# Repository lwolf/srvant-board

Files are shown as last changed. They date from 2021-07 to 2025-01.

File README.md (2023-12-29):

# srvant-board

| :warning: WARNING          |
|:---------------------------|
| This is a work-in-progress. No final board have been produced yet. Any part of the schematic and/or PCB could be wrong.|

Design of the carrier board for the Raspberry Pi CM4. The main distinction from existing boards is the presence of the 
BMC (Baseboard Management Controller) which supposed to monitor and control the HOST, allowing the board to act as a real "server".

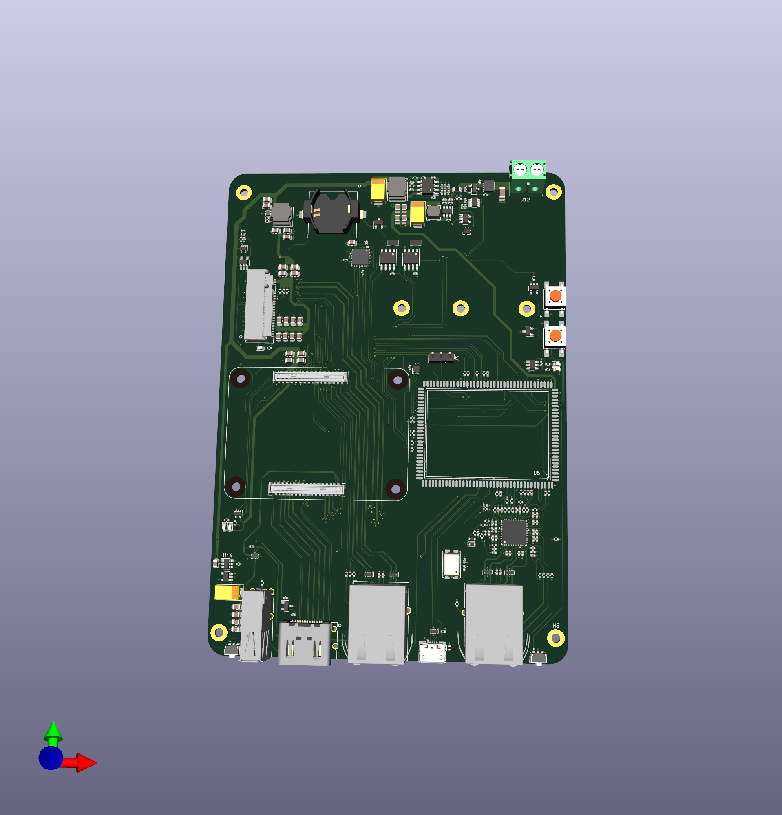
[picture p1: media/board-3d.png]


## Highlevel design / idea:

BMC using lots of GPIO controls the HOST: power cycle, terminal access, switches USB into OTG for flushing.
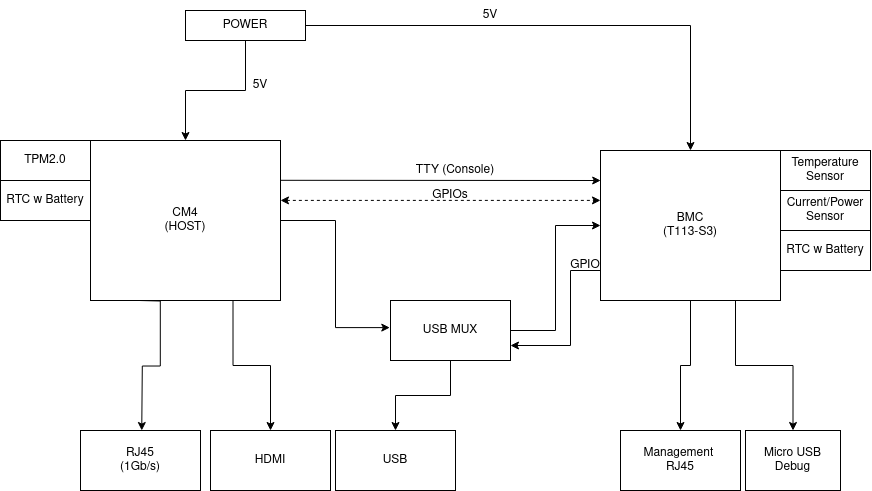
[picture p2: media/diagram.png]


* CM4 (HOST) features:
  * 1Gb/s ethernet
  * HDMI
  * 1 USB
  * PCIe exposed as M.2 socket to connect nvme drive
  * TPM2.0 (OPTIGA™ TPM SLB 9670)
  * RTC with battery
* BMC features:
  * Always ON
  * 1Gb/s management port
  * USB port for debug
  * USB connection to the HOST for flushing
  * I2C connection to the HOST for additional metrics
  * TTY connection to HOST for SOL (Serial over LAN)
  * measures Current/Power of the board
  * measures Temperature of the board
  * controls FAN (not available in the PoC)

BMC is based on the Allwinner T113 S3 SoM [link to aliexpress](https://www.aliexpress.com/item/1005005389129193.html).

### Power

THere are separate 5v rails for host and BMC. The host one is based on AP64501SP (5V 5A), while BMC is based on AP63205WU (5V 2A).
BMC is always on. Host is being powered either by a signal from BMC or by shortening a jumper.

Main power goes through the shunt resistor connected to the power sensor (INA219A). The value is available to BMC using i2c bus.

### Connectors

#### HOST
Host has a following connectors:
* Ethernet
* HDMI
* USB
* M.2 socket M for nvme disk

#### BMC
BMC has a following connectors:
* Ethernet (1GB/s)
* MicroUSB (debug)

### USB

There is a connection between BMC and HOST using USB to allow flushing the HOST remotely.
Since CM4 has only a single usb line, it is connected to the MUX (FSUSB42MUX) 
in a similar way it is done in the CM4IO board, but instead of switching client mode to microUSB, it goes to BMC.

### RTC

RTC is based on PCF85063AT chip. There are two of them, one for each CPU.
Even though t133-s3 has on-board RTC, it is not exposed from the SOM and reference schematic uses external one.
Both chips are powered by 3.3v coming from BMC and coin cell battery.

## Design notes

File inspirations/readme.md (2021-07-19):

olinuxino:
    https://github.com/OLIMEX/OLINUXINO

ttyMAY_linux_board:
    https://github.com/circuitvalley/ttyMAY_linux_board
    https://www.circuitvalley.com/2015/11/homemade-arm-board-running-linux-with.html
    https://www.circuitvalley.com/2015/11/linux-board-homemade-pcb-design-ddr3-schematic-altium.html
    https://www.circuitvalley.com/2015/11/linux-board-homemade-pcb-design-ddr3-schematic-altium.html

related projects:
https://github.com/mebs/CM4-NAS/
https://github.com/mfolejewski/MirkoPC

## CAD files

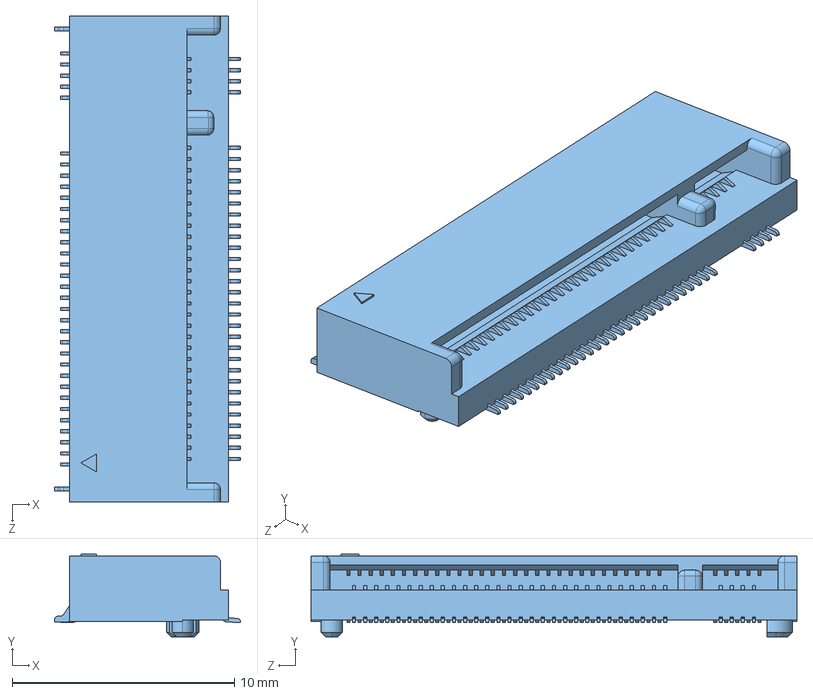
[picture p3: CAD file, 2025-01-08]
kicad/mk2/srvant-mk2/3D/MTSSD03-67MSW337.STEP
8.37 x 3.73 x 21.9 mm

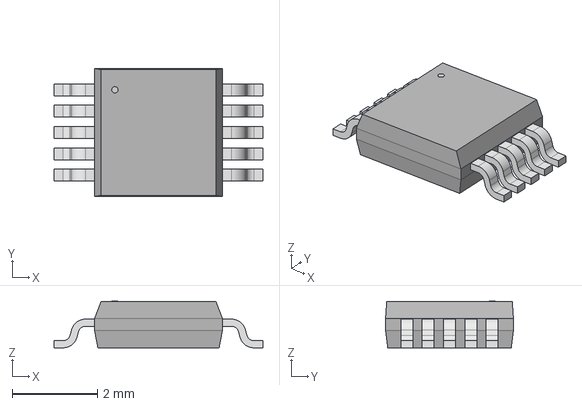
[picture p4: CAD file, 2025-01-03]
kicad/mk2/srvant-mk2/3D/FSUSB42MUX.step
4.90 x 3.00 x 1.09 mm

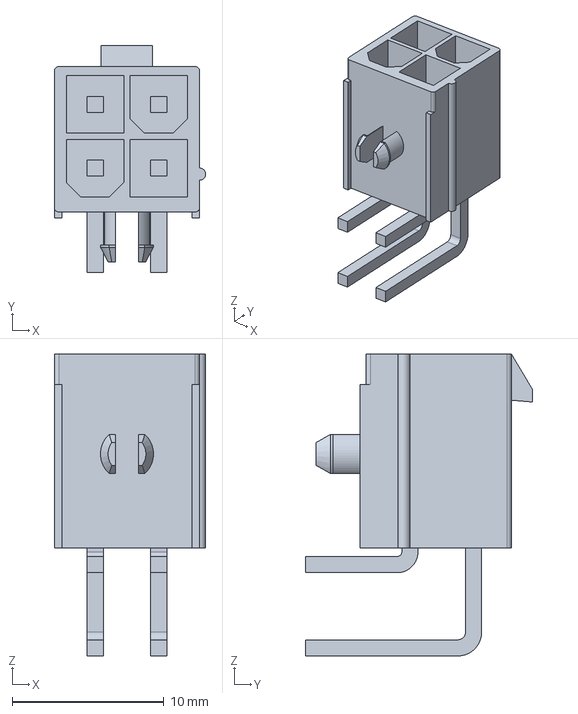
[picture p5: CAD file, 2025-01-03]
kicad/mk2/srvant-mk2/3D/molex_4pin_power.stp
10.0 x 15.0 x 19.9 mm

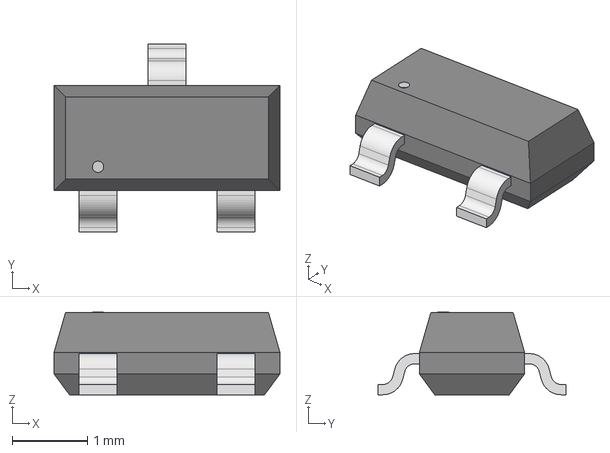
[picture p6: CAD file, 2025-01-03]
kicad/mk2/srvant-mk2/3D/SOT-23_DMP3098LQ_DIO.step
3.00 x 2.49 x 1.09 mm

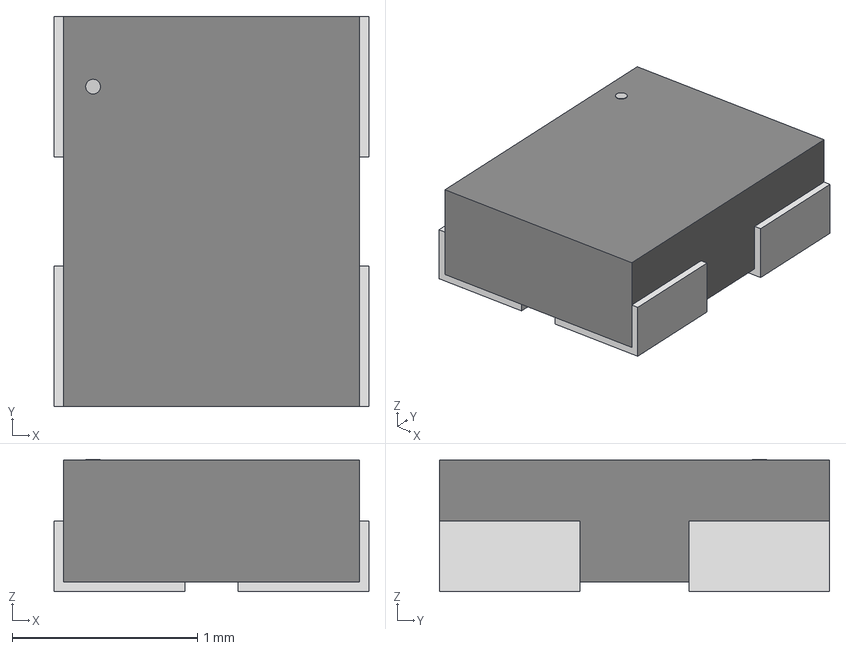
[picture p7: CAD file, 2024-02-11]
kicad/mk2/srvant-mk2/3D/25mhz_70x50quarz.step
1.70 x 2.11 x 0.714 mm

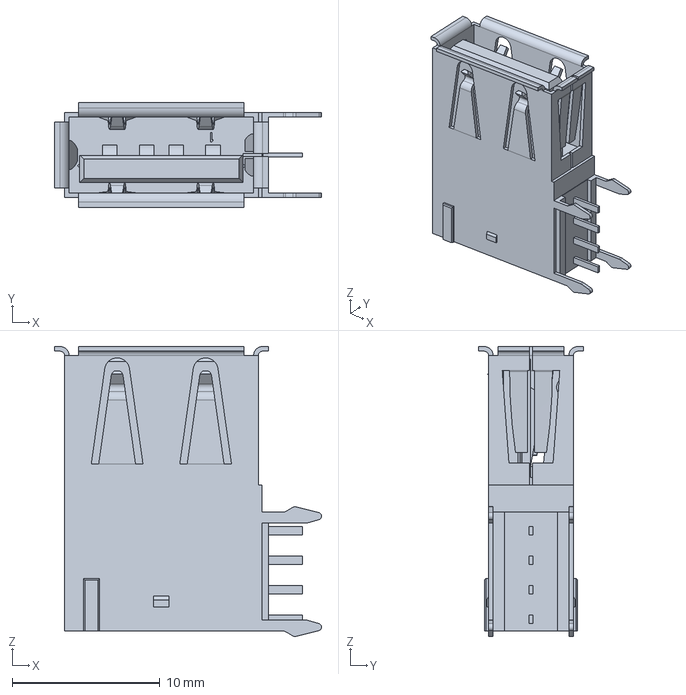
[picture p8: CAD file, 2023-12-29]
kicad/mk2/srvant-mk2/3D/usb-vertical-c-292336-1-b-3d.stp
18.1 x 7.12 x 19.7 mm

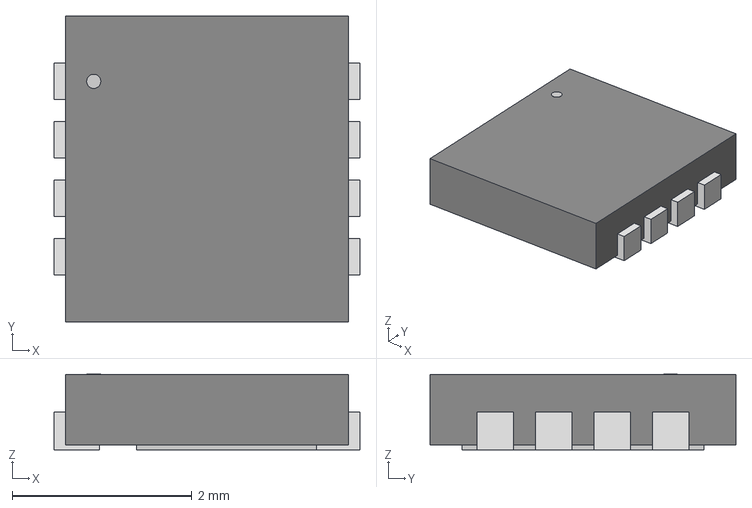
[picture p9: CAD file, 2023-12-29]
kicad/mk2/srvant-mk2/3D/POWERDI3333-8_UX_DIO.step
3.40 x 3.40 x 0.841 mm

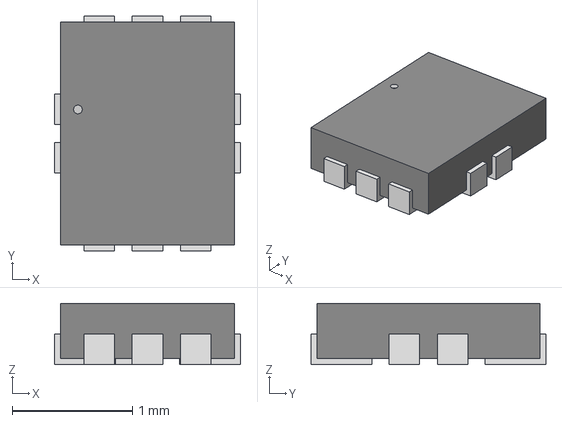
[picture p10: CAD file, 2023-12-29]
kicad/mk2/srvant-mk2/3D/usbmux_UQFN10_ONS.step
1.55 x 1.96 x 0.511 mm

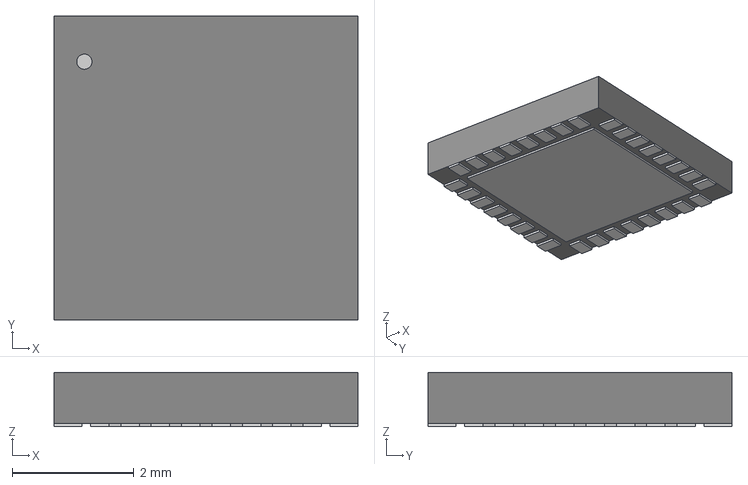
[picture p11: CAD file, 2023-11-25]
kicad/mk2/srvant-mk2/3D/QFN32_SLB9670VQ20FW785XTMA1_INF.step
5.00 x 5.00 x 0.892 mm

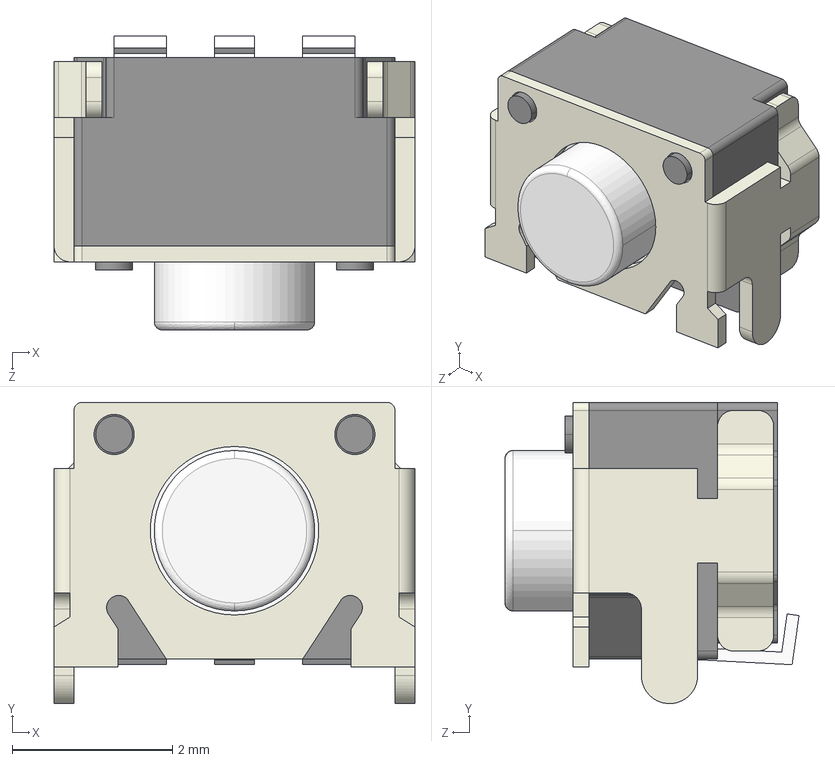
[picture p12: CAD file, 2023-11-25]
kicad/mk2/srvant-mk2/3D/button-TL3340AF160QG.step
4.50 x 3.76 x 3.67 mm

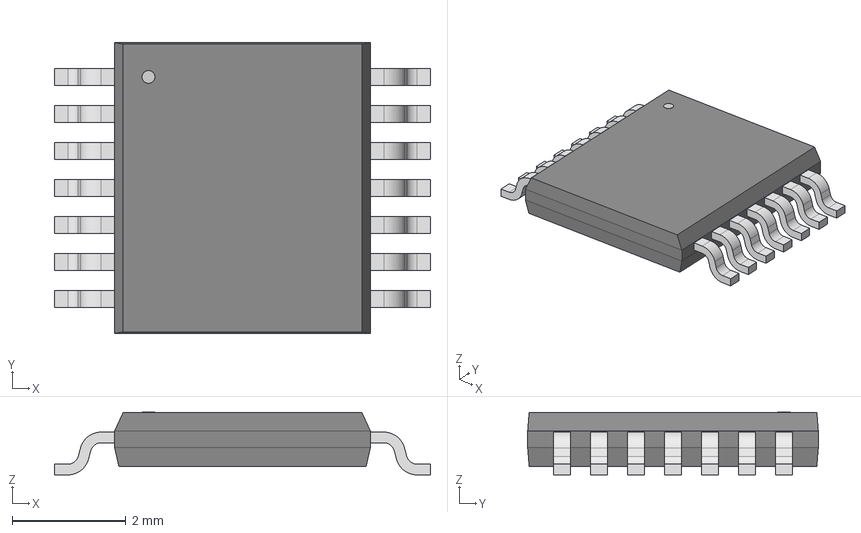
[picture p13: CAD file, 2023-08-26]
kicad/mk2/srvant-mk2/3D/SOT402-1_NEX.step
6.60 x 5.11 x 1.10 mm

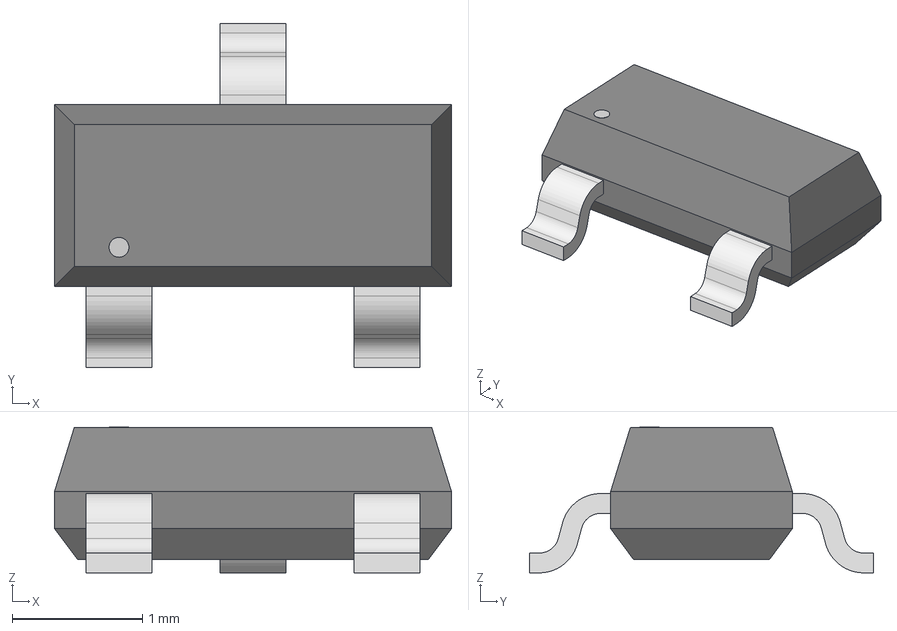
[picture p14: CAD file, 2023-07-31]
kicad/mk2/srvant-mk2/3D/SOT-23-3_1P4X3P040_ONS.step
3.05 x 2.64 x 1.12 mm

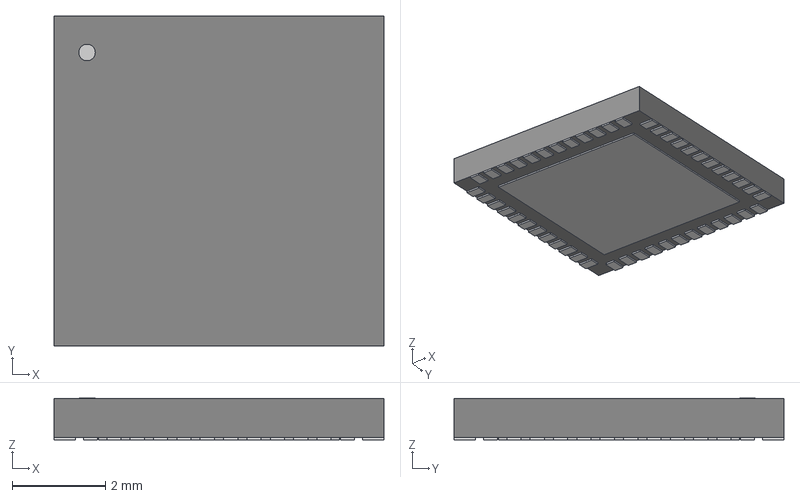
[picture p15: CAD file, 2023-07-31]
kicad/mk2/srvant-mk2/3D/QFN48_NX_MCH.step
7.06 x 7.06 x 0.892 mm

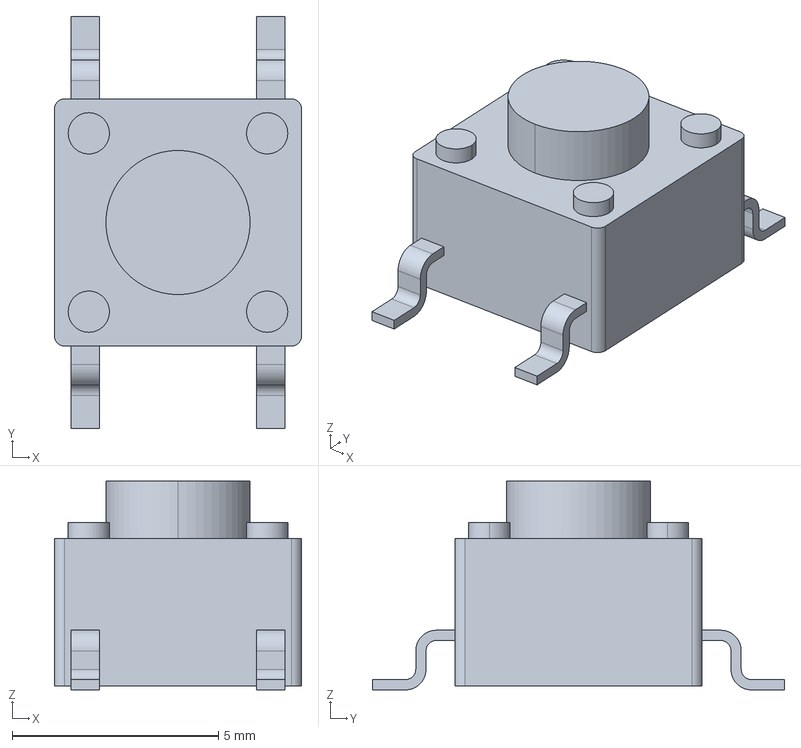
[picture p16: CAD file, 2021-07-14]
kicad/mk2/srvant-mk2/3D/button-c-1571563-4-v-3d.stp
6.00 x 10.0 x 5.07 mm

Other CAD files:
kicad/mk2/srvant-mk2/3D/RJ45-c-5-2337992-3-a-3d.stp
kicad/mk2/srvant-mk2/3D/TLV62585DRLR-DRL0006A.stp
kicad/mk2/srvant-mk2/3D/m2-2199230-5-b2-3d.stp

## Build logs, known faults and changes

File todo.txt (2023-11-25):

todo:
* calculate RShunt for the INA129
* [x] add RTC chip for RPI
* ETHERNET: 25M crystal or the clock from the CPU
* Do I want to add sdcard to BMC?

USB:
* [x] connect USB pins for OTG: nFault,DRV in usb (removed the power chip)
* [x] Do i need to keep BMC and HOST disconnected? (demux solves this)
* [X] connect USB_DEBUX_SELECT to GPIO on BMC
* [x] Since I don't use usb connector, I need to somehow emulate ID pin on BMC (yes, BMC_HOST_DEMUX_CONTROL)

---------
* [x] add a thermo sensors
* add FAN control ?
* [x] RTC for rpi
* NOR Flash?
* Fuse?
* [x] Drop usb hub
* [x] replace USB port with vertical one
* replace HDMI port with vertical one
* experiment with placement and form factor. is it possible/worth making 1U with 2 side placement
* [x] add RC filter to each bmc-host pin (only 0r for now
* [x] led for bmc power

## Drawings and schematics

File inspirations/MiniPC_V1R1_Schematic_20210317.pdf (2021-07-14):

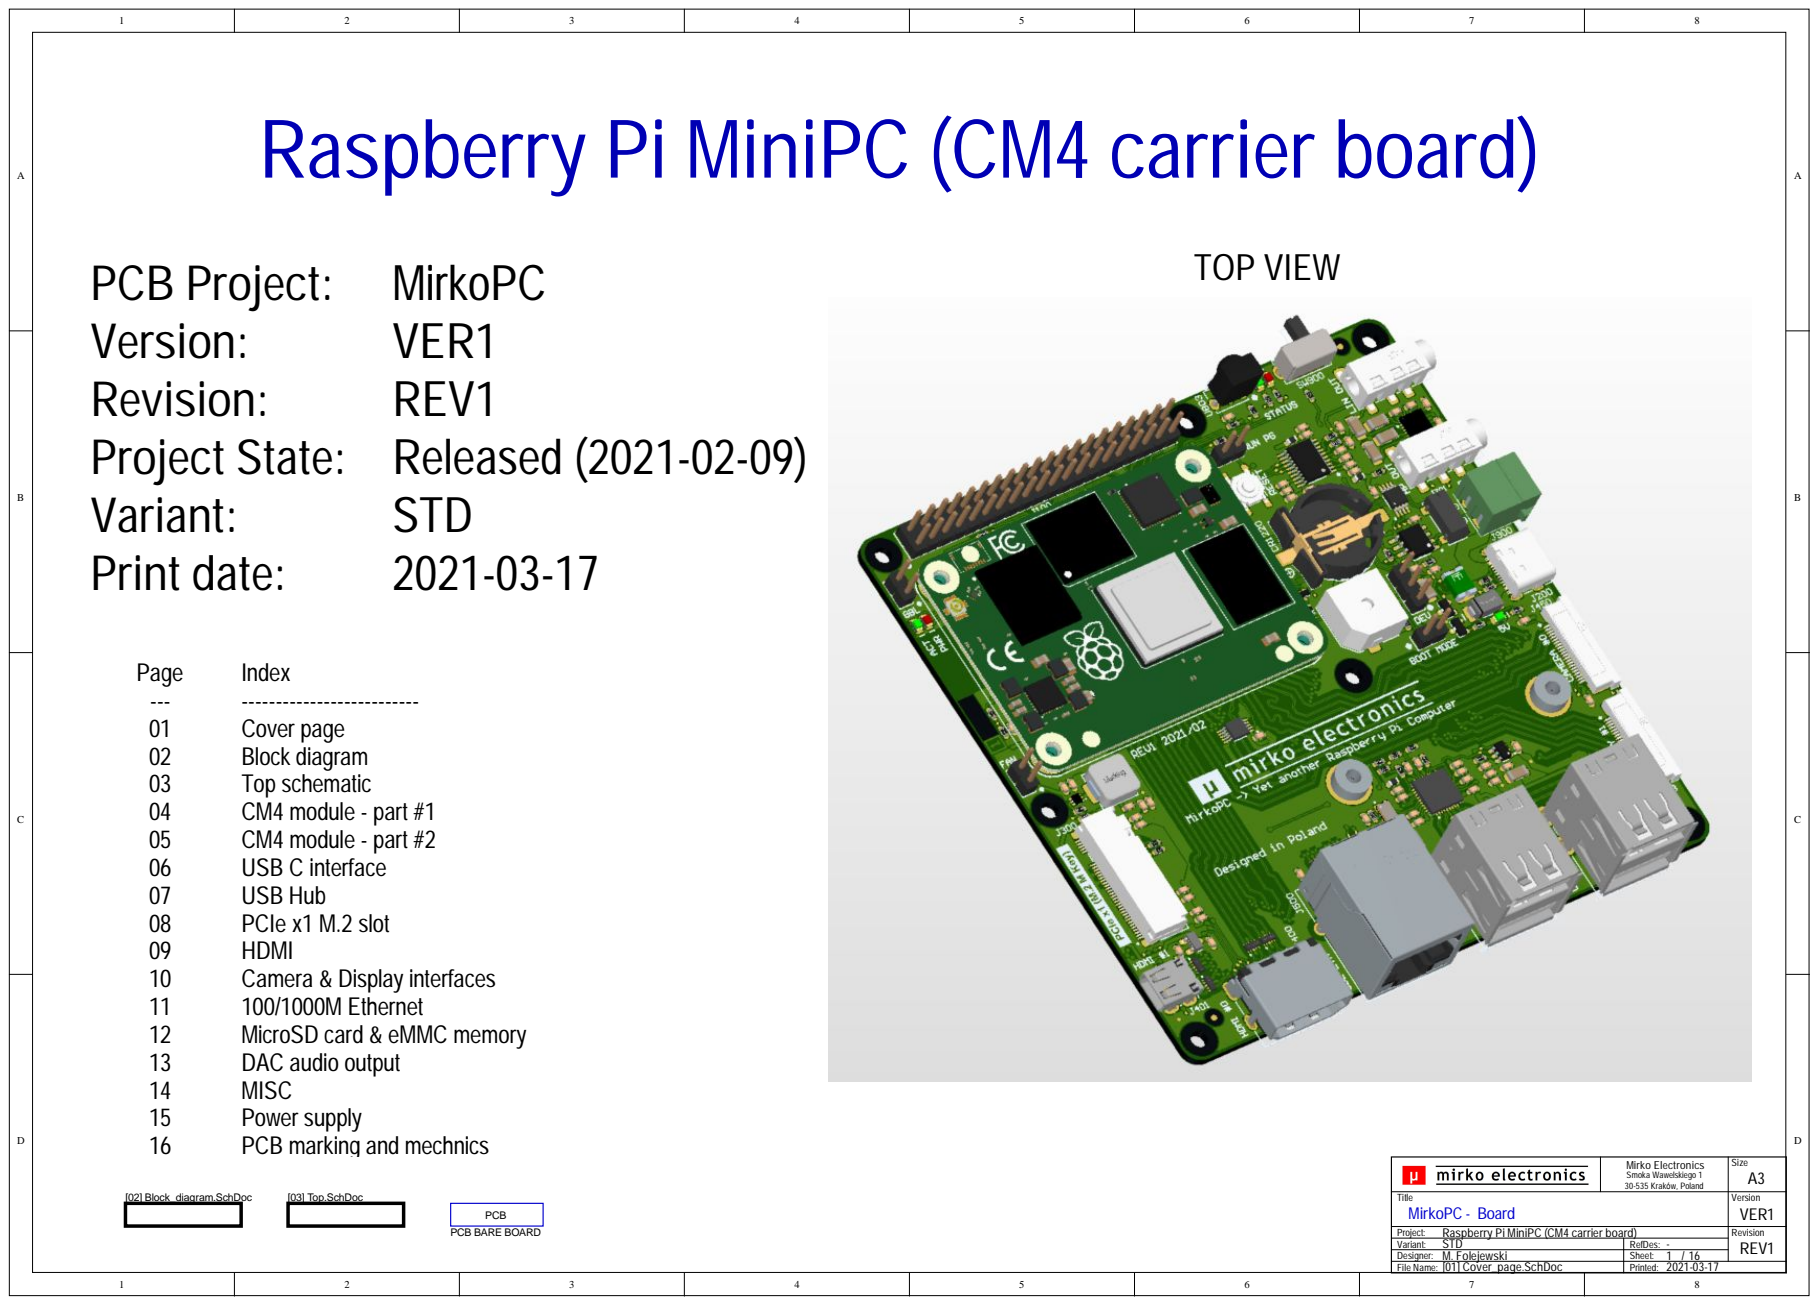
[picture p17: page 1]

Index
Cover page
Block diagram
Top schematic
CM4 module - part #1
CM4 module - part #2
USB C interface
USB Hub
PCIe x1 M.2 slot
HDMI
Camera & Display interfaces
100/1000M Ethernet
MicroSD card & eMMC memory
DAC audio output
MISC
Power supply
PCB marking and mechnics

Mirko Electronics Smoka Wawelskiego 1 30-535 Kraków, Poland | Size A3

Title MirkoPC - Board | | Version VER1

Revision REV1
Variant: STD
Designer: M. Folejewski
File Name: [01] Cover_page.SchDoc | Printed:

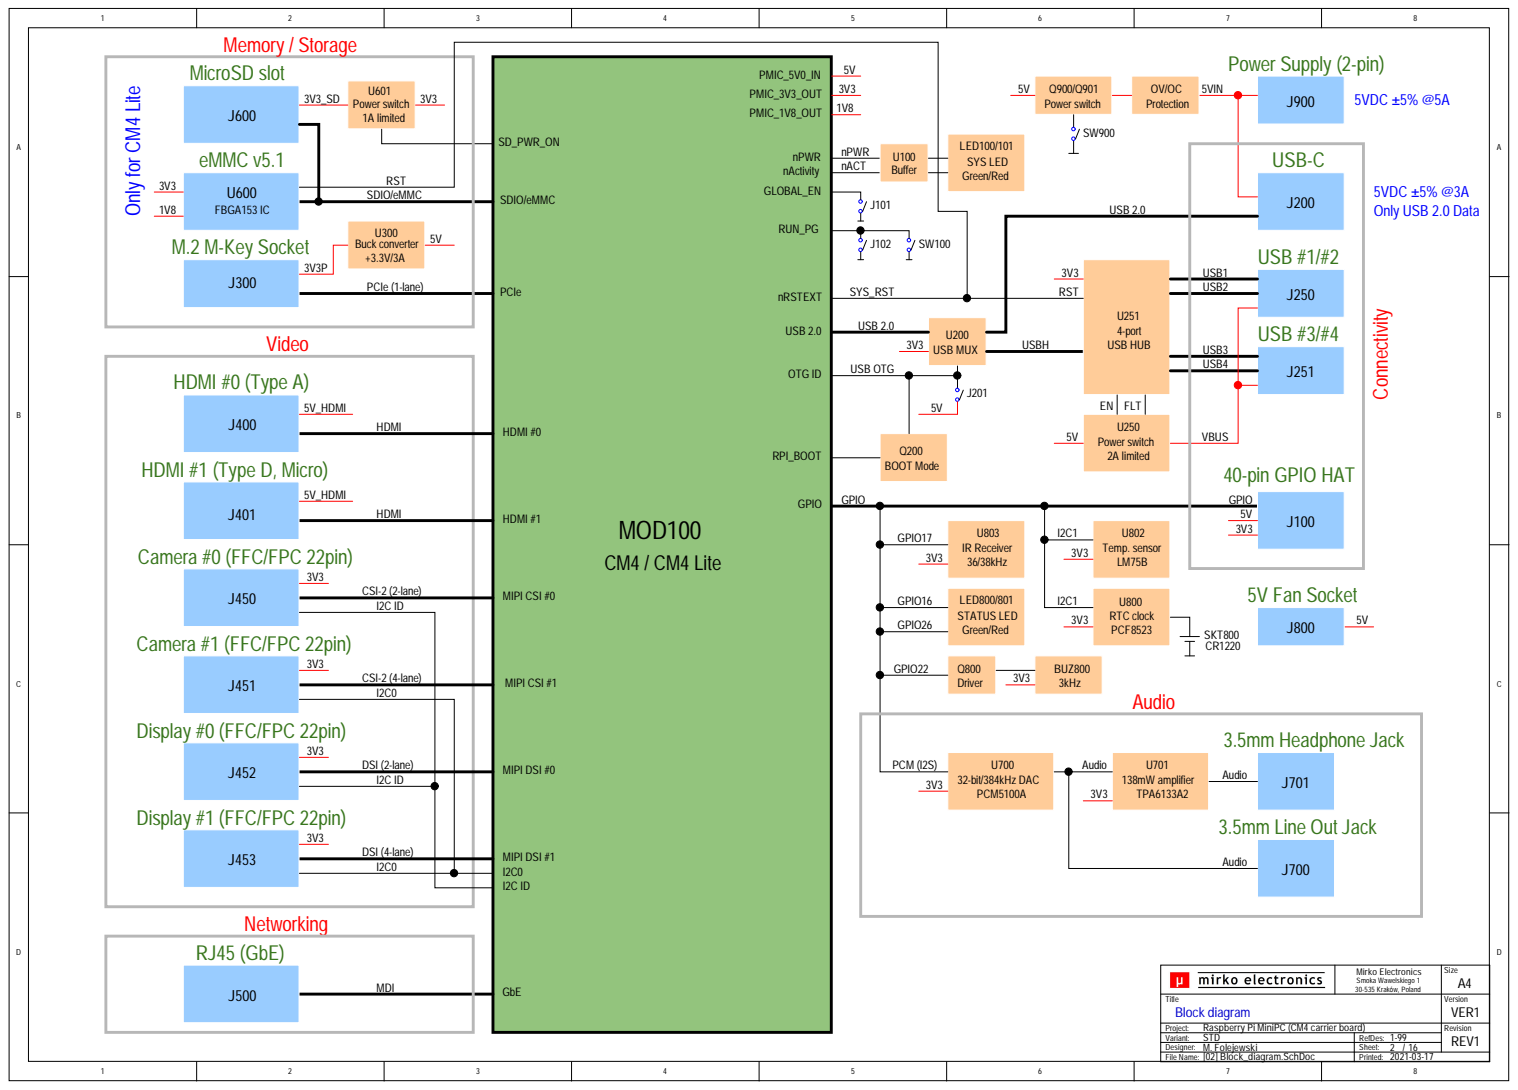
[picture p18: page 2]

RST
SDIO/eMMC

USB OTG OTG ID

MIPI CSI #0 CSI-2 (2-lane) J450

3V3 | MIPI CSI #1 CSI-2 (4-lane) J451

3V3 | MIPI DSI #0 DSI (2-lane) J452

MIPI DSI #1 DSI (4-lane) J453

Mirko Electronics Smoka Wawelskiego 1 30-535 Kraków, Poland | Size A4

Title Block diagram | | Version VER1

Revision REV1
Variant: STD

File Name: [02] Block_diagram.SchDoc | Printed:

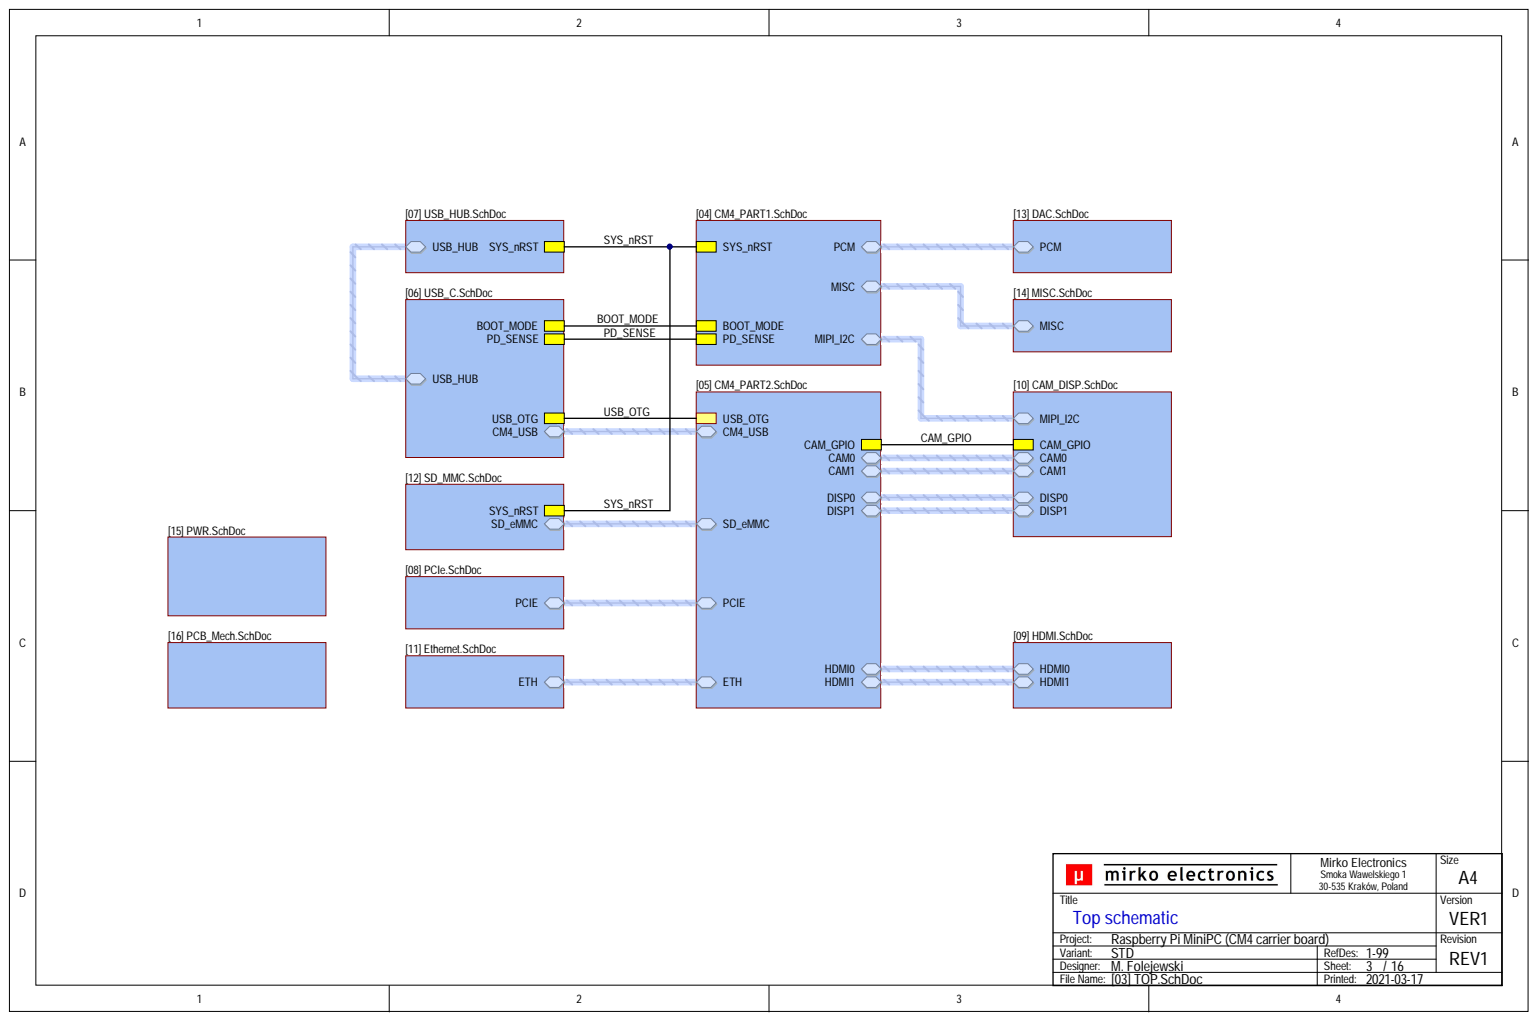
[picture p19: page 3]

BOOT_MODE
PD_SENSE

Mirko Electronics Smoka Wawelskiego 1 30-535 Kraków, Poland | Size A4

Title Top schematic | | Version VER1

Project: Raspberry Pi MiniPC (CM4 carrier board) | | Revision REV1
Variant: STD | RefDes: 1-99

Sheet: 3 16 /

File Name: [03] TOP.SchDoc | Printed: 2021-03-17

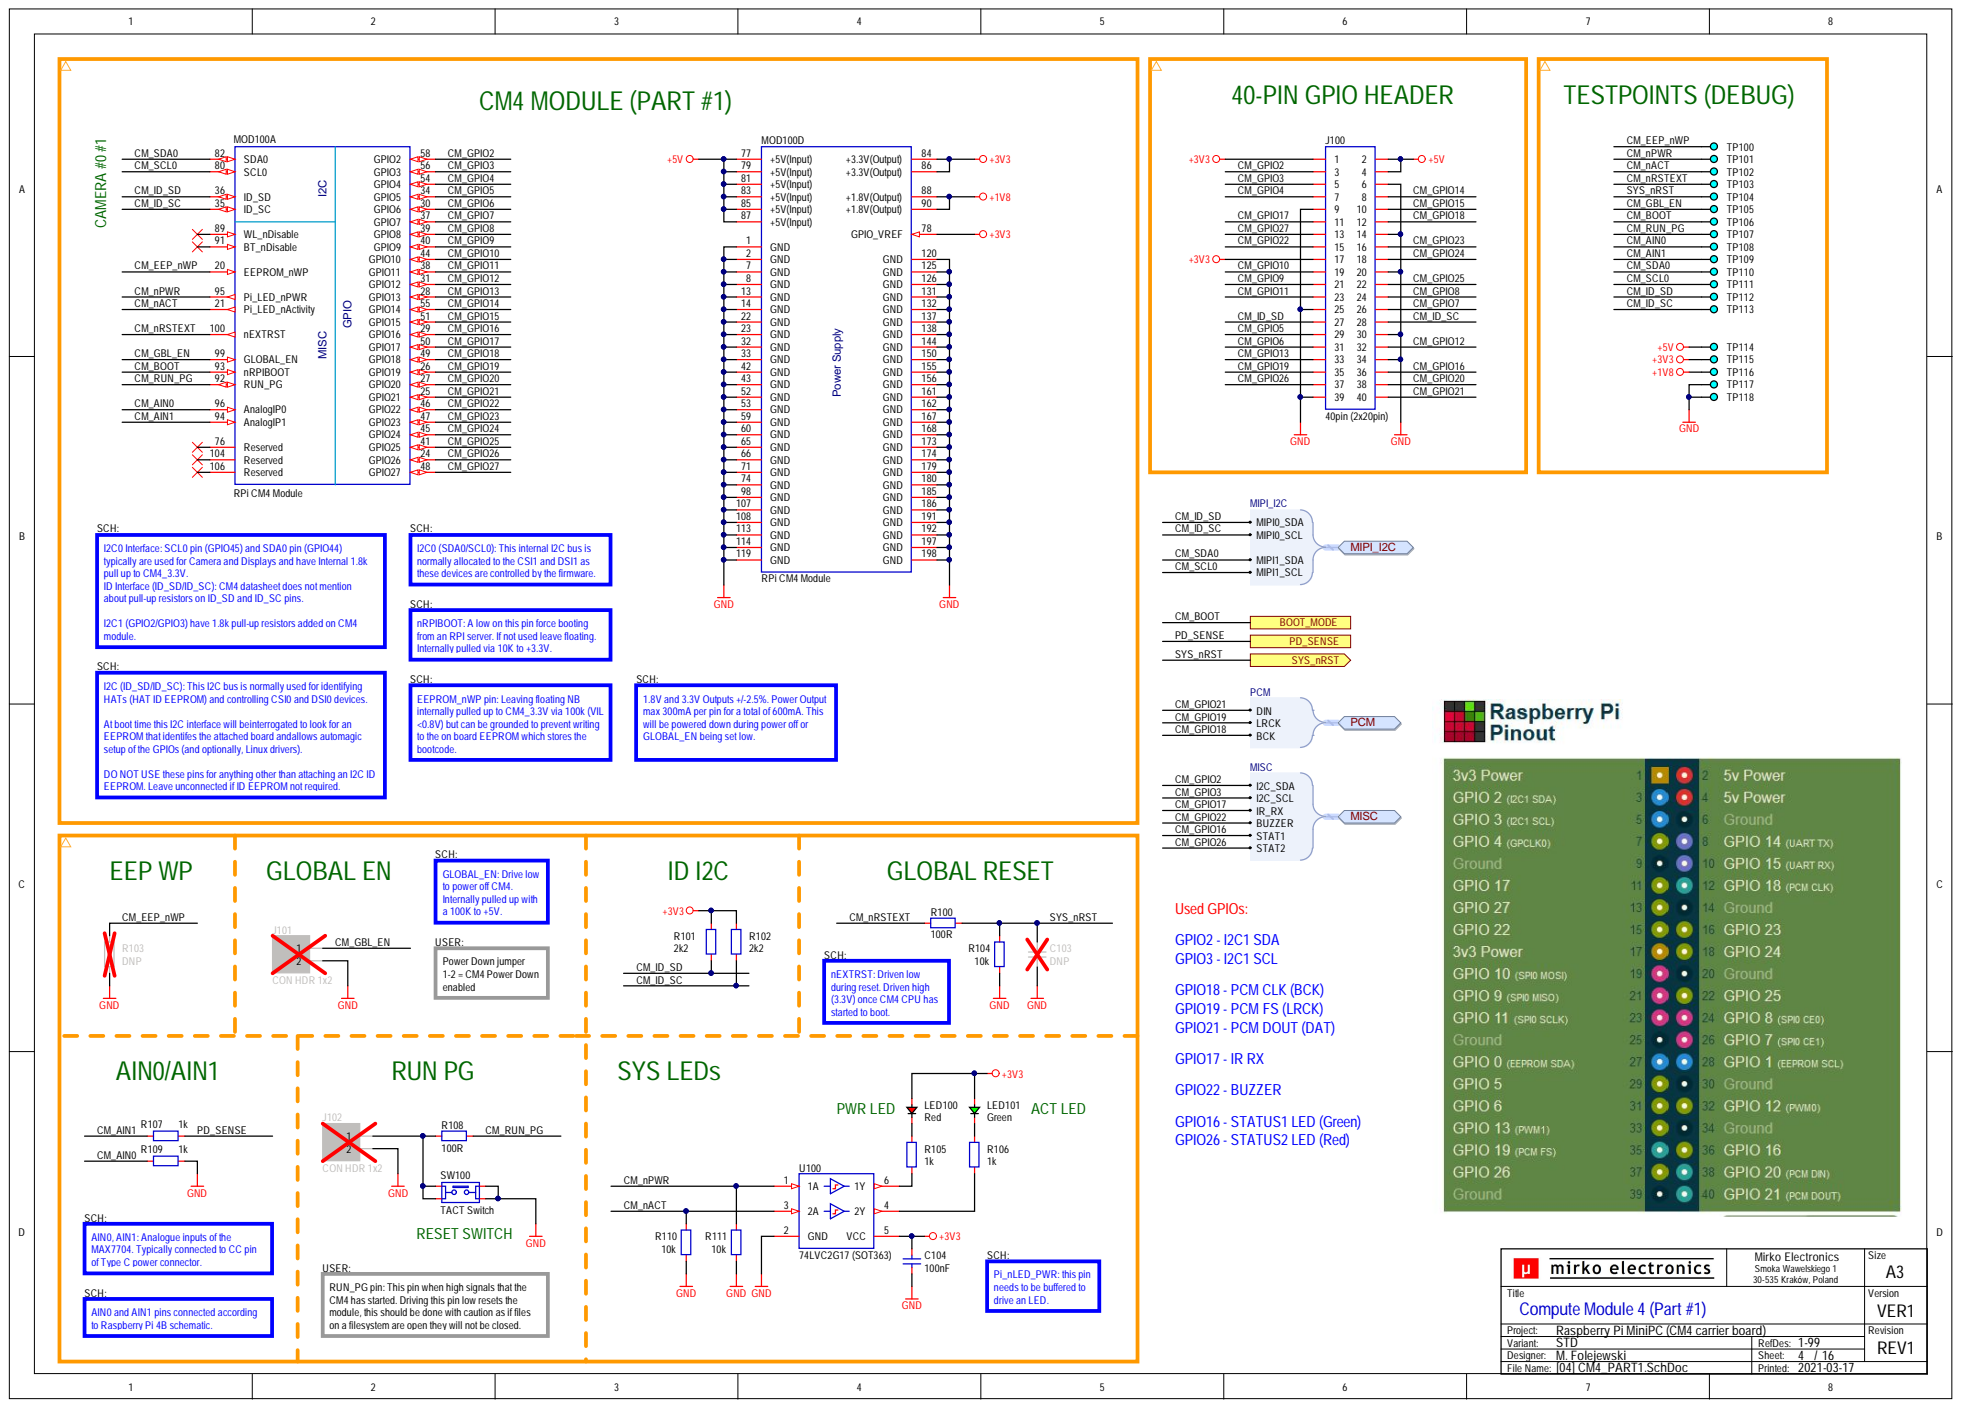
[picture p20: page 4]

SCH:
I2C0 Interface: SCL0 pin (GPIO45) and SDA0 pin (GPIO44)
typically are used for Camera and Displays and have Internal 1.8k
pull up to CM4_3.3V.
ID Interface (ID_SD/ID_SC): CM4 datasheet does not mention
about pull-up resistors on ID_SD and ID_SC pins.

I2C0 (SDA0/SCL0): This internal I2C bus is
normally allocated to the CSI1 and DSI1 as
these devices are controlled by the firmware.

nRPIBOOT: A low on this pin force booting
from an RPI server. If not used leave floating.
Internally pulled via 10K to +3.3V.

I2C1 (GPIO2/GPIO3) have 1.8k pull-up resistors added on CM4
module.

I2C (ID_SD/ID_SC): This I2C bus is normally used for identifying
HATs (HAT ID EEPROM) and controlling CSI0 and DSI0 devices.

EEPROM_nWP pin: Leaving floating NB
internally pulled up to CM4_3.3V via 100k (VIL
<0.8V) but can be grounded to prevent writing
to the on board EEPROM which stores the
bootcode.

1.8V and 3.3V Outputs +/-2.5%. Power Output
max 300mA per pin for a total of 600mA. This
will be powered down during power off or
GLOBAL_EN being set low.

At boot time this I2C interface will beinterrogated to look for an
EEPROM that identifes the attached board andallows automagic
setup of the GPIOs (and optionally, Linux drivers).

DO NOT USE these pins for anything other than attaching an I2C ID
EEPROM. Leave unconnected if ID EEPROM not required.

GLOBAL_EN: Drive low
to power off CM4.
Internally pulled up with

nEXTRST: Driven low
during reset. Driven high
(3.3V) once CM4 CPU has
started to boot.

AIN0, AIN1: Analogue inputs of the
MAX7704. Typically connected to CC pin
of Type C power connector.

Pi_nLED_PWR: this pin
needs to be buffered to
drive an LED.

Mirko Electronics Smoka Wawelskiego 1 30-535 Kraków, Poland | Size A3

USER:
RUN_PG pin: This pin when high signals that the
CM4 has started. Driving this pin low resets the
module, this should be done with caution as if files
on a filesystem are open they will not be closed.

AIN0 and AIN1 pins connected according
to Raspberry Pi 4B schematic.

Title Compute Module 4 (Part #1) | | Version VER1

Revision REV1
Variant: STD

File Name: [04] CM4_PART1.SchDoc | Printed:

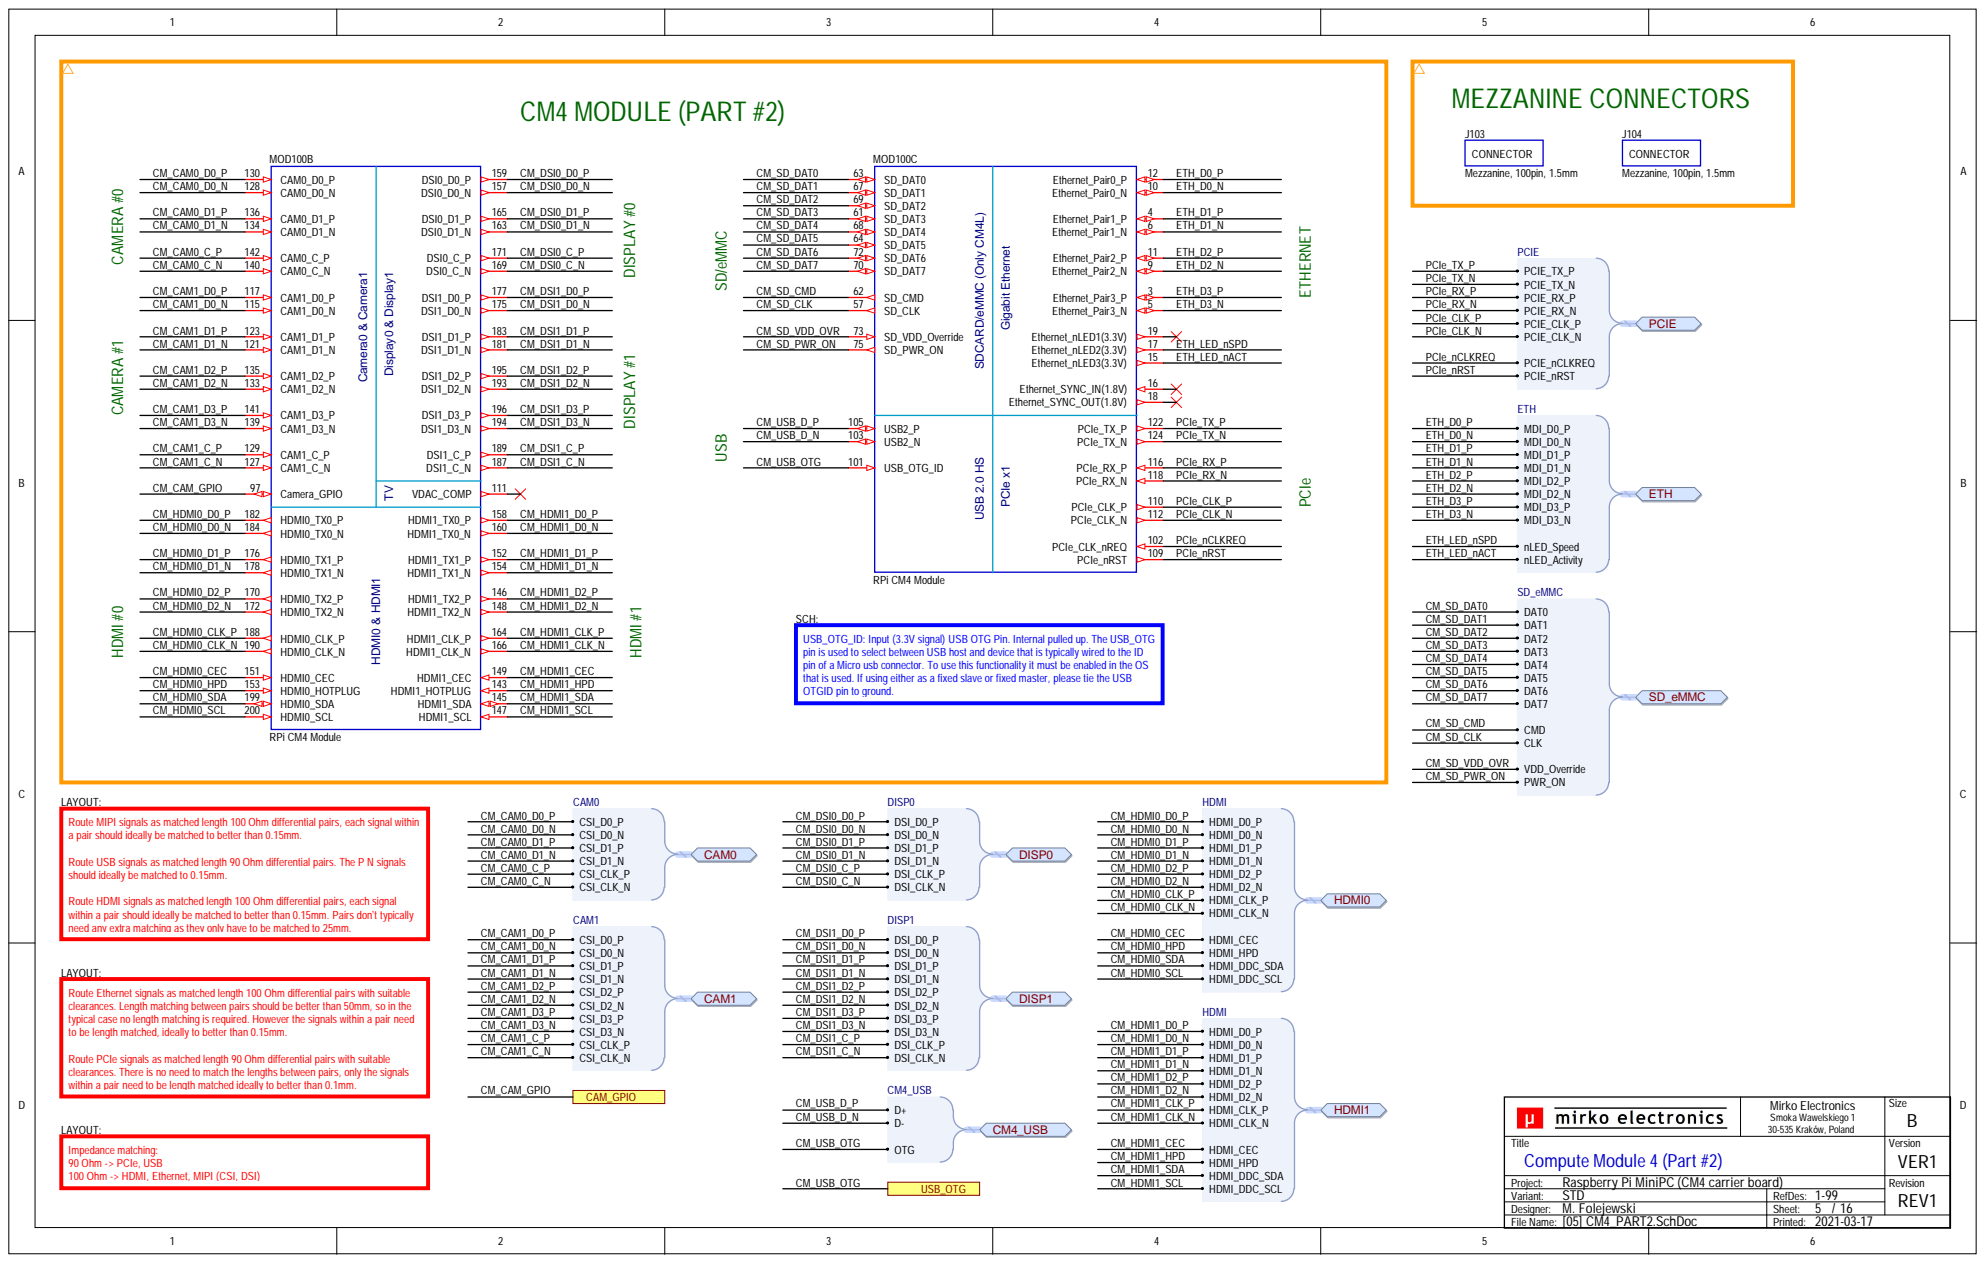
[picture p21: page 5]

SDCARD/eMMC (Only CM4L) USB 2.0 HS

SCH:
USB_OTG_ID: Input (3.3V signal) USB OTG Pin. Internal pulled up. The USB_OTG
pin is used to select between USB host and device that is typically wired to the ID
pin of a Micro usb connector. To use this functionality it must be enabled in the OS
that is used. If using either as a fixed slave or fixed master, please tie the USB
OTGID pin to ground.

LAYOUT:
Route MIPI signals as matched length 100 Ohm differential pairs, each signal within
a pair should ideally be matched to better than 0.15mm.

Route USB signals as matched length 90 Ohm differential pairs. The P N signals
should ideally be matched to 0.15mm.

Route HDMI signals as matched length 100 Ohm differential pairs, each signal
within a pair should ideally be matched to better than 0.15mm. Pairs don’t typically
need any extra matching as they only have to be matched to 25mm.
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

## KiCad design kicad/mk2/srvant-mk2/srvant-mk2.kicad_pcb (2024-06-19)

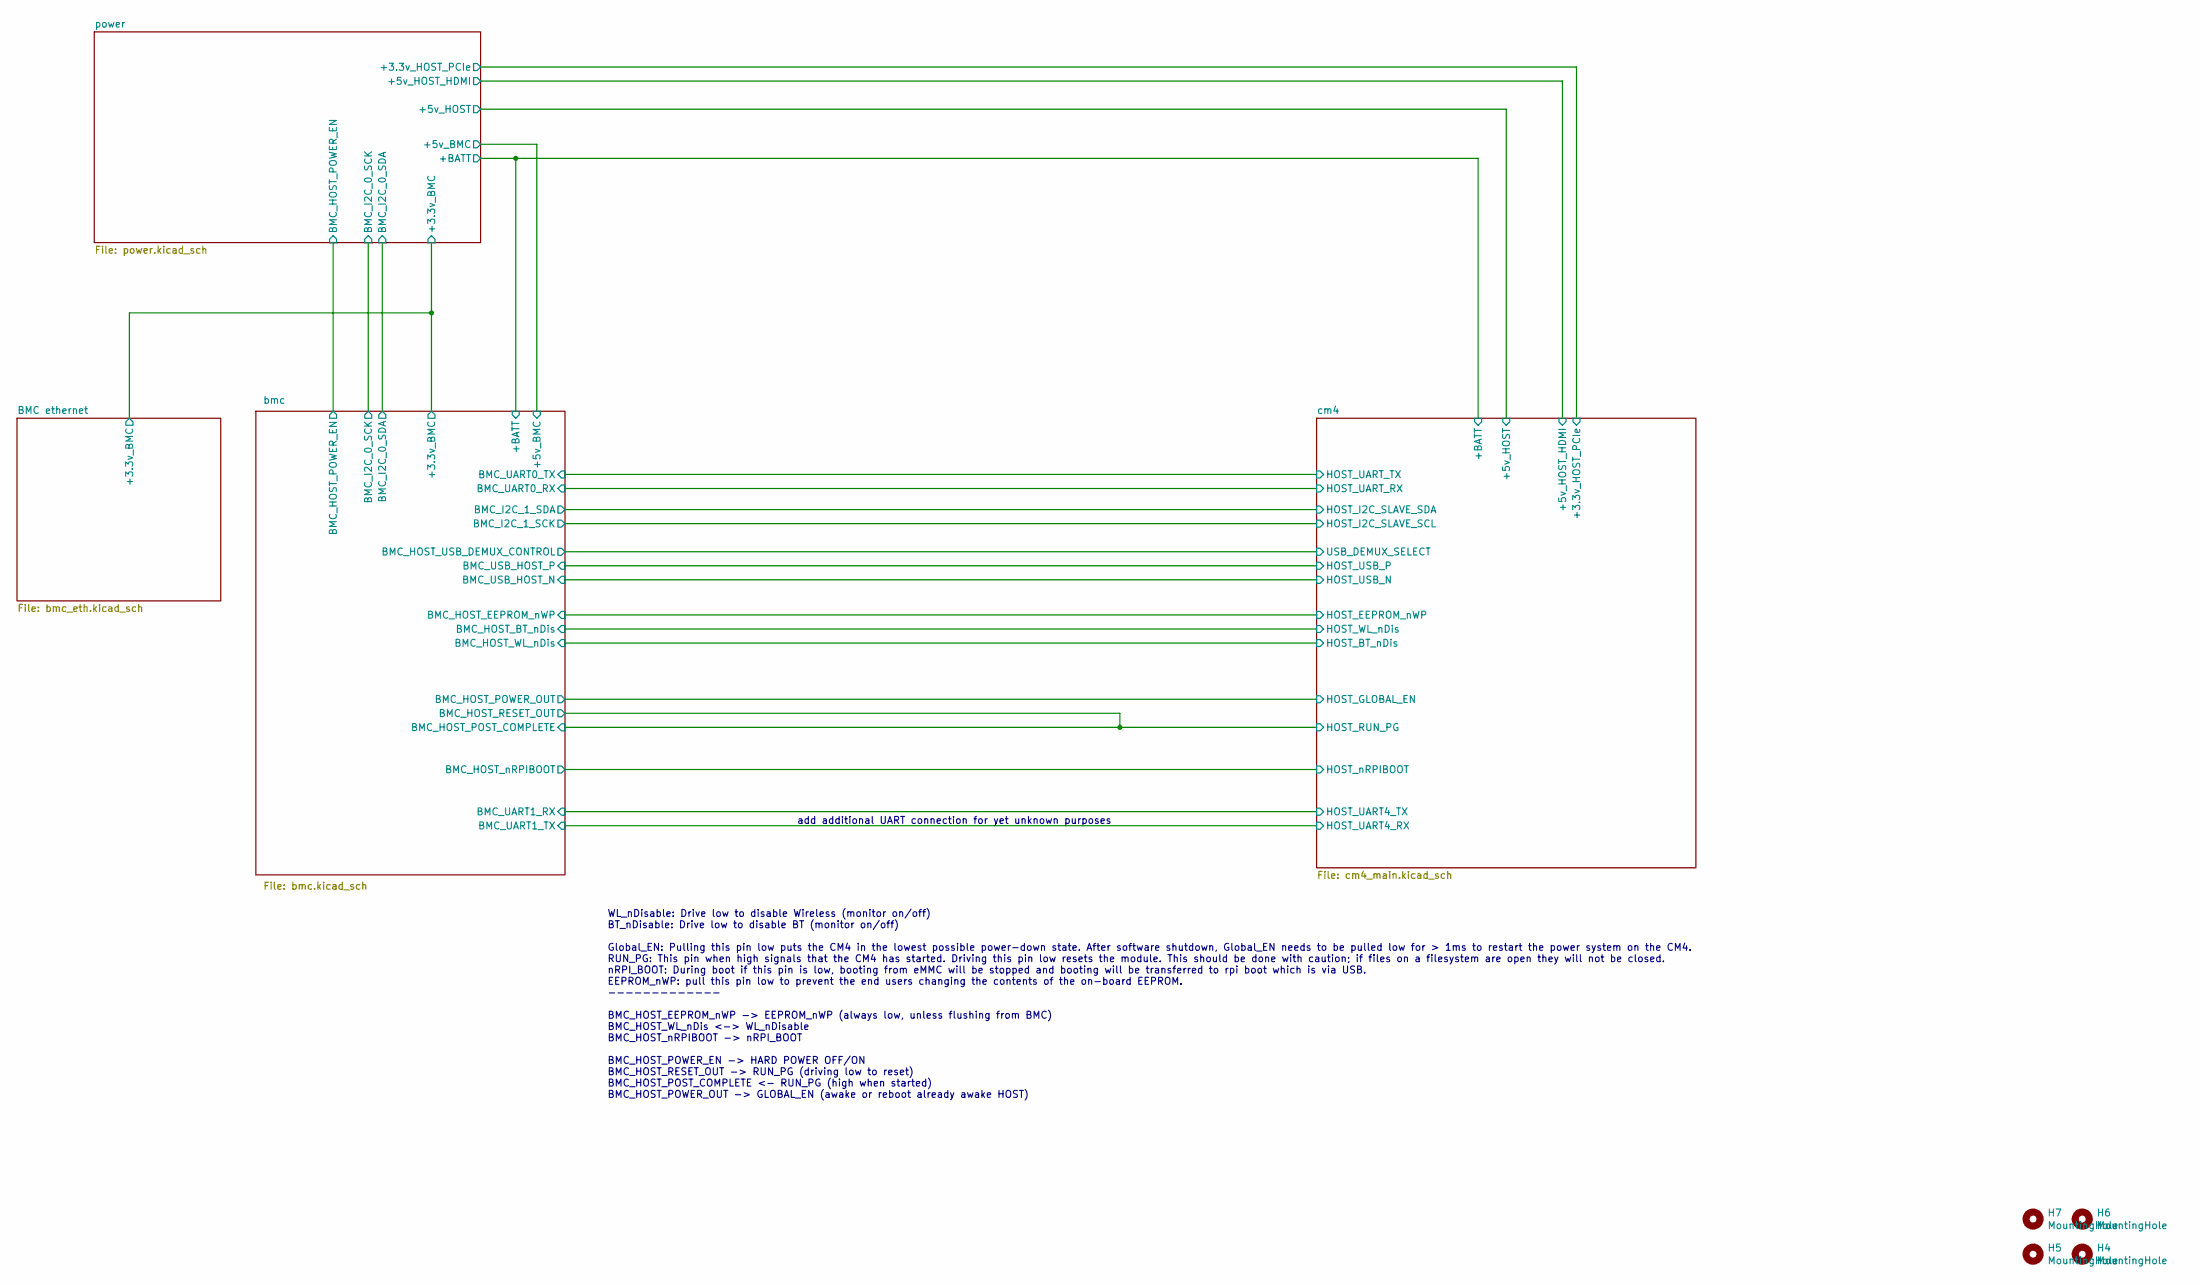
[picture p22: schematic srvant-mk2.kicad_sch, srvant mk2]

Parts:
H4, H5, H6, H7: MountingHole; MountingHole_2.5mm_Pad_TopOnly; Part Description M2.5 mounting hole

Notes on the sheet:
WL_nDisable: Drive low to disable Wireless (monitor on/off) BT_nDisable: Drive low to disable BT (monitor on/off) Global_EN: Pulling this pin low puts the CM4 in the lowest possible power-down state. After software shutdown, Global_EN needs to be pulled low for > 1ms to restart the power system on 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
add additional UART connection for yet unknown purposes

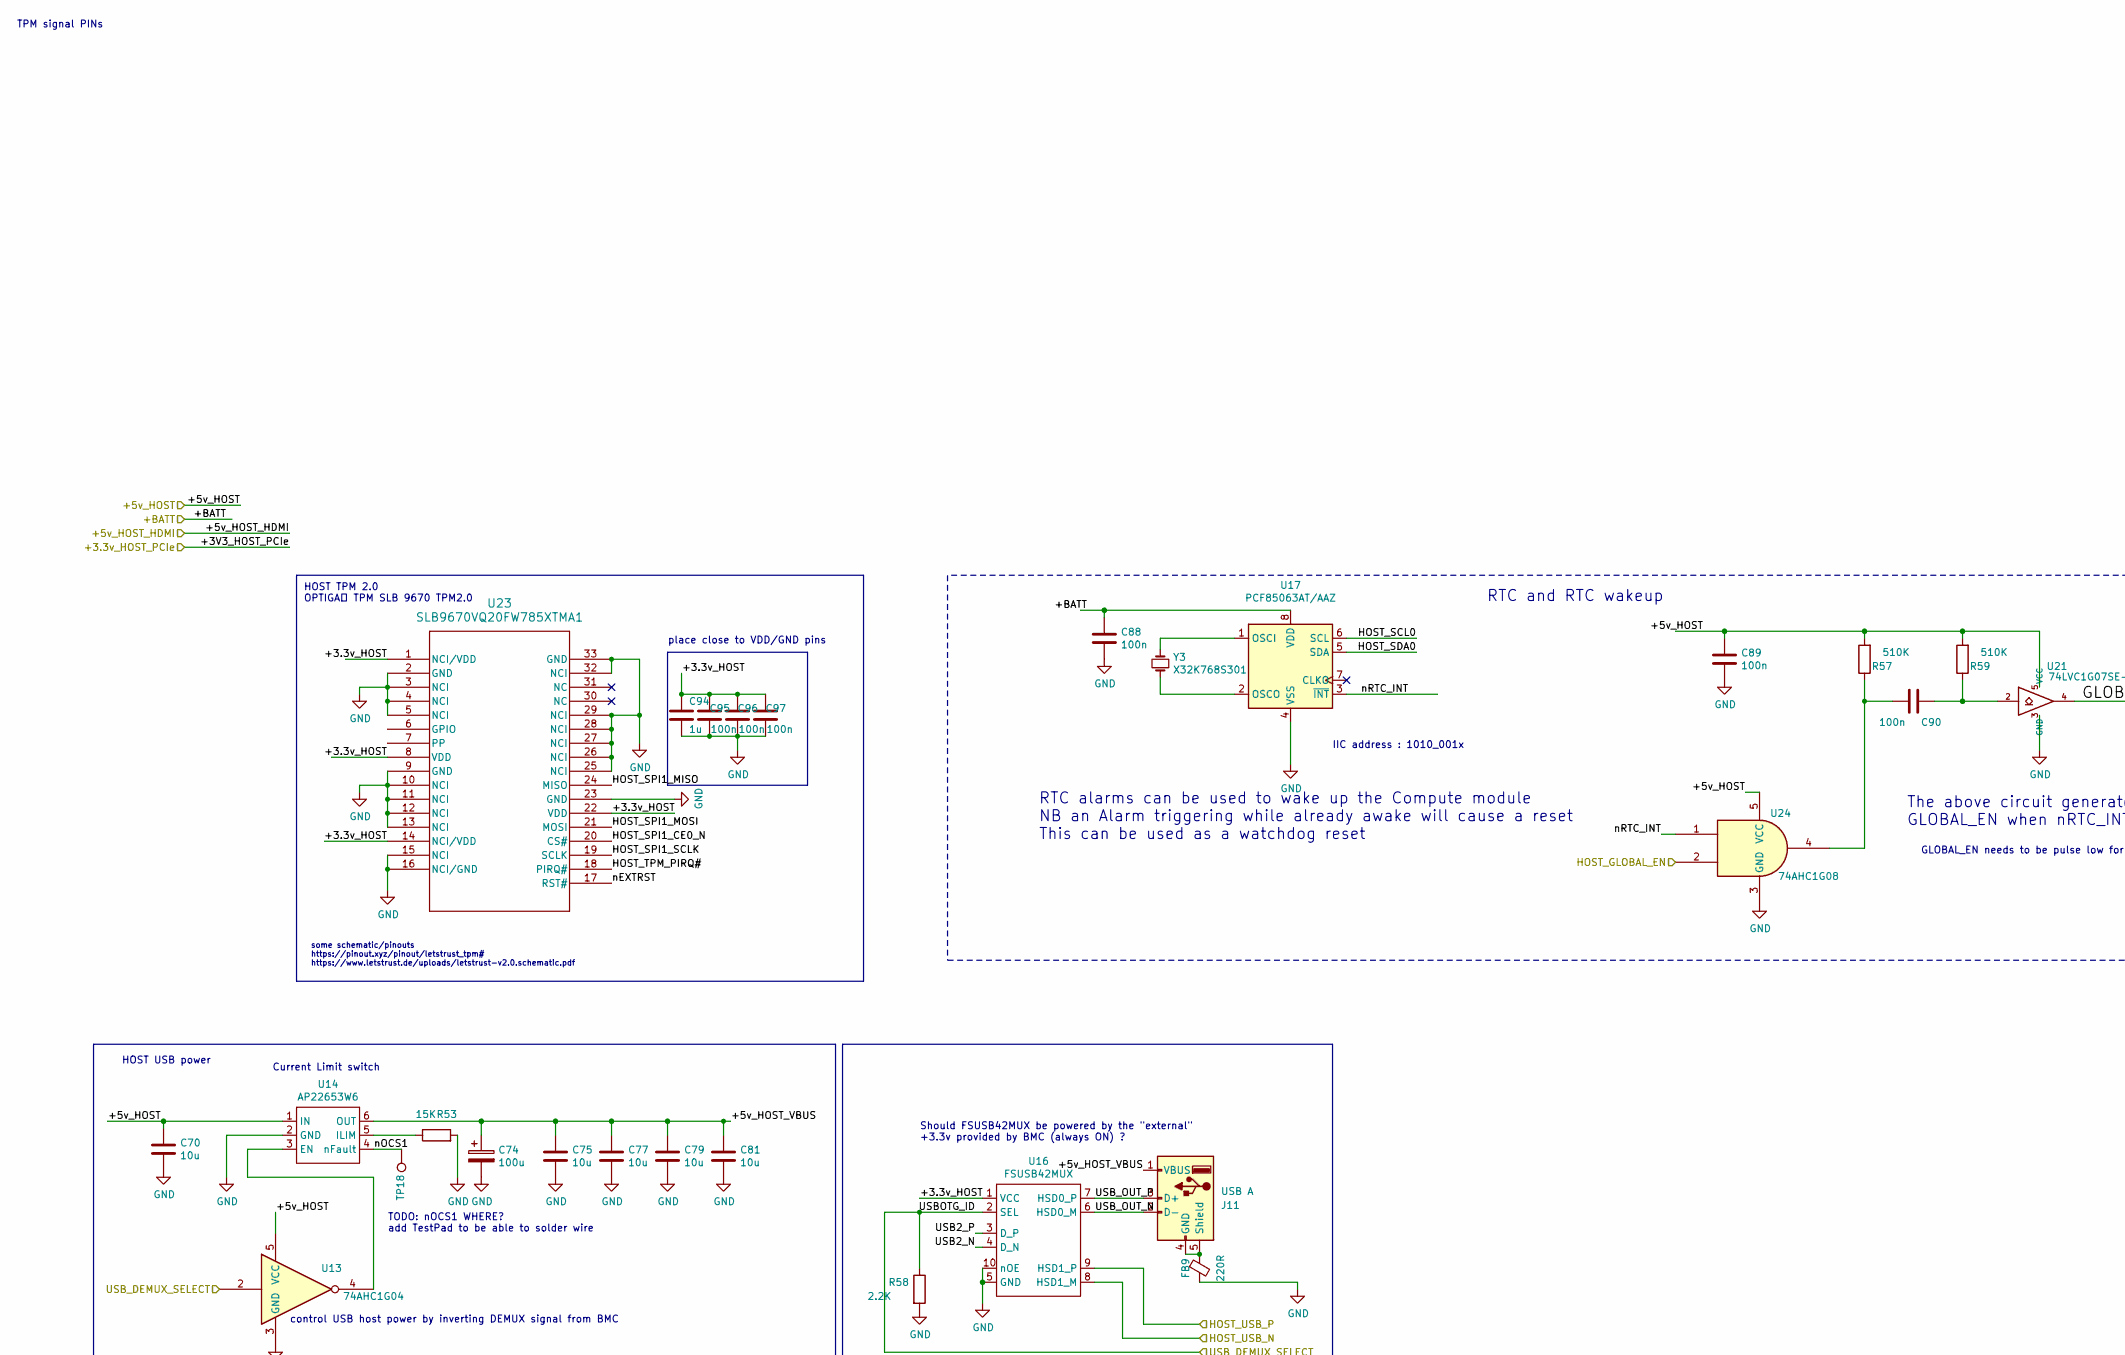
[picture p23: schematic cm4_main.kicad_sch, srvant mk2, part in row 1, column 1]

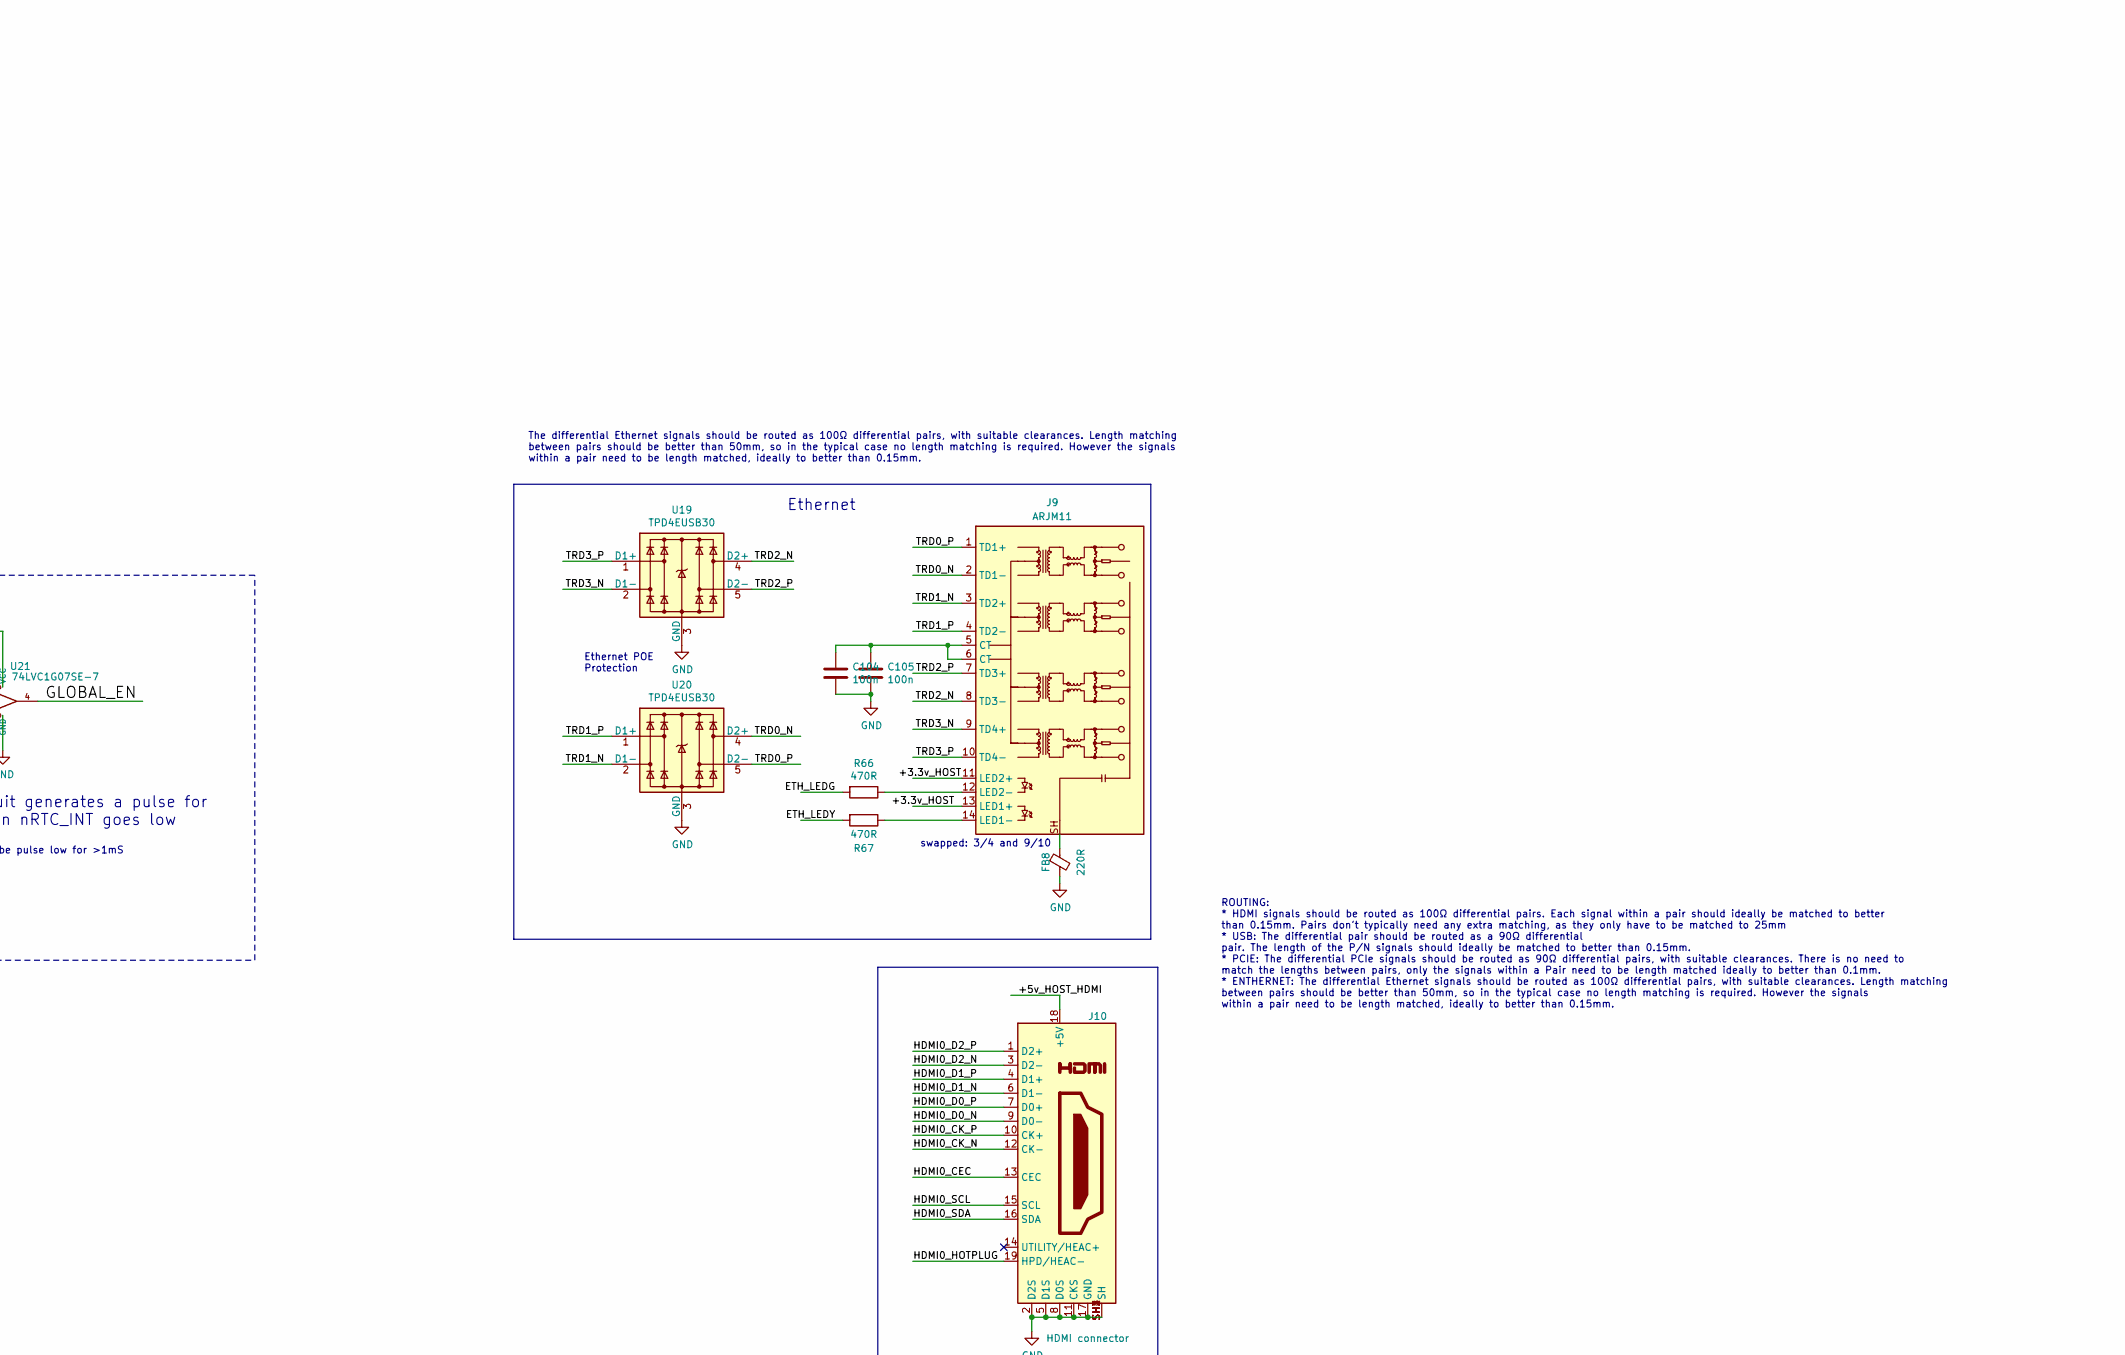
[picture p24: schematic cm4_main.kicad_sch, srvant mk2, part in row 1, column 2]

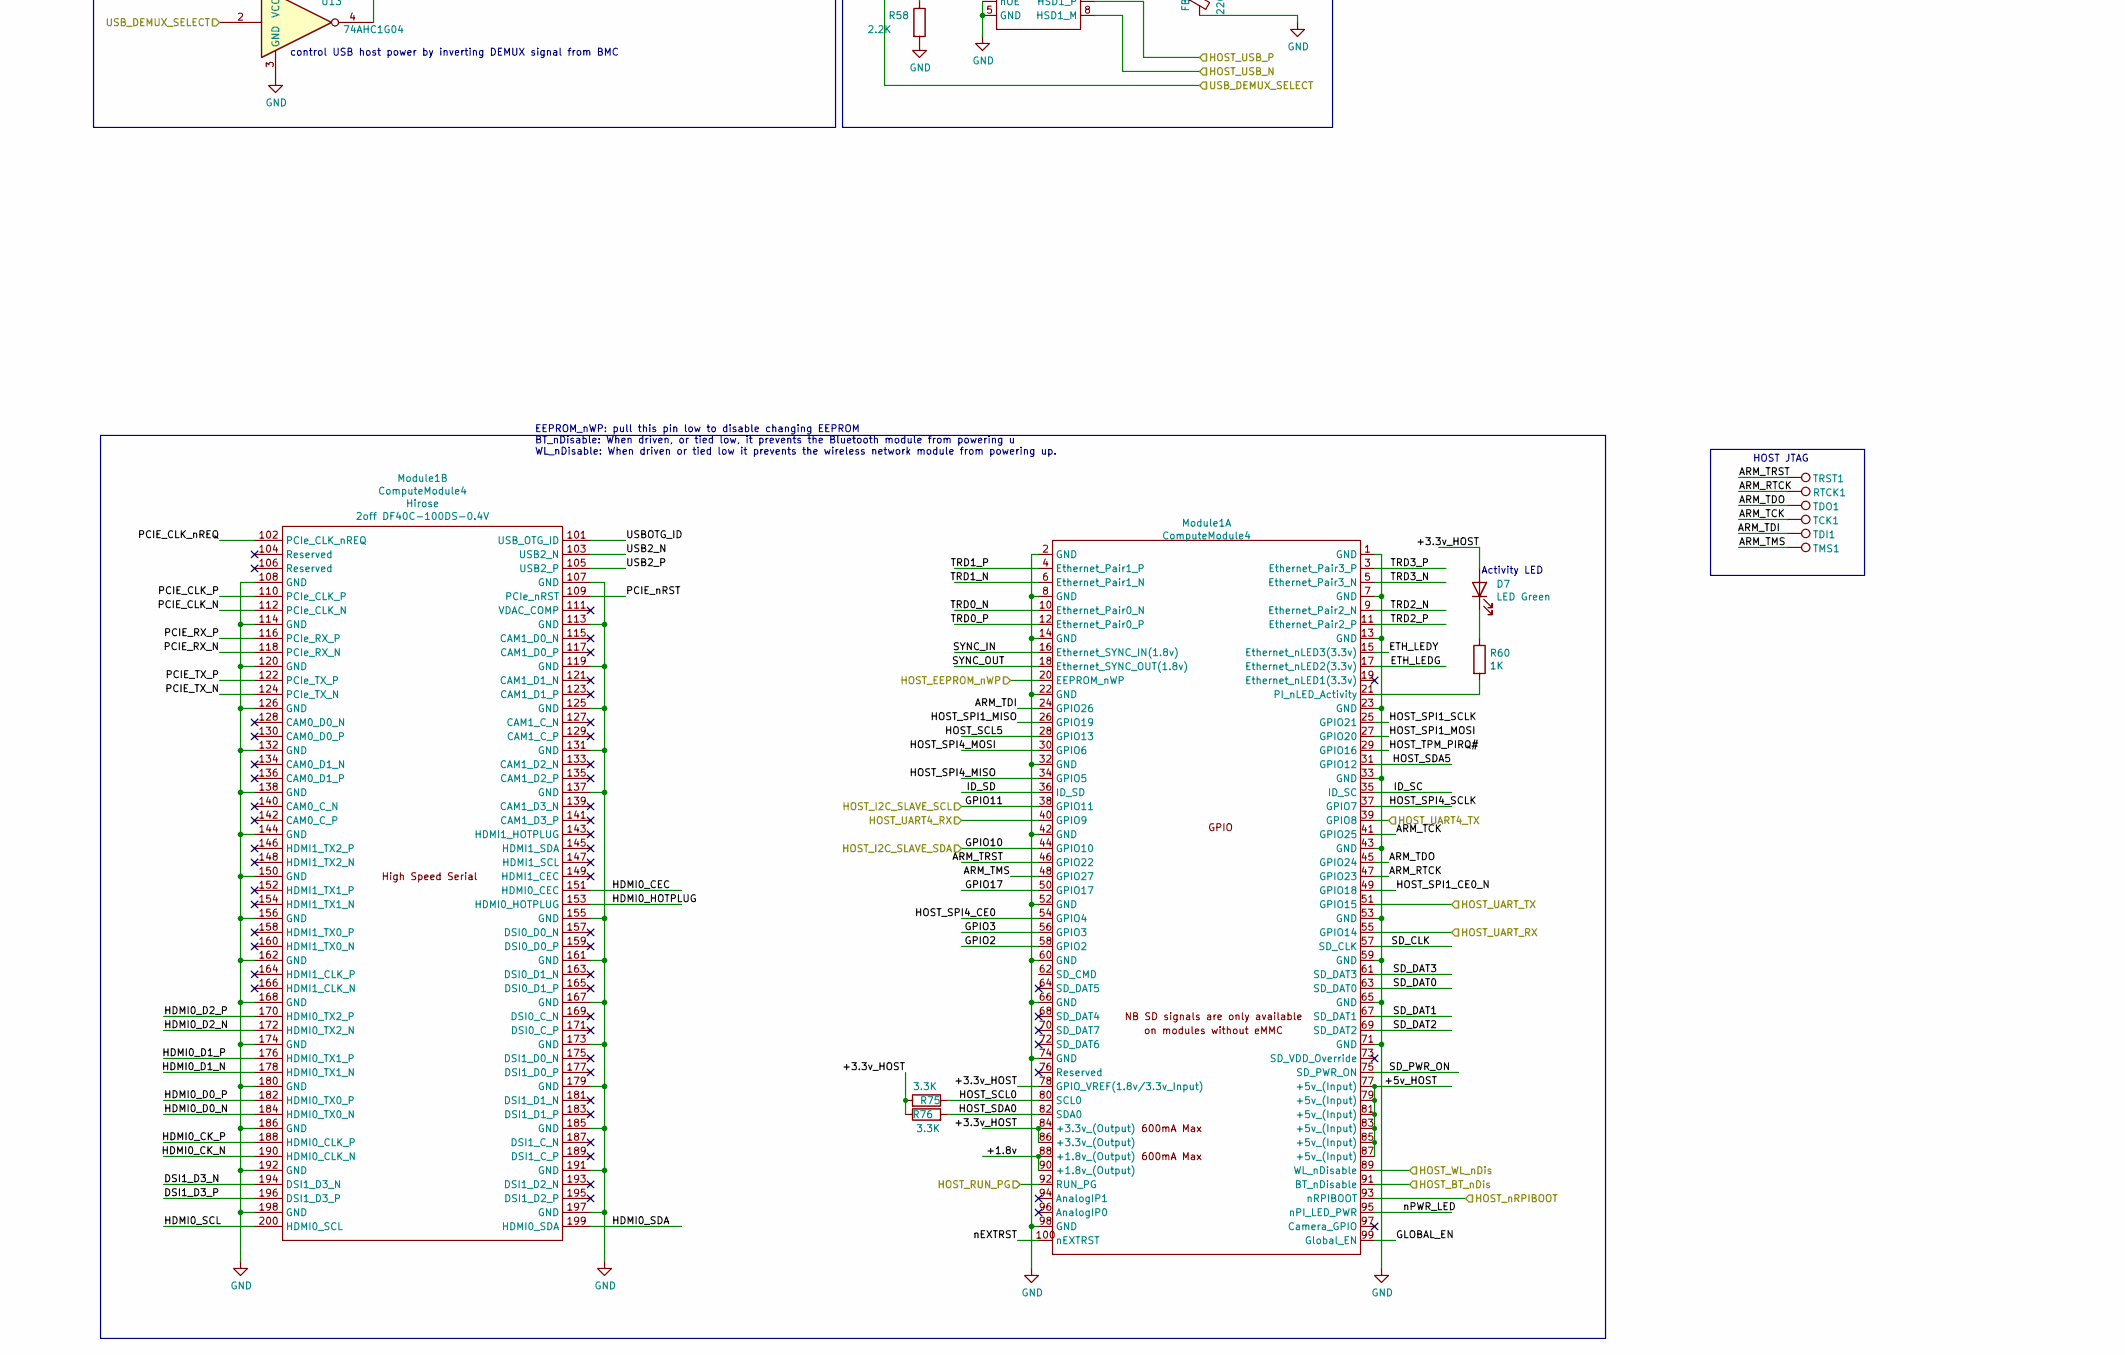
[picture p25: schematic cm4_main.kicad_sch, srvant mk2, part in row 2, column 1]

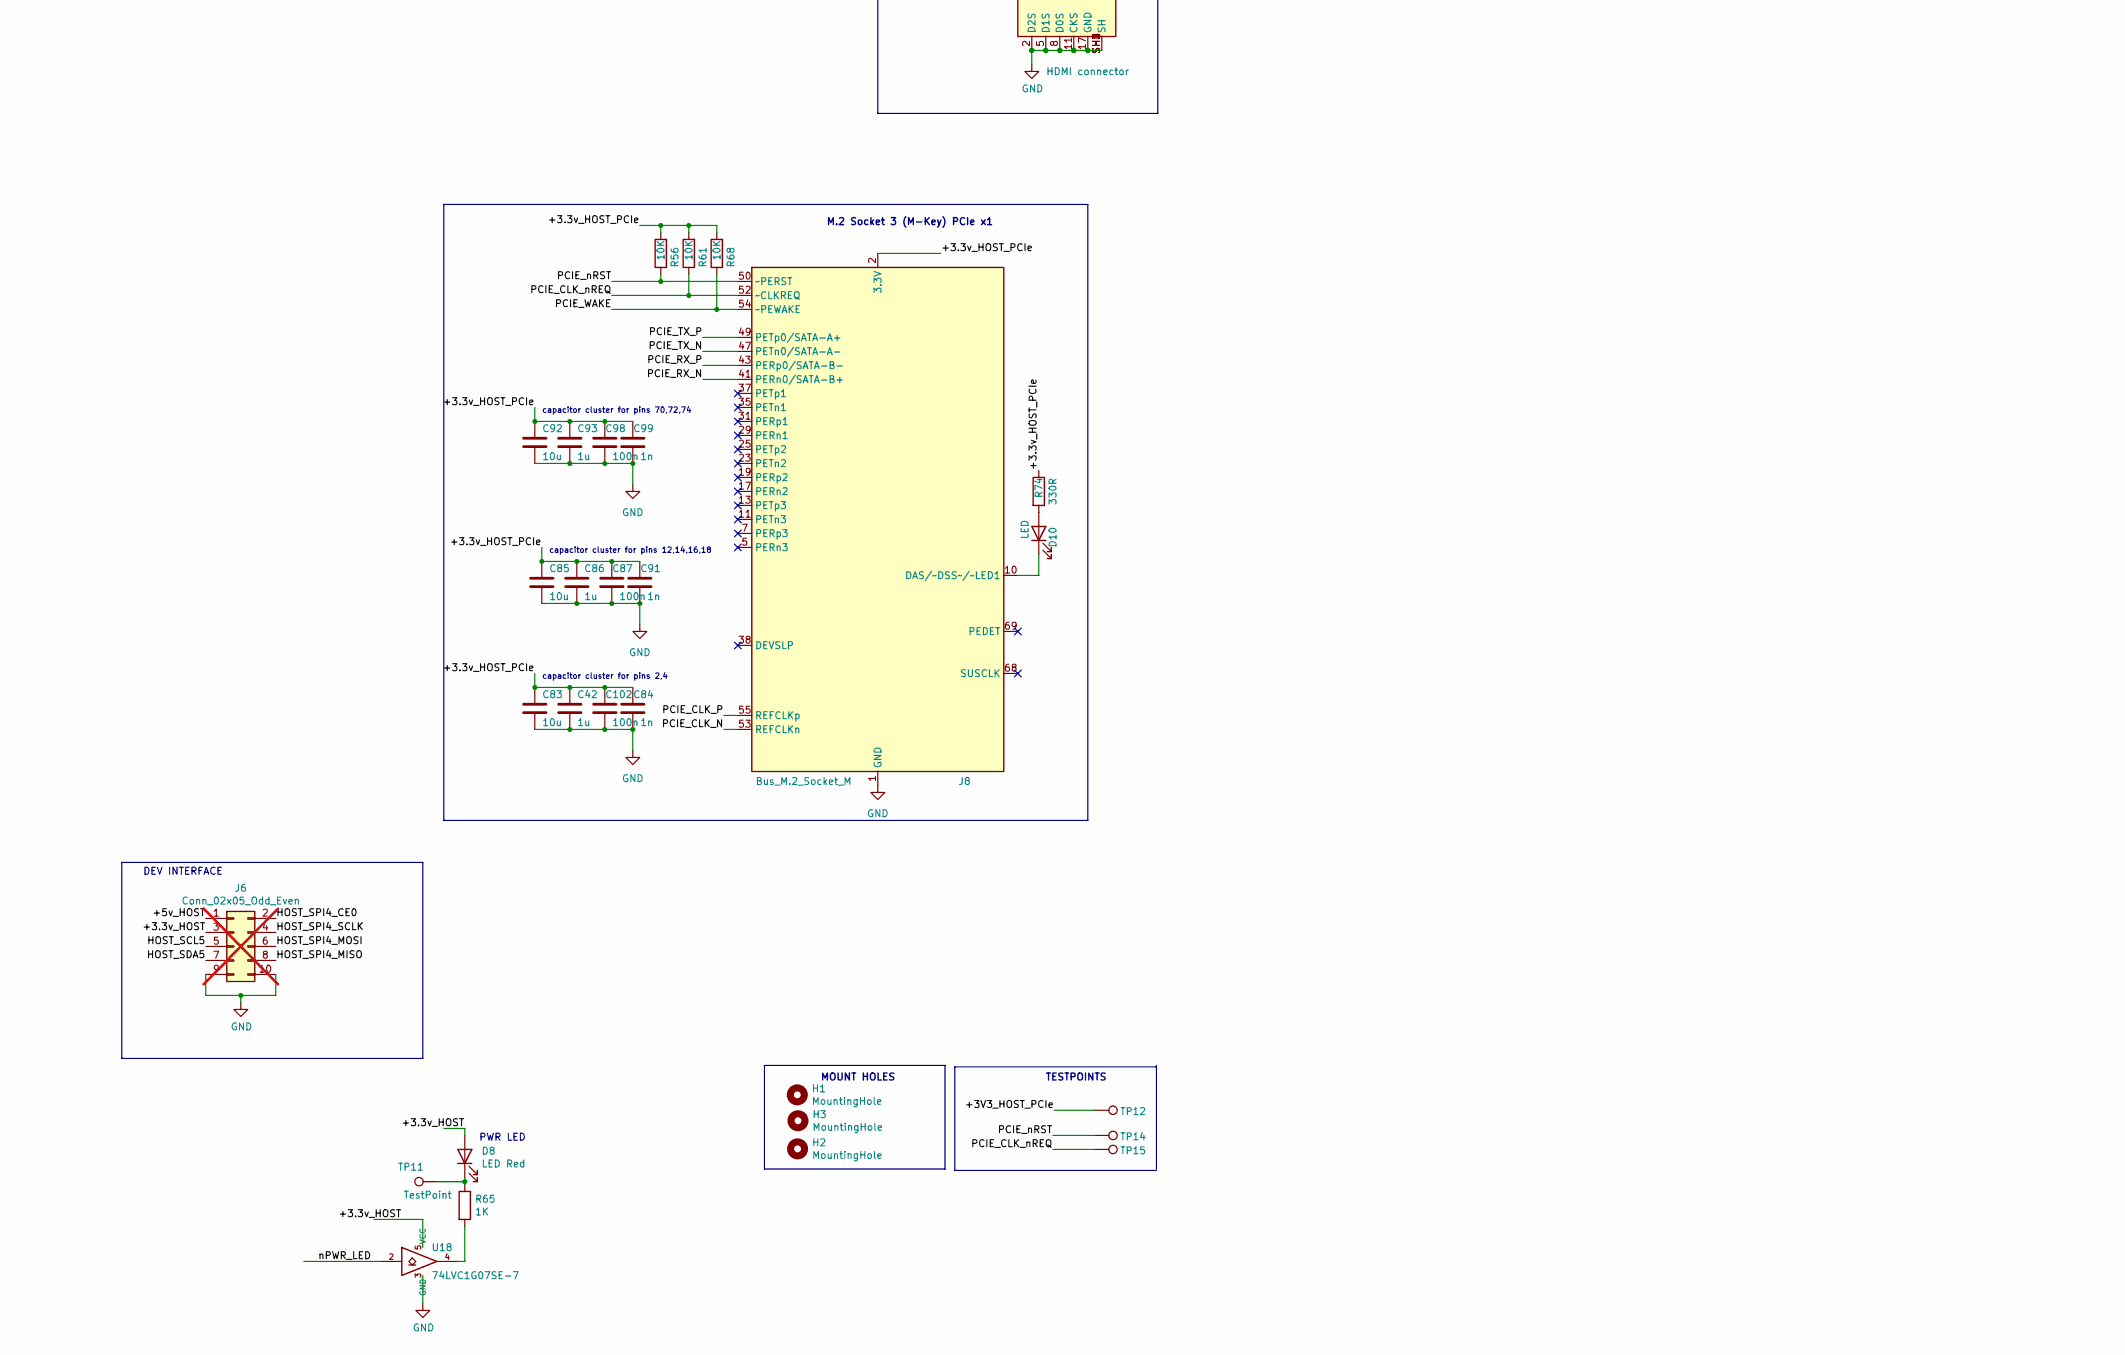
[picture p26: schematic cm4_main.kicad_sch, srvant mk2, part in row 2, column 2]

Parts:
C42, C86, C93: 1u; C_0805_2012Metric; farnell# 3013481
C70, C75, C77, C79, C81, C83, C85, C92: 10u; C_0805_2012Metric; Part Description 10uF 10% 10V Ceramic Capacitor X7R 0805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; digikey# 490-14381-1-ND
C74: 100u; CP_EIA-7343-31_Kemet-D; Part Description Capacitor, SP-Cap, 100u, 6.3V, 15mR ESR; mouser# ECASD40J107M015K00
C84, C91, C99: 1n; C_0805_2012Metric; farnell# 2812395
C87, C98, C102: 100n; C_0805_2012Metric; Part Description 0.1uF 10% 16V Ceramic Capacitor X7R 040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; farnell# 3582682
C88, C89, C90, C95, C96, C97, C104, C105: 100n; C_0402_1005Metric; Part Description 0.1uF 10% 16V Ceramic Capacitor X7R 040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
C94: 1u; C_0402_1005Metric; mouser# 81-GRT155C81A105KE1D
D7: LED Green; LED_0603_1608Metric; Part Description Green 572nm LED Indication - Discrete 2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
D8: LED Red; LED_0603_1608Metric; Part Description Red 620nm LED Indication - Discrete 2.2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
D10: LED; LED_0603_1608Metric; Part Description Red 620nm LED Indication - Discrete 2.2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
FB8, FB9: 220R; R_0402_1005Metric; mouser# 81-BLM15PX221SH1D
H1, H2, H3: MountingHole; MountingHole_2.5mm_Pad_TopOnly; Part Description M2.5 mounting hole
J6: Conn_02x05_Odd_Even; PinHeader_2x05_P2.54mm_Vertical; Part Description PinHeader_2x05_P2.54mm_Vertical; not fitted
J8: Bus_M.2_Socket_M; 1-2199230-5
J9: ARJM11; RJ45_Wuerth_7499111446_Horizontal
J10: HDMI connector; HDMI-10029449-001RLF; Part Description HDMI Connector, Right Angle, 19 Contact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; farnell# 2614936
J11: USB A; CONN_GSB19110KEU_AMP; Part Description GSB19110KEU; farnell# 1860613
Module1: ComputeModule4; Raspberry-Pi-4-Compute-Module; Part Description 100 Position Connector Receptacle, Cent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
R53: 15K; R_0402_1005Metric; Part Description Resistor 15K M1005 1% 63mW
R56, R61, R68: 10K; R_0402_1005Metric
R57, R59: 510K; R_0402_1005Metric; Part Description Resistor 510K M1005 1% 63mW
R58: 2.2K; R_0402_1005Metric; Part Description Resistor 2.2K M1005 1% 63mW
R60, R65: 1K; R_0402_1005Metric; Part Description Resistor 1K M1005 1% 63mW
R66, R67: 470R; R_0402_1005Metric; Part Description Resistor 470R M1005 1% 63mW
R74: 330R; R_0402_1005Metric
R75, R76: 3.3K; R_0402_1005Metric
RTCK1: RTCK; TestPoint_Pad_D1.0mm
TCK1: TCK; TestPoint_Pad_D1.0mm
TDI1: TDI; TestPoint_Pad_D1.0mm
TDO1: TDO; TestPoint_Pad_D1.0mm
TMS1: TMS; TestPoint_Pad_D1.0mm
TP11: TestPoint; TestPoint_Pad_D1.0mm
TP12: 3v3_PCIe; TestPoint_Pad_D1.0mm
TP14: PCIe_nCLKREQ; TestPoint_Pad_D1.0mm
TP15: PCIe_nRST; TestPoint_Pad_D1.0mm
TP18: TestPoint_Pad_D1.0mm
TRST1: TRST; TestPoint_Pad_D1.0mm
U13: 74AHC1G04; SOT-23-5; mouser# 595-SN74AHC1G04DBVRG
U14: AP22653W6; SOT-23-6; Part Description Power Switch/Driver 1:1 P-Channel 2.1A 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; farnell# 3755402
U16: FSUSB42MUX; FSUSB42UMX; Part Description USB Switch IC 1 Channel 10-MSOP
U17: PCF85063AT/AAZ; SOIC-8_3.9x4.9mm_P1.27mm; Part Description Real Time Clock (RTC) IC Clock/Calendar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
U18, U21: 74LVC1G07SE-7; SOT-353_SC-70-5; Part Description Buffer, Non-Inverting 1 Element 1 Bit p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
U19, U20: TPD4EUSB30; USON-10_2.5x1.0mm_P0.5mm; Part Description Quad TVS diode for high speed signals (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
U23: SLB9670VQ20FW785XTMA1; QFN32_SLB9670VQ20FW785XTMA1_INF; mouser# 726-SLB9670V20FW785X
U24: 74AHC1G08; SOT-23-5; mouser# 595-SN74AHC1G08DBVR
Y3: X32K768S301; Crystal_SMD_2012-2Pin_2.0x1.2mm; Part Description Crystal 32.768KHz 7pF 20pmm; digikey# 535-14101-2-ND

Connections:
/bmc/BMC_HOST_BT_nDis: Module1.89 (WL_nDisable); also elsewhere on the board
/bmc/BMC_HOST_EEPROM_nWP: Module1.20 (EEPROM_nWP); also elsewhere on the board
/bmc/BMC_HOST_POST_COMPLETE: Module1.92 (RUN_PG); also elsewhere on the board
/bmc/BMC_HOST_POWER_OUT: U24.2; also elsewhere on the board
/bmc/BMC_HOST_WL_nDis: Module1.91 (BT_nDisable); also elsewhere on the board
/bmc/BMC_HOST_nRPIBOOT: Module1.93 (nRPIBOOT); also elsewhere on the board
/bmc/BMC_UART0_RX: Module1.55 (GPIO14); also elsewhere on the board
/bmc/BMC_UART0_TX: Module1.51 (GPIO15); also elsewhere on the board
/bmc/BMC_UART1_RX: Module1.39 (GPIO8); also elsewhere on the board
/bmc/BMC_UART1_TX: Module1.40 (GPIO9); also elsewhere on the board
/bmc/BMC_USB_HOST_N: U16.8 (HSD1_M); also elsewhere on the board
/bmc/BMC_USB_HOST_P: U16.9 (HSD1_P); also elsewhere on the board
/cm4/+1.8v: Module1.88 (+1.8v_(Output)), Module1.90 (+1.8v_(Output))
/cm4/+3.3v_HOST: C94.1, C95.2, C96.2, C97.2, D7.2 (A), D8.2 (A), J9.11 (LED2+), J9.13 (LED1+), Module1.78 (GPIO_VREF(1.8v/3.3v_Input)), Module1.84 (+3.3v_(Output)), Module1.86 (+3.3v_(Output)), R75.2, R76.1, U16.1 (VCC), U18.5 (VCC), U23.1 (NCI/VDD), U23.8 (VDD), U23.14 (NCI/VDD), U23.22 (VDD)
/cm4/+3.3v_HOST_PCIe: C42.1, C83.1, C84.1, C85.1, C86.1, C87.1, C91.1, C92.1, C93.1, C98.1, C99.1, C102.1, J8.2 (3.3V), J8.4 (3.3V), J8.12 (3.3V), J8.14 (3.3V), J8.16 (3.3V), J8.18 (3.3V), J8.70 (3.3V), J8.72 (3.3V), J8.74 (3.3V), R56.2, R61.2, R68.2, R74.1, TP12.1; also elsewhere on the board
/cm4/+5v_HOST: C70.1, C89.1, Module1.77 (+5v_(Input)), Module1.79 (+5v_(Input)), Module1.81 (+5v_(Input)), Module1.83 (+5v_(Input)), Module1.85 (+5v_(Input)), Module1.87 (+5v_(Input)), R57.2, R59.2, U13.5 (VCC), U14.1 (IN), U21.5 (VCC), U24.5 (VCC); also elsewhere on the board
/cm4/+5v_HOST_HDMI: J10.18 (+5V); also elsewhere on the board
/cm4/+5v_HOST_VBUS: C74.1, C75.1, C77.1, C79.1, C81.1, J11.1 (VBUS), U14.6 (OUT)
/cm4/+BATT: C88.1, U17.8 (VDD); also elsewhere on the board
/cm4/ARM_RTCK: Module1.47 (GPIO23), RTCK1.1
/cm4/ARM_TCK: Module1.41 (GPIO25), TCK1.1
/cm4/ARM_TDI: Module1.24 (GPIO26), TDI1.1
/cm4/ARM_TDO: Module1.45 (GPIO24), TDO1.1
/cm4/ARM_TMS: Module1.48 (GPIO27), TMS1.1
/cm4/ARM_TRST: Module1.46 (GPIO22), TRST1.1
/cm4/DSI1_D3_N: Module1.194 (DSI1_D3_N)
/cm4/DSI1_D3_P: Module1.196 (DSI1_D3_P)
/cm4/ETH_LEDG: Module1.17 (Ethernet_nLED2(3.3v)), R66.2
/cm4/ETH_LEDY: Module1.15 (Ethernet_nLED3(3.3v)), R67.2
/cm4/GLOBAL_EN: Module1.99 (Global_EN), U21.4
/cm4/GPIO2: Module1.58 (GPIO2)
/cm4/GPIO3: Module1.56 (GPIO3)
/cm4/GPIO10: Module1.44 (GPIO10); also elsewhere on the board
/cm4/GPIO11: Module1.38 (GPIO11); also elsewhere on the board
/cm4/GPIO17: Module1.50 (GPIO17)
/cm4/HDMI0_CEC: J10.13 (CEC), Module1.151 (HDMI0_CEC)
/cm4/HDMI0_CK_N: J10.12 (CK-), Module1.190 (HDMI0_CLK_N)
/cm4/HDMI0_CK_P: J10.10 (CK+), Module1.188 (HDMI0_CLK_P)
/cm4/HDMI0_D0_N: J10.9 (D0-), Module1.184 (HDMI0_TX0_N)
/cm4/HDMI0_D0_P: J10.7 (D0+), Module1.182 (HDMI0_TX0_P)
/cm4/HDMI0_D1_N: J10.6 (D1-), Module1.178 (HDMI0_TX1_N)
/cm4/HDMI0_D1_P: J10.4 (D1+), Module1.176 (HDMI0_TX1_P)
/cm4/HDMI0_D2_N: J10.3 (D2-), Module1.172 (HDMI0_TX2_N)
/cm4/HDMI0_D2_P: J10.1 (D2+), Module1.170 (HDMI0_TX2_P)
/cm4/HDMI0_HOTPLUG: J10.19 (HPD/HEAC-), Module1.153 (HDMI0_HOTPLUG)
/cm4/HDMI0_SCL: J10.15 (SCL), Module1.200 (HDMI0_SCL)
/cm4/HDMI0_SDA: J10.16 (SDA), Module1.199 (HDMI0_SDA)
/cm4/HOST_SCL0: Module1.80 (SCL0), R75.1, U17.6 (SCL)
/cm4/HOST_SCL5: J6.5, Module1.28 (GPIO13)
/cm4/HOST_SDA0: Module1.82 (SDA0), R76.2, U17.5 (SDA)
/cm4/HOST_SDA5: J6.7, Module1.31 (GPIO12)
/cm4/HOST_SPI1_CE0_N: Module1.49 (GPIO18), U23.20 (CS#)
/cm4/HOST_SPI1_MISO: Module1.26 (GPIO19), U23.24 (MISO)
/cm4/HOST_SPI1_MOSI: Module1.27 (GPIO20), U23.21 (MOSI)
/cm4/HOST_SPI1_SCLK: Module1.25 (GPIO21), U23.19 (SCLK)
/cm4/HOST_SPI4_CE0: J6.2, Module1.54 (GPIO4)
/cm4/HOST_SPI4_MISO: J6.8, Module1.34 (GPIO5)
/cm4/HOST_SPI4_MOSI: J6.6, Module1.30 (GPIO6)
/cm4/HOST_SPI4_SCLK: J6.4, Module1.37 (GPIO7)
/cm4/HOST_TPM_PIRQ#: Module1.29 (GPIO16), U23.18 (PIRQ#)
/cm4/ID_SC: Module1.35 (ID_SC)
/cm4/ID_SD: Module1.36 (ID_SD)
/cm4/PCIE_CLK_N: J8.53 (REFCLKn), Module1.112 (PCIe_CLK_N)
/cm4/PCIE_CLK_P: J8.55 (REFCLKp), Module1.110 (PCIe_CLK_P)
/cm4/PCIE_CLK_nREQ: J8.52 (~CLKREQ), Module1.102 (PCIe_CLK_nREQ), R61.1, TP15.1
/cm4/PCIE_RX_N: J8.41 (PERn0/SATA-B+), Module1.118 (PCIe_RX_N)
/cm4/PCIE_RX_P: J8.43 (PERp0/SATA-B-), Module1.116 (PCIe_RX_P)
/cm4/PCIE_TX_N: J8.47 (PETn0/SATA-A-), Module1.124 (PCIe_TX_N)
/cm4/PCIE_TX_P: J8.49 (PETp0/SATA-A+), Module1.122 (PCIe_TX_P)
/cm4/PCIE_WAKE: J8.54 (~PEWAKE), R68.1
/cm4/PCIE_nRST: J8.50 (~PERST), Module1.109 (PCIe_nRST), R56.1, TP14.1
/cm4/SD_CLK: Module1.57 (SD_CLK)
/cm4/SD_DAT0: Module1.63 (SD_DAT0)
/cm4/SD_DAT1: Module1.67 (SD_DAT1)
/cm4/SD_DAT2: Module1.69 (SD_DAT2)
/cm4/SD_DAT3: Module1.61 (SD_DAT3)
/cm4/SD_PWR_ON: Module1.75 (SD_PWR_ON)
/cm4/SYNC_IN: Module1.16 (Ethernet_SYNC_IN(1.8v))
/cm4/SYNC_OUT: Module1.18 (Ethernet_SYNC_OUT(1.8v))
/cm4/TRD0_N: J9.2 (TD1-), Module1.10 (Ethernet_Pair0_N), U20.4 (D2+), U20.7
/cm4/TRD0_P: J9.1 (TD1+), Module1.12 (Ethernet_Pair0_P), U20.5 (D2-), U20.6
/cm4/TRD1_N: J9.3 (TD2+), Module1.6 (Ethernet_Pair1_N), U20.2 (D1-), U20.9
/cm4/TRD1_P: J9.4 (TD2-), Module1.4 (Ethernet_Pair1_P), U20.1 (D1+), U20.10
/cm4/TRD2_N: J9.8 (TD3-), Module1.9 (Ethernet_Pair2_N), U19.4 (D2+), U19.7
/cm4/TRD2_P: J9.7 (TD3+), Module1.11 (Ethernet_Pair2_P), U19.5 (D2-), U19.6
/cm4/TRD3_N: J9.9 (TD4+), Module1.5 (Ethernet_Pair3_N), U19.2 (D1-), U19.9
/cm4/TRD3_P: J9.10 (TD4-), Module1.3 (Ethernet_Pair3_P), U19.1 (D1+), U19.10
/cm4/USB2_N: Module1.103 (USB2_N), U16.4 (D_N)
/cm4/USB2_P: Module1.105 (USB2_P), U16.3 (D_P)
/cm4/USBOTG_ID: Module1.101 (USB_OTG_ID), R58.1, U13.2, U16.2 (SEL); also elsewhere on the board
/cm4/USB_OUT_N: J11.2 (D-), U16.6 (HSD0_M)
/cm4/USB_OUT_P: J11.3 (D+), U16.7 (HSD0_P)
/cm4/nEXTRST: Module1.100 (nEXTRST), U23.17 (RST#)
/cm4/nOCS1: TP18.1, U14.4 (nFault)
/cm4/nPWR_LED: Module1.95 (nPI_LED_PWR), U18.2
/cm4/nRTC_INT: U17.3 (~INT), U24.1
unnamed: C90.1, R59.1, U21.2
unnamed: C90.2, R57.1, U24.4
unnamed: C104.1, C105.1, J9.5 (CT), J9.6 (CT)
unnamed: D7.1 (K), R60.1
unnamed: D8.1 (K), R65.1, TP11.1
unnamed: D10.2 (A), R74.2
unnamed: D10.1 (K), J8.10 (DAS/~DSS~/~LED1)
unnamed: FB8.1, J9.SH
unnamed: J9.14 (LED1-), R67.1
unnamed: J9.12 (LED2-), R66.1
unnamed: FB9.1, J11.4 (GND), J11.5 (Shield)
unnamed: Module1.21 (PI_nLED_Activity), R60.2
unnamed: R65.2, U18.4
unnamed: U13.4, U14.3 (EN)
unnamed: R53.1, U14.5 (ILIM)
unnamed: U17.1 (OSCI), Y3.2
unnamed: U17.2 (OSCO), Y3.1

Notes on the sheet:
Activity LED
place close to VDD/GND pins
The differential Ethernet signals should be routed as 100Ω differential pairs, with suitable clearances. Length matching between pairs should be better than 50mm, so in the typical case no length matching is required. However the signals within a pair need to be length matched, ideally to better th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
capacitor cluster for pins 12,14,16,18
HOST JTAG
IIC address : 1010_001x
Ethernet POE Protection
RTC and RTC wakeup
ROUTING: * HDMI signals should be routed as 100Ω differential pairs. Each signal within a pair should ideally be matched to better than 0.15mm. Pairs don't typically need any extra matching, as they only have to be matched to 25mm * USB: The differential pair should be routed as a 90Ω differential 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
HOST USB power
capacitor cluster for pins 70,72,74
swapped: 3/4 and 9/10
Ethernet
DEV INTERFACE
TESTPOINTS
TODO: nOCS1 WHERE? add TestPad to be able to solder wire
HOST TPM 2.0 OPTIGA™ TPM SLB 9670 TPM2.0
TPM signal PINs
EEPROM_nWP: pull this pin low to disable changing EEPROM BT_nDisable: When driven, or tied low, it prevents the Bluetooth module from powering u WL_nDisable: When driven or tied low it prevents the wireless network module from powering up.
some schematic/pinouts https://pinout.xyz/pinout/letstrust_tpm# https://www.letstrust.de/uploads/letstrust-v2.0.schematic.pdf
MOUNT HOLES
GLOBAL_EN needs to be pulse low for >1mS
capacitor cluster for pins 2,4
control USB host power by inverting DEMUX signal from BMC
Current Limit switch
M.2 Socket 3 (M-Key) PCIe x1
Should FSUSB42MUX be powered by the "external" +3.3v provided by BMC (always ON) ?
PWR LED
The above circuit generates a pulse for GLOBAL_EN when nRTC_INT goes low
RTC alarms can be used to wake up the Compute module NB an Alarm triggering while already awake will cause a reset This can be used as a watchdog reset

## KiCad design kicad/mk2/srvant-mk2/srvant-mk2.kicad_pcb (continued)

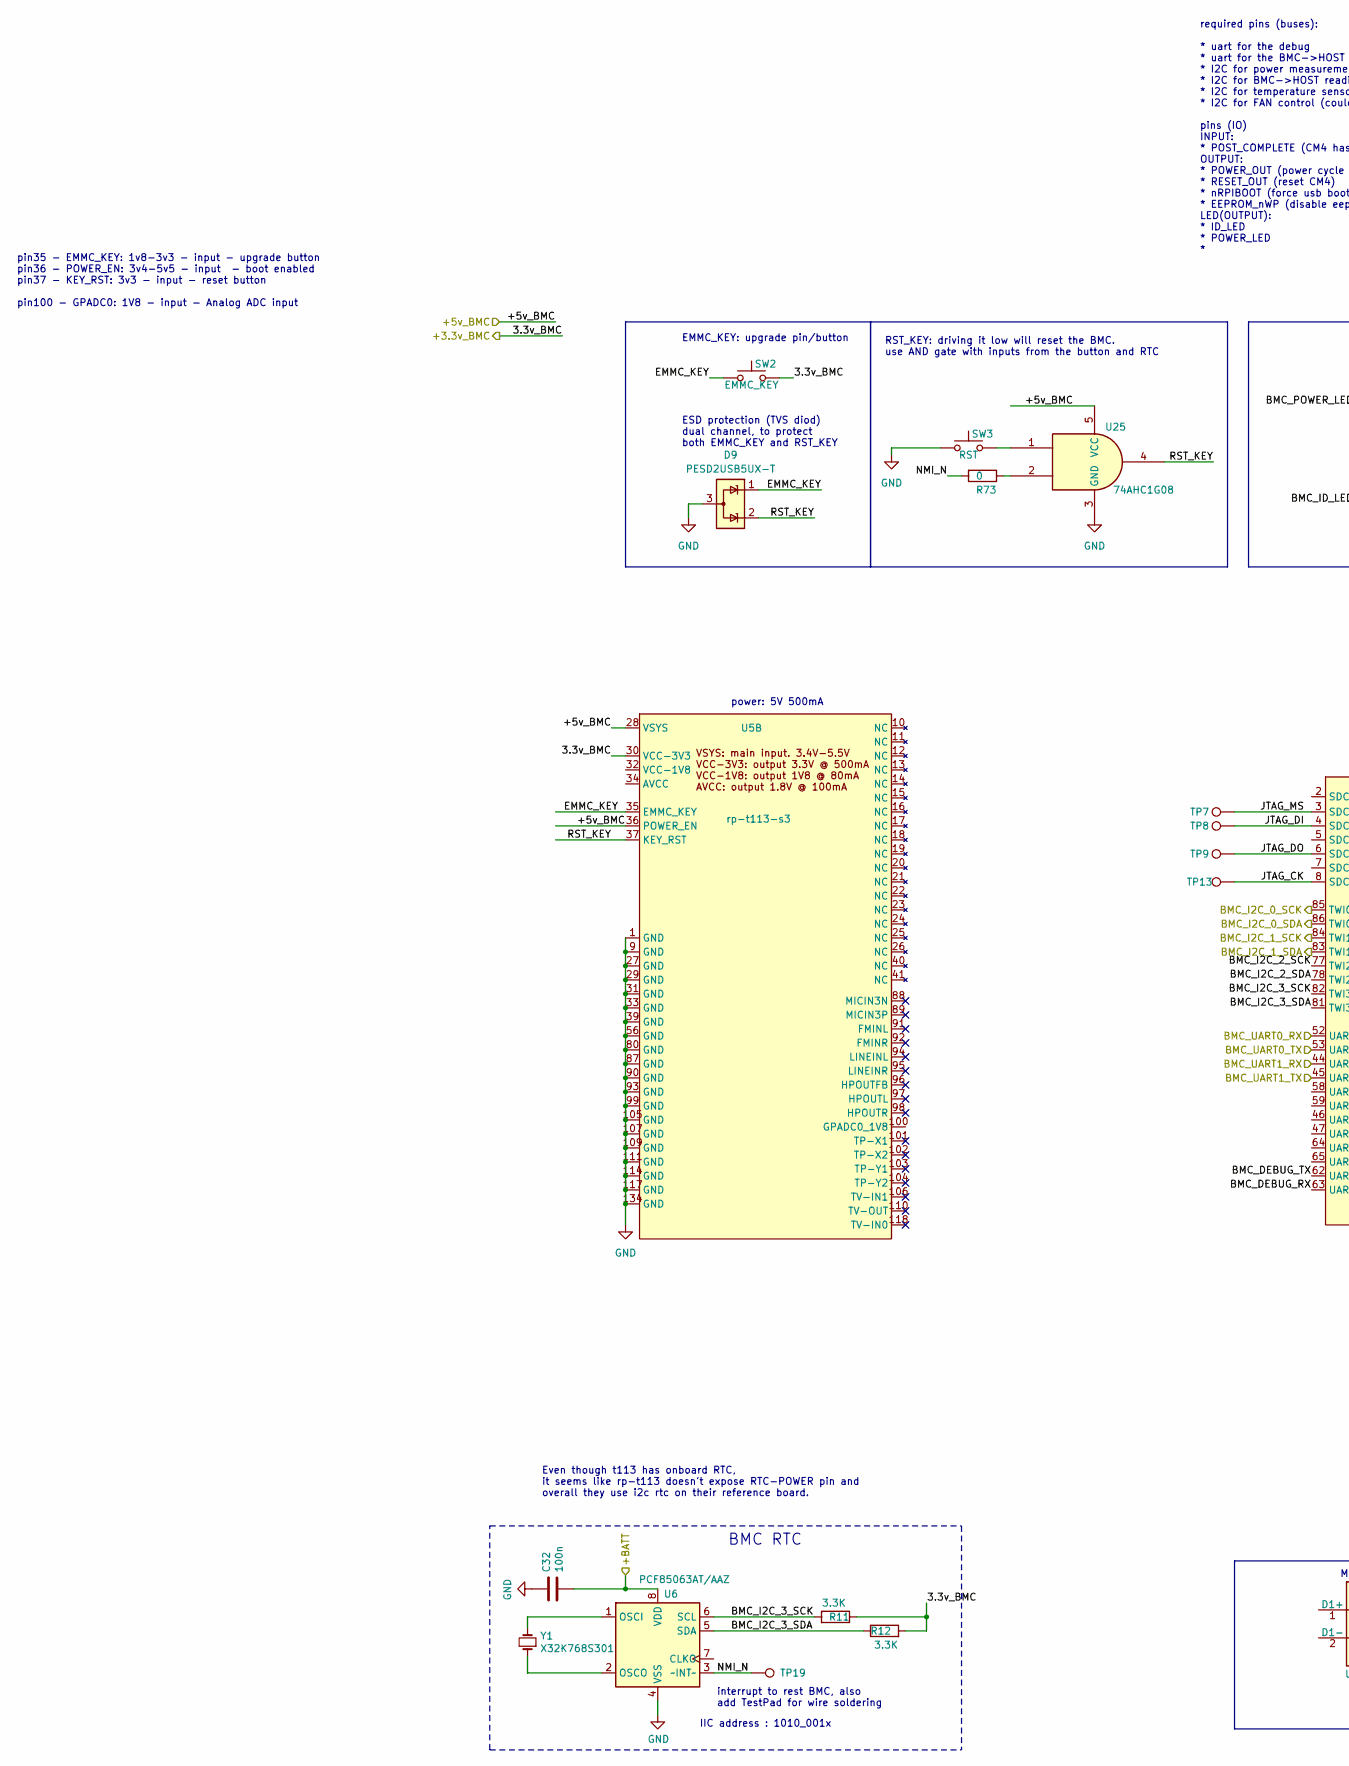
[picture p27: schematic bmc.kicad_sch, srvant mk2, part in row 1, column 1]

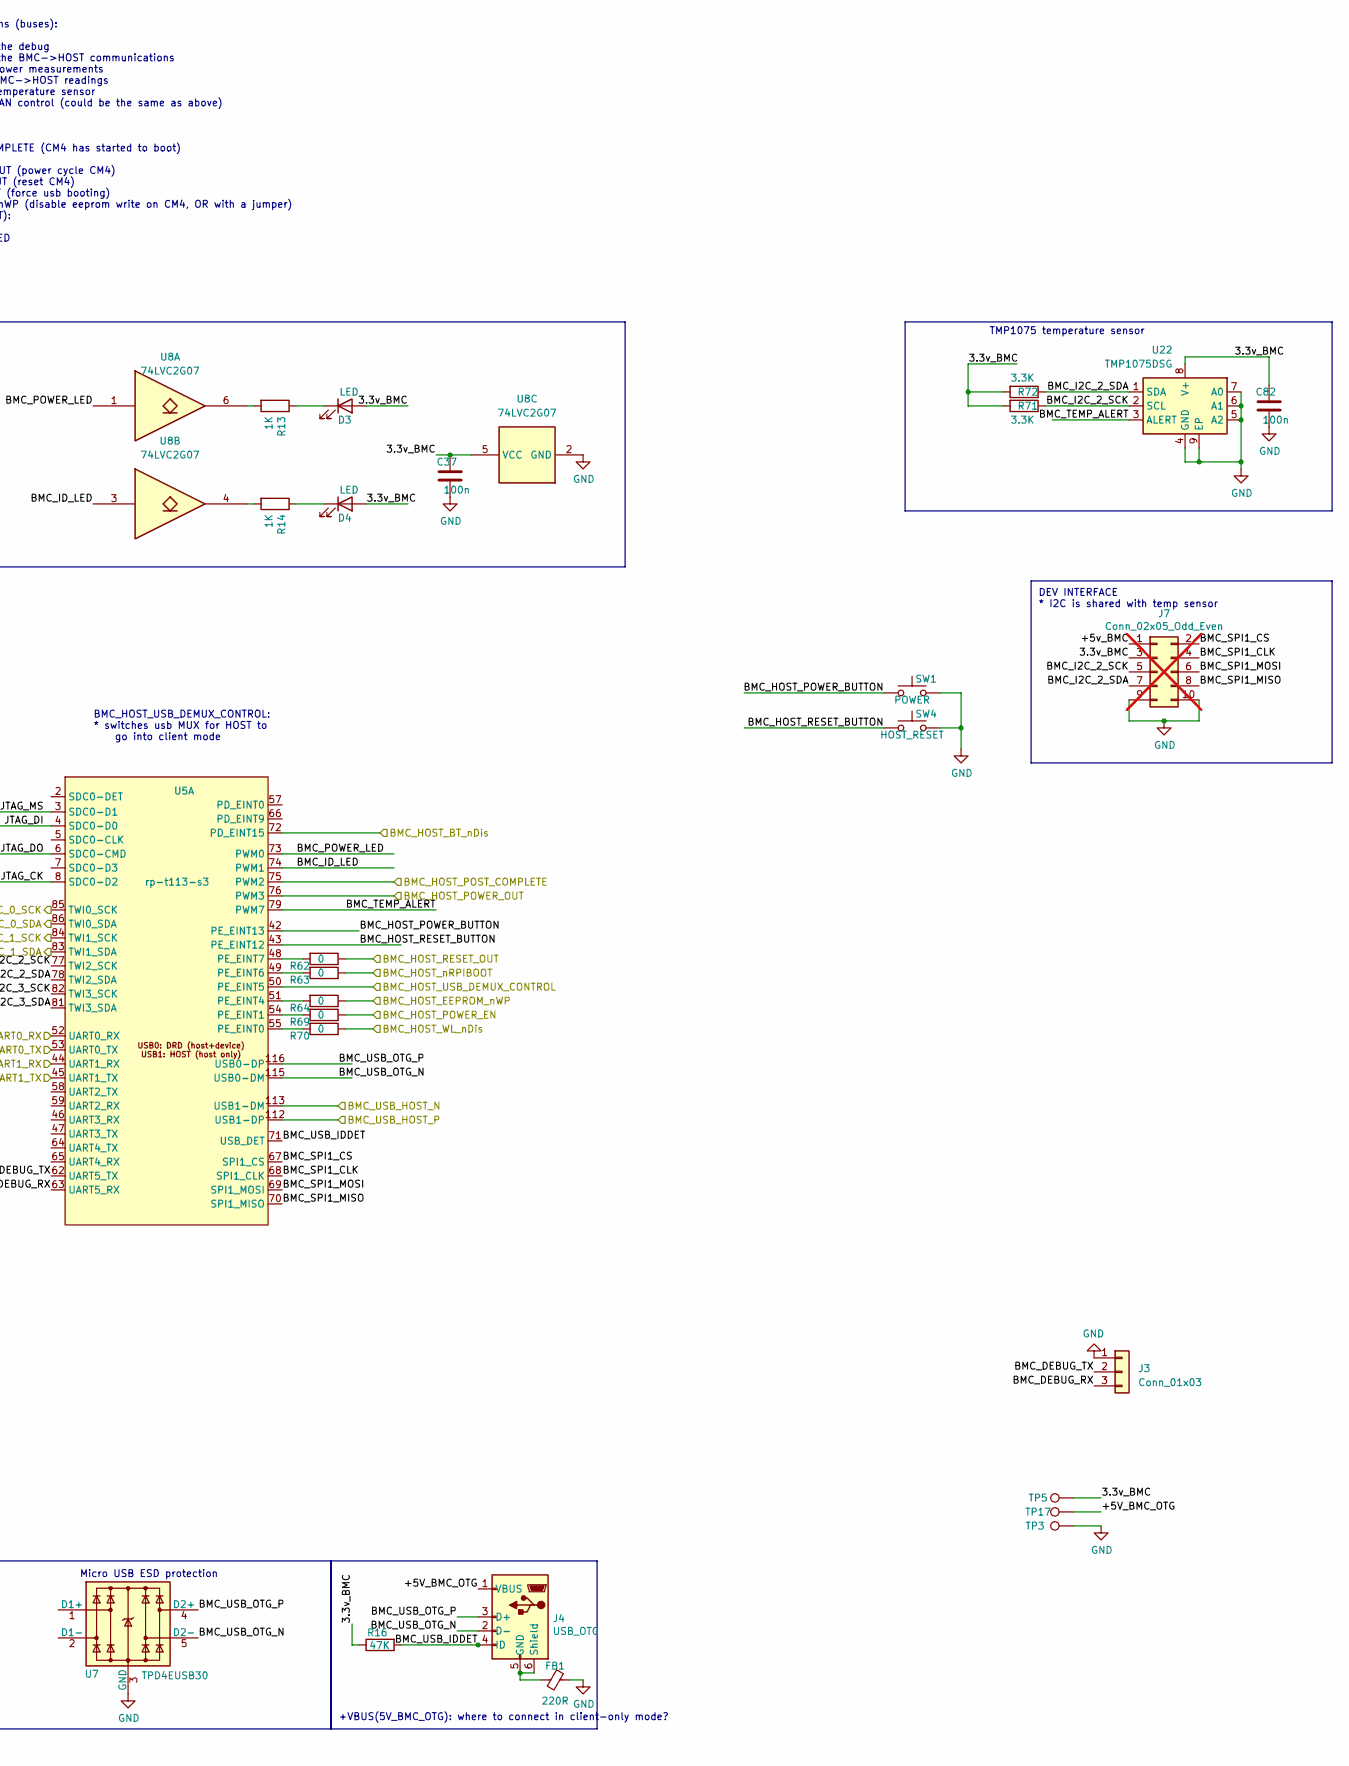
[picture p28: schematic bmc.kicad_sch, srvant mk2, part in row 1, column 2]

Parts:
C32: 100n; C_0402_1005Metric; Part Description 0.1uF 10% 16V Ceramic Capacitor X7R 040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
C37, C82: 100n; C_0402_1005Metric; Part Description 0.1uF 10% 16V Ceramic Capacitor X7R 040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; digikey# EMK105B7104KV-F
D3, D4: LED; LED_0603_1608Metric; Part Description Red 620nm LED Indication - Discrete 2.2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
D9: PESD2USB5UX-T; SOT-23; mouser# 771-PESD2USB5UXT-QR
FB1: 220R; R_0402_1005Metric; mouser# 81-BLM15PX221SH1D
J3: Conn_01x03; PinHeader_1x03_P2.54mm_Vertical
J4: USB_OTG; USB_Micro-B_Amphenol_10103594-0001LF_Horizontal; Part Description USB - micro B USB 2.0 Receptacle Connec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
J7: Conn_02x05_Odd_Even; PinHeader_2x05_P2.54mm_Vertical; Part Description PinHeader_2x05_P2.54mm_Vertical; not fitted
R11, R12, R71, R72: 3.3K; R_0402_1005Metric
R13, R14: 1K; R_0402_1005Metric; Part Description Resistor 1K M1005 1% 63mW
R16: 47K; R_0402_1005Metric; Part Description Resistor 1K M1005 1% 63mW
R62, R63, R64, R69, R70, R73: 0; R_0402_1005Metric
SW1: POWER; button-SW_TL3340AF160QG; farnell# 2787247
SW2: EMMC_KEY; SW4_FSM-5P23_TEC
SW3: RST; SW4_FSM-5P23_TEC
SW4: HOST_RESET; button-SW_TL3340AF160QG; farnell# 2787247
TP3: GND; TestPoint_Pad_D1.0mm
TP5: 3.3v BMC; TestPoint_Pad_D1.0mm
TP7: MS; TestPoint_Pad_D1.0mm
TP8: DI; TestPoint_Pad_D1.0mm
TP9: DO; TestPoint_Pad_D1.0mm
TP13: CK; TestPoint_Pad_D1.0mm
TP17: 5v OTG; TestPoint_Pad_D1.0mm
TP19: NMI_N; TestPoint_Pad_D1.0mm
U5: rp-t113-s3
U6: PCF85063AT/AAZ; SOIC-8_3.9x4.9mm_P1.27mm; Part Description Real Time Clock (RTC) IC Clock/Calendar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
U7: TPD4EUSB30; USON-10_2.5x1.0mm_P0.5mm; Part Description Quad TVS diode for high speed signals (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
U8: 74LVC2G07; SOT-23-6; mouser# 595-SN74LVC2G07DBVR
U22: TMP1075DSG; WSON-8-1EP_2x2mm_P0.5mm_EP0.9x1.6mm_ThermalVias; mouser# 595-TMP1075DSGR
U25: 74AHC1G08; SOT-23-5; mouser# 595-SN74AHC1G08DBVR
Y1: X32K768S301; Crystal_SMD_2012-2Pin_2.0x1.2mm; Part Description Crystal 32.768KHz 7pF 20pmm; digikey# 535-14101-2-ND

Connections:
/BMC ethernet/PHY_MDIO: U5.118 (RMII-MDIO); also elsewhere on the board
/bmc/+5v_BMC: J7.1, U5.28 (VSYS), U5.36 (POWER_EN), U25.5 (VCC); also elsewhere on the board
/bmc/BMC_DEBUG_RX: J3.3, U5.63 (UART5_RX)
/bmc/BMC_DEBUG_TX: J3.2, U5.62 (UART5_TX)
/bmc/BMC_HOST_BT_nDis: U5.72 (PD_EINT15); also elsewhere on the board
/bmc/BMC_HOST_EEPROM_nWP: R64.1; also elsewhere on the board
/bmc/BMC_HOST_POST_COMPLETE: R62.1, U5.75 (PWM2); also elsewhere on the board
/bmc/BMC_HOST_POWER_BUTTON: SW1.1, U5.42 (PE_EINT13)
/bmc/BMC_HOST_POWER_OUT: U5.76 (PWM3); also elsewhere on the board
/bmc/BMC_HOST_RESET_BUTTON: SW4.1, U5.43 (PE_EINT12)
/bmc/BMC_HOST_WL_nDis: R70.1; also elsewhere on the board
/bmc/BMC_HOST_nRPIBOOT: R63.1; also elsewhere on the board
/bmc/BMC_I2C_2_SCK: J7.5, R71.1, U5.77 (TWI2_SCK), U22.2 (SCL)
/bmc/BMC_I2C_2_SDA: J7.7, R72.1, U5.78 (TWI2_SDA), U22.1 (SDA)
/bmc/BMC_I2C_3_SCK: R11.2, U5.82 (TWI3_SCK), U6.6 (SCL)
/bmc/BMC_I2C_3_SDA: R12.1, U5.81 (TWI3_SDA), U6.5 (SDA)
/bmc/BMC_ID_LED: U5.74 (PWM1), U8.3
/bmc/BMC_POWER_LED: U5.73 (PWM0), U8.1
/bmc/BMC_SPI1_CLK: J7.4, U5.68 (SPI1_CLK)
/bmc/BMC_SPI1_CS: J7.2, U5.67 (SPI1_CS)
/bmc/BMC_SPI1_MISO: J7.8, U5.70 (SPI1_MISO)
/bmc/BMC_SPI1_MOSI: J7.6, U5.69 (SPI1_MOSI)
/bmc/BMC_TEMP_ALERT: U5.79 (PWM7), U22.3 (ALERT)
/bmc/BMC_UART0_RX: U5.52 (UART0_RX); also elsewhere on the board
/bmc/BMC_UART0_TX: U5.53 (UART0_TX); also elsewhere on the board
/bmc/BMC_UART1_RX: U5.44 (UART1_RX); also elsewhere on the board
/bmc/BMC_UART1_TX: U5.45 (UART1_TX); also elsewhere on the board
/bmc/BMC_USB_HOST_N: U5.113 (USB1-DM); also elsewhere on the board
/bmc/BMC_USB_HOST_P: U5.112 (USB1-DP); also elsewhere on the board
/bmc/BMC_USB_OTG_N: J4.2 (D-), U5.115 (USB0-DM), U7.5 (D2-), U7.6
/bmc/BMC_USB_OTG_P: J4.3 (D+), U5.116 (USB0-DP), U7.4 (D2+), U7.7
/bmc/EMMC_KEY: D9.1 (K), SW2.1, U5.35 (EMMC_KEY)
/bmc/JTAG_CK: TP13.1, U5.8 (SDC0-D2)
/bmc/JTAG_DI: TP8.1, U5.4 (SDC0-D0)
/bmc/JTAG_DO: TP9.1, U5.6 (SDC0-CMD)
/bmc/JTAG_MS: TP7.1, U5.3 (SDC0-D1)
/bmc/NMI_N: R73.2, TP19.1, U6.3 (~INT~)
/bmc/RST_KEY: D9.2 (K), U5.37 (KEY_RST), U25.4
/cm4/+BATT: C32.2, U6.8 (VDD); also elsewhere on the board
/cm4/GPIO10: U5.83 (TWI1_SDA); also elsewhere on the board
/cm4/GPIO11: U5.84 (TWI1_SCK); also elsewhere on the board
/cm4/USBOTG_ID: U5.50 (PE_EINT5); also elsewhere on the board
/power/BMC_HOST_POWER_EN: R69.1; also elsewhere on the board
/power/BMC_I2C_0_SCK: U5.85 (TWI0_SCK); also elsewhere on the board
/power/BMC_I2C_0_SDA: U5.86 (TWI0_SDA); also elsewhere on the board
unnamed: D3.1 (K), R13.1
unnamed: D4.1 (K), R14.1
unnamed: FB1.2, J4.5 (GND), J4.6 (Shield)
unnamed: R13.2, U8.6
unnamed: R14.2, U8.4
unnamed: R73.1, U25.2
unnamed: SW3.2, U25.1
unnamed: R70.2, U5.55 (PE_EINT0)
unnamed: R69.2, U5.54 (PE_EINT1)
unnamed: R64.2, U5.51 (PE_EINT4)
unnamed: R63.2, U5.49 (PE_EINT6)
unnamed: R62.2, U5.48 (PE_EINT7)
unnamed: U6.1 (OSCI), Y1.2
unnamed: U6.2 (OSCO), Y1.1
unnamed: U7.1 (D1+), U7.10
unnamed: U7.2 (D1-), U7.9

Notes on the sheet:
pin35 - EMMC_KEY: 1v8-3v3 - input - upgrade button pin36 - POWER_EN: 3v4-5v5 - input - boot enabled pin37 - KEY_RST: 3v3 - input - reset button pin100 - GPADC0: 1V8 - input - Analog ADC input
interrupt to rest BMC, also add TestPad for wire soldering
IIC address : 1010_001x
EMMC_KEY: upgrade pin/button
Micro USB ESD protection
RST_KEY: driving it low will reset the BMC. use AND gate with inputs from the button and RTC
ESD protection (TVS diod) dual channel, to protect both EMMC_KEY and RST_KEY
required pins (buses): * uart for the debug * uart for the BMC->HOST communications * I2C for power measurements * I2C for BMC->HOST readings * I2C for temperature sensor * I2C for FAN control (could be the same as above) pins (IO) INPUT: * POST_COMPLETE (CM4 has started to boot) OUTPUT: * POWER_OU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
DEV INTERFACE * I2C is shared with temp sensor
Even though t113 has onboard RTC, it seems like rp-t113 doesn't expose RTC-POWER pin and overall they use i2c rtc on their reference board.
power: 5V 500mA
BMC RTC
BMC_HOST_USB_DEMUX_CONTROL: * switches usb MUX for HOST to go into client mode
TMP1075 temperature sensor
+VBUS(5V_BMC_OTG): where to connect in client-only mode?

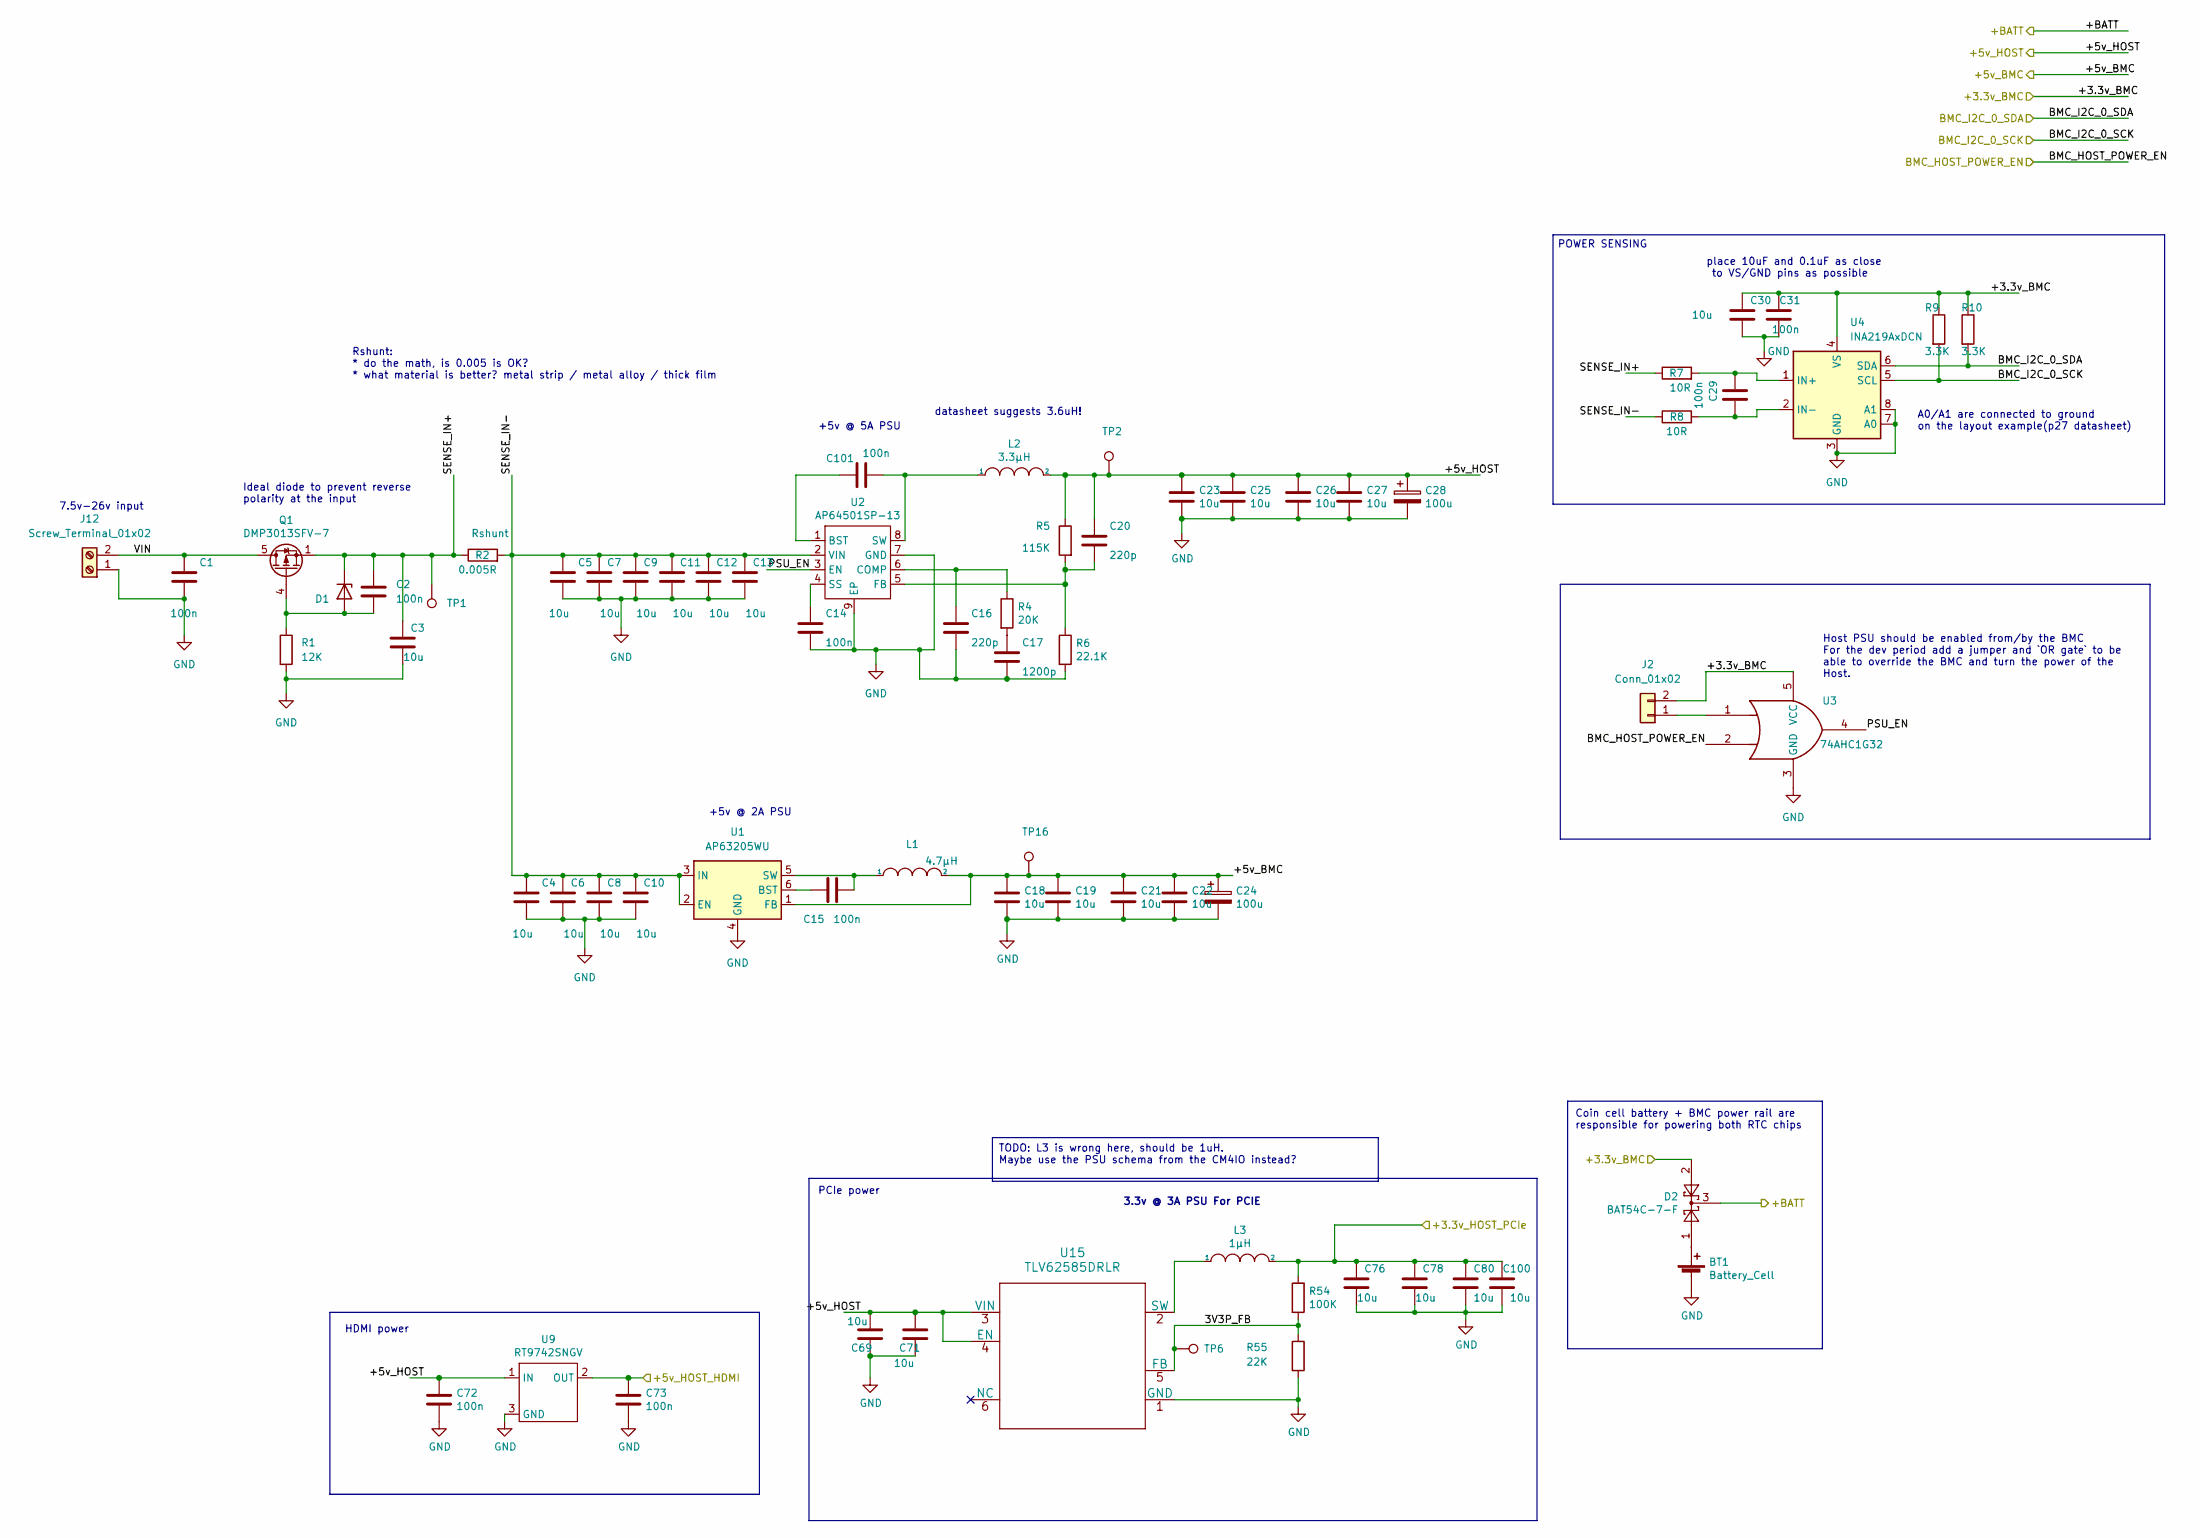
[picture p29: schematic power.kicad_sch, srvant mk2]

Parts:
BT1: Battery_Cell; battery-S8411-45R
C1: 100n; C_1206_3216Metric; Part Description 0.1uF 10% 100V Ceramic Capacitor X5R 04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; farnell# 2611907
C2, C31: 100n; C_0402_1005Metric; Part Description 0.1uF 10% 16V Ceramic Capacitor X7R 040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; farnell# 2611911
C3, C4, C5, C6, C7, C8, C9, C10, C11, C12, C13: 10u; C_0805_2012Metric; Part Description 10uF 10% or 20% 35V Ceramic Capacitor X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; digikey# 490-10505-1-ND
C14, C15, C29: 100n; C_0402_1005Metric; Part Description 0.1uF 10% 16V Ceramic Capacitor X7R 040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; digikey# EMK105B7104KV-F
C16, C20: 220p; C_0402_1005Metric; Part Description 220 pF, 50 V, 0402 [1005 Metric], ± 5%,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; farnell# 2666374
C17: 1200p; C_0402_1005Metric; Part Description 1200pF 10% 10V Ceramic Capacitor X5R 04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; digikey# 490-16429-1-ND
C18, C19, C21, C22, C23, C25, C26, C27, C69, C71, C76, C78, C80, C100: 10u; C_0805_2012Metric; Part Description 10uF 10% 10V Ceramic Capacitor X7R 0805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; digikey# 490-14381-1-ND
C24, C28: 100u; CP_EIA-7343-31_Kemet-D; Part Description Capacitor, SP-Cap, 100u, 6.3V, 15mR ESR; mouser# ECASD40J107M015K00
C30: 10u; C_0402_1005Metric; Part Description 10uF 10% or 20% 35V Ceramic Capacitor X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; digikey# 490-10505-1-ND
C72, C73, C101: 100n; C_0402_1005Metric; Part Description 0.1uF 10% 16V Ceramic Capacitor X7R 040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
D1: MMBZ5242BLT3G; SOT-23-3_1P4X3P040_ONS; Part Description Zener Diode 12V 225mW 5% Surface Mount 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; digikey# MMBZ5242BLT3GOSCT-ND
D2: BAT54C-7-F; SOT-23; Part Description Diode Array 1 Pair Common Cathode Schot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
J2: Conn_01x02; PinHeader_1x02_P2.54mm_Vertical
J12: Screw_Terminal_01x02; TerminalBlock_bornier-2_P5.08mm
L1: 4.7µH; L_Bourns-SRN4018; Part Description 4.7µH Semi-Shielded Wirewound Inductor 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; mouser# 652-SRN4018-4R7M
L2: 3.3µH; L_Bourns_SRN6045TA; Part Description 3.3µH Semi-Shielded Wirewound Inductor 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; farnell# 2616889
L3: 1µH; L_Bourns_SRN6045TA; Part Description 1µH Semi-Shielded Wirewound Inductor 8A; farnell# 2616885
Q1: DMP3013SFV-7; Diodes_PowerDI3333-8; Part Description DMP3013SFV-7 - Power MOSFET, P Channel,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; mouser# 621-DMP3013SFV-7
R1: 12K; R_0402_1005Metric; Part Description Resistor 12K M1005 1% 63mW; farnell# 9239367
R2: 0.005R; R_0805_2012Metric; Part Description Rshunt; farnell# 2729138
R4: 20K; R_0402_1005Metric; Part Description Resistor 20K M1005 1% 63mW; farnell# 2331485
R5: 115K; R_0402_1005Metric
R6: 22.1K; R_0402_1005Metric
R7, R8: 10R; R_0402_1005Metric; Part Description Resistor 10R M1005 1% 63mW; farnell# 9238999
R9, R10: 3.3K; R_0402_1005Metric
R54: 100K; R_0402_1005Metric; Part Description Resistor 100K M1005 1% 63mW
R55: 22K; R_0402_1005Metric; Part Description Resistor 22K M1005 1% 63mW; farnell# 9239430
TP1, TP6: VIN; TestPoint_Pad_D1.0mm
TP2: +5v HOST; TestPoint_Pad_2.0x2.0mm
TP16: +5v BMC; TestPoint_Pad_D1.0mm
U1: AP63205WU; TSOT-23-6; mouser# 621-AP63205WU-7
U2: AP64501SP-13; SOIC-8-1EP_3.9x4.9mm_P1.27mm_EP2.95x4.9mm_Mask2.71x3.4mm_Th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; Part Description Buck Switching Regulator IC Positive Ad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; digikey# 31-AP64501SP-13CT-ND
U3: 74AHC1G32; SOT-23-5; mouser# 595-SN74AHC1G32DBVR
U4: INA219AxDCN; SOT-23-8; mouser# 595-INA219AIDCNR
U9: RT9742SNGV; SOT-23; Part Description Power Switch/Driver 1:1 N-Channel 500mA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; mouser# 835-RT9742SNGV
U15: TLV62585DRLR; DRL0006A; mouser# 595-TLV62585DRLR

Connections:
/bmc/+5v_BMC: C18.1, C19.1, C21.1, C22.1, C24.1, L1.2, TP16.1, U1.1 (FB); also elsewhere on the board
/cm4/+3.3v_HOST_PCIe: C76.1, C78.1, C80.1, C100.1, L3.2, R54.1; also elsewhere on the board
/cm4/+5v_HOST: C20.1, C23.1, C25.1, C26.1, C27.1, C28.1, C69.1, C71.1, C72.1, L2.2, R5.1, TP2.1, U9.1 (IN), U15.3 (VIN), U15.4 (EN); also elsewhere on the board
/cm4/+5v_HOST_HDMI: C73.1, U9.2 (OUT); also elsewhere on the board
/cm4/+BATT: D2.3; also elsewhere on the board
/power/3V3P_FB: R54.2, R55.1, TP6.1, U15.5 (FB)
/power/BMC_HOST_POWER_EN: U3.2; also elsewhere on the board
/power/BMC_I2C_0_SCK: R9.2, U4.5 (SCL); also elsewhere on the board
/power/BMC_I2C_0_SDA: R10.2, U4.6 (SDA); also elsewhere on the board
/power/PSU_EN: U2.3 (EN), U3.4
/power/SENSE_IN+: C2.1, C3.1, D1.1 (K), Q1.1 (S), Q1.2 (S), Q1.3 (S), R2.1, R7.1, TP1.1
/power/SENSE_IN-: C4.1, C5.1, C6.1, C7.1, C8.1, C9.1, C10.1, C11.1, C12.1, C13.1, R2.2, R8.1, U1.2 (EN), U1.3 (IN), U2.2 (VIN)
/power/VIN: C1.1, J12.2, Q1.5 (D)
unnamed: BT1.1 (+), D2.1
unnamed: C17.1, R4.2
unnamed: C2.2, D1.2 (A), Q1.4 (G), R1.1
unnamed: J2.1, U3.1
unnamed: C15.1, U1.6 (BST)
unnamed: C15.2, L1.1, U1.5 (SW)
unnamed: C101.1, U2.1 (BST)
unnamed: C16.1, R4.1, U2.6 (COMP)
unnamed: C20.2, R5.2, R6.1, U2.5 (FB)
unnamed: C14.1, U2.4 (SS)
unnamed: C101.2, L2.1, U2.8 (SW)
unnamed: C29.1, R7.2, U4.1 (IN+)
unnamed: C29.2, R8.2, U4.2 (IN-)
unnamed: L3.1, U15.2 (SW)

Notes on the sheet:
TODO: L3 is wrong here, should be 1uH. Maybe use the PSU schema from the CM4IO instead?
A0/A1 are connected to ground on the layout example(p27 datasheet)
Host PSU should be enabled from/by the BMC For the dev period add a jumper and `OR gate` to be able to override the BMC and turn the power of the Host.
datasheet suggests 3.6uH!
3.3v @ 3A PSU For PCIE
Ideal diode to prevent reverse polarity at the input
7.5v-26v input
place 10uF and 0.1uF as close to VS/GND pins as possible
HDMI power
+5v @ 5A PSU
Rshunt: * do the math, is 0.005 is OK? * what material is better? metal strip / metal alloy / thick film
POWER SENSING
PCIe power
Coin cell battery + BMC power rail are responsible for powering both RTC chips
+5v @ 2A PSU

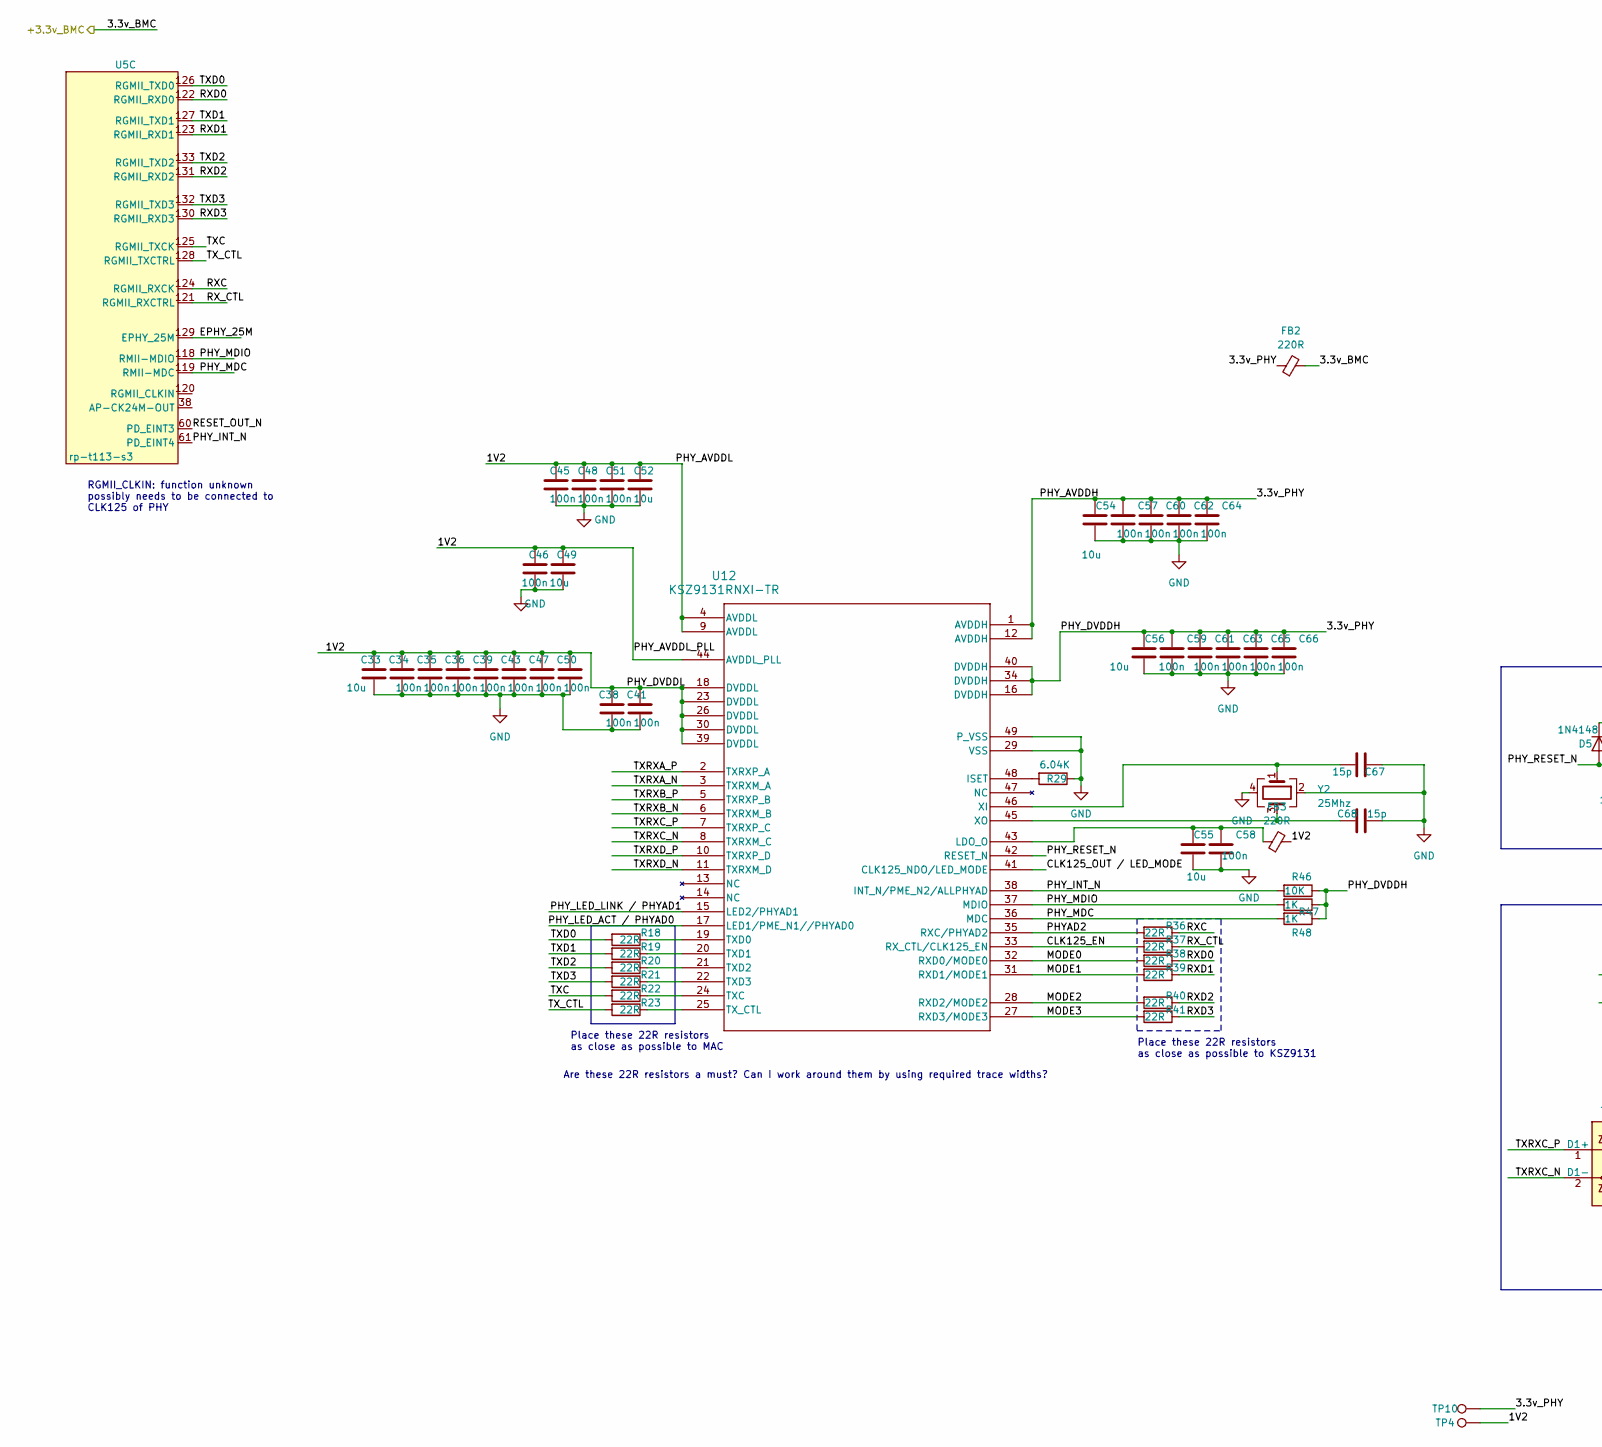
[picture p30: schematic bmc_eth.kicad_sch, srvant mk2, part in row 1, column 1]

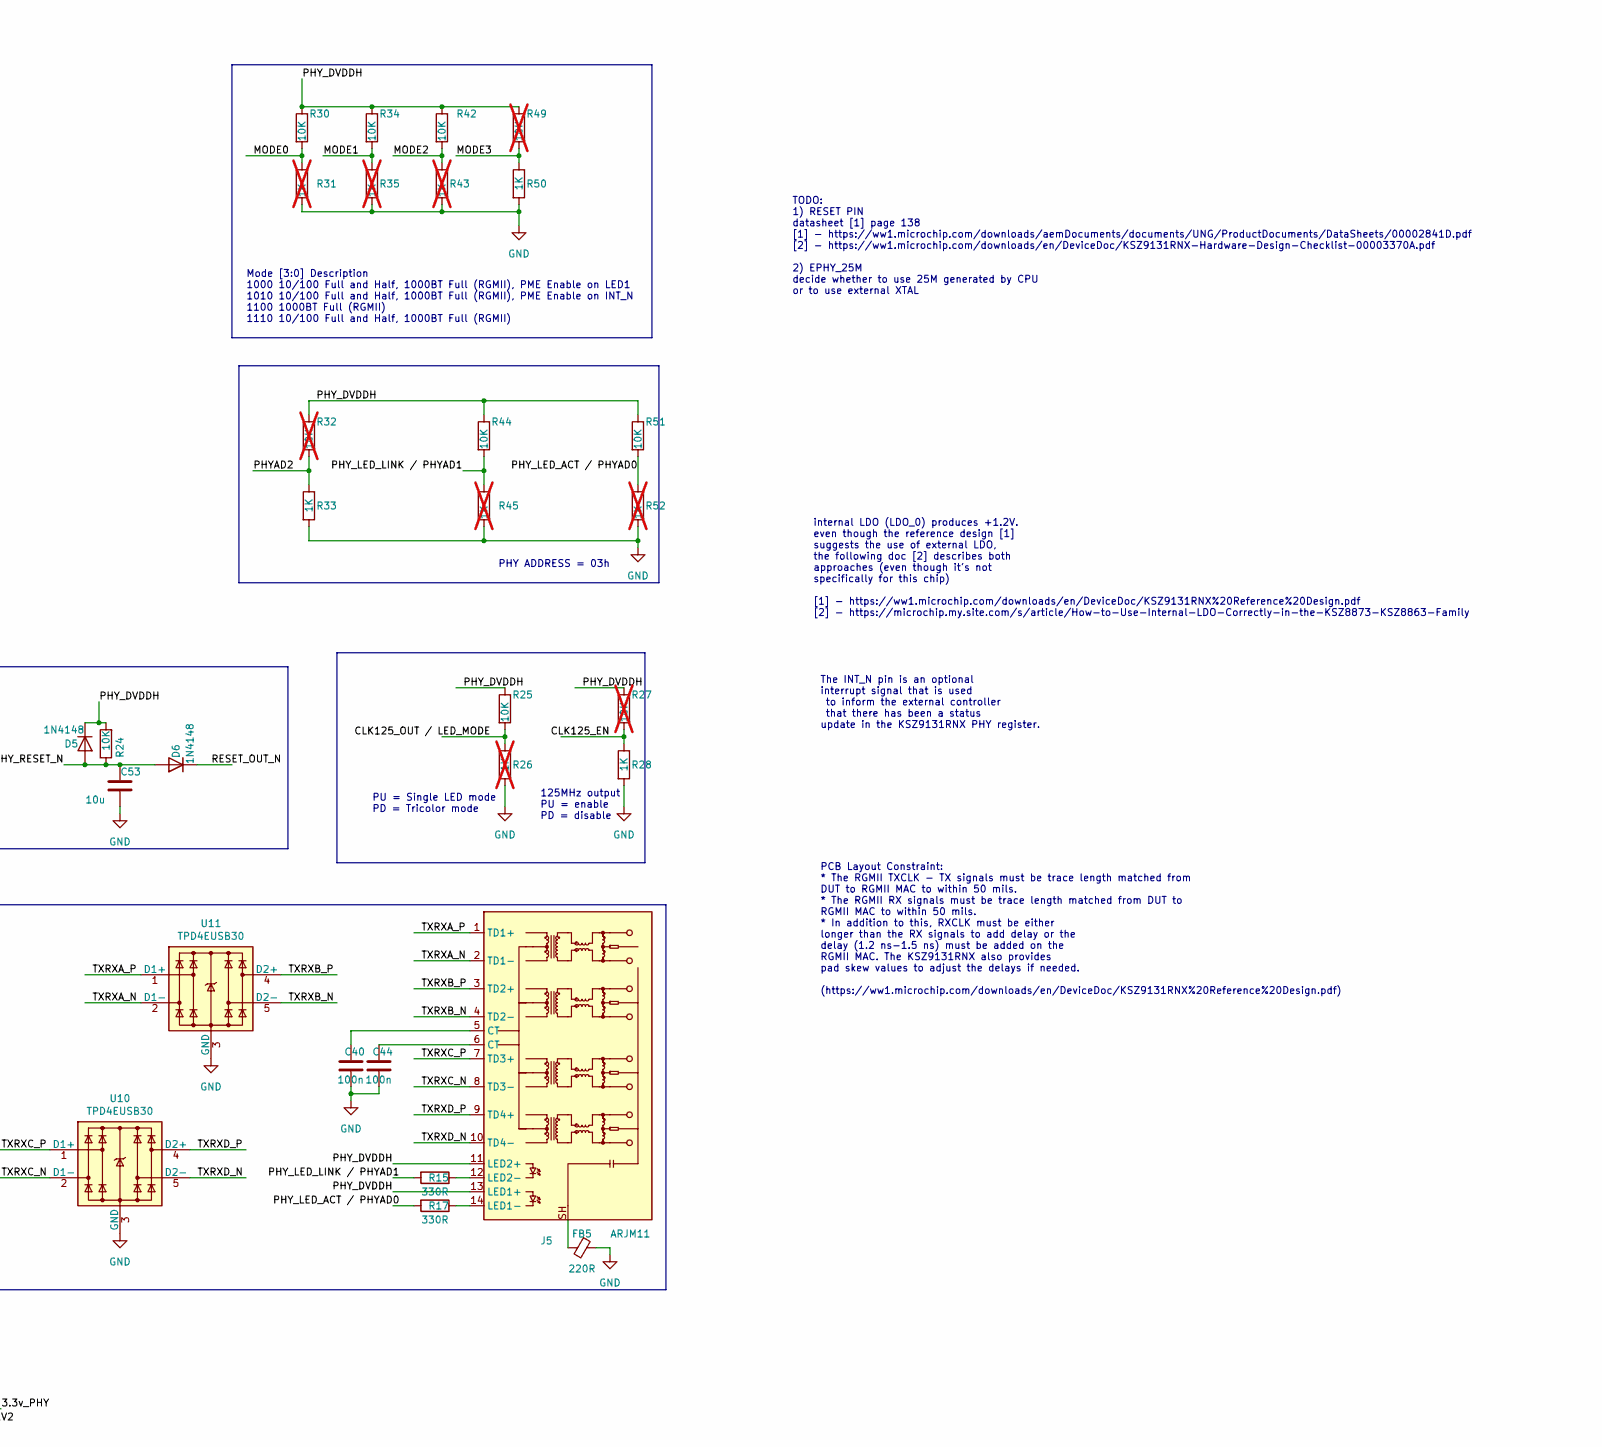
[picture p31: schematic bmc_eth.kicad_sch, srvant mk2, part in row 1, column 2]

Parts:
C33, C49, C52, C53, C54, C55, C56: 10u; C_0402_1005Metric; Part Description 10uF 10% or 20% 35V Ceramic Capacitor X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; digikey# 490-10505-1-ND
C34, C35, C36, C38, C39, C40, C41, C43, C44, C45, C46, C47, C48, C50, C51, C57, C58, C59, C60, C61, C62, C63, C64, C65, C66: 100n; C_0402_1005Metric; Part Description 0.1uF 10% 16V Ceramic Capacitor X7R 040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; digikey# EMK105B7104KV-F
C67, C68: 15p; C_0402_1005Metric; Part Description SMD Multilayer Ceramic Capacitor, 15 pF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; farnell# 2627389
D5, D6: 1N4148; D_SOD-523; mouser# 621-1N4148WT
FB2, FB3, FB5: 220R; R_0402_1005Metric; mouser# 81-BLM15PX221SH1D
J5: ARJM11; RJ45_Wuerth_7499111446_Horizontal
R15, R17: 330R; R_0402_1005Metric
R18, R19, R20, R21, R22, R23, R36, R37, R38, R39, R40, R41: 22R; R_0402_1005Metric
R24, R25, R30, R34, R42, R44, R46, R51: 10K; R_0402_1005Metric
R26, R31, R35, R43, R45, R52: 1K; R_0402_1005Metric; Part Description Resistor 1K M1005 1% 63mW; not fitted
R27, R32, R49: 10K; R_0402_1005Metric; not fitted
R28, R33, R47, R48, R50: 1K; R_0402_1005Metric; Part Description Resistor 1K M1005 1% 63mW
R29: 6.04K; R_0402_1005Metric; farnell# 3495661
TP4: 1v2; TestPoint_Pad_D1.0mm
TP10: PHY_AVDDH(3.3v); TestPoint_Pad_D1.0mm
U5: rp-t113-s3
U10, U11: TPD4EUSB30; USON-10_2.5x1.0mm_P0.5mm; Part Description Quad TVS diode for high speed signals (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
U12: KSZ9131RNXI-TR; QFN48_NX_MCH; mouser# 579-KSZ9131RNXC-TR; digikey# KSZ9131RNXC-TR
Y2: 25Mhz; Crystal_SMD_FOX_FQ7050-4Pin_7.0x5.0mm; farnell# 2854241

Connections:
/BMC ethernet/1V2: C33.1, C34.1, C35.1, C36.1, C38.1, C39.1, C41.1, C43.1, C45.1, C46.1, C47.1, C48.1, C49.1, C50.1, C51.1, C52.1, FB3.2, TP4.1, U12.4 (AVDDL), U12.9 (AVDDL), U12.18 (DVDDL), U12.23 (DVDDL), U12.26 (DVDDL), U12.30 (DVDDL), U12.39 (DVDDL), U12.44 (AVDDL_PLL)
/BMC ethernet/EPHY_25M: U5.129 (EPHY_25M)
/BMC ethernet/PHY_INT_N: R46.2, U5.61 (PD_EINT4), U12.38 (INT_N/PME_N2/ALLPHYAD)
/BMC ethernet/PHY_MDC: R48.2, U5.119 (RMII-MDC), U12.36 (MDC)
/BMC ethernet/PHY_MDIO: R47.2, U5.118 (RMII-MDIO), U12.37 (MDIO)
/BMC ethernet/PHY_RESET_N: C53.1, D5.2 (A), D6.2 (A), R24.1, U12.42 (RESET_N)
/BMC ethernet/RESET_OUT_N: D6.1 (K), U5.60 (PD_EINT3)
/BMC ethernet/RXC: R36.1, U5.124 (RGMII_RXCK)
/BMC ethernet/RXD0: R38.1, U5.122 (RGMII_RXD0)
/BMC ethernet/RXD1: R39.1, U5.123 (RGMII_RXD1)
/BMC ethernet/RXD2: R40.1, U5.131 (RGMII_RXD2)
/BMC ethernet/RXD3: R41.1, U5.130 (RGMII_RXD3)
/BMC ethernet/RX_CTL: R37.1, U5.121 (RGMII_RXCTRL)
/BMC ethernet/TXC: R22.2, U5.125 (RGMII_TXCK)
/BMC ethernet/TXD0: R18.2, U5.126 (RGMII_TXD0)
/BMC ethernet/TXD1: R19.2, U5.127 (RGMII_TXD1)
/BMC ethernet/TXD2: R20.2, U5.133 (RGMII_TXD2)
/BMC ethernet/TXD3: R21.2, U5.132 (RGMII_TXD3)
/BMC ethernet/TXRXA_N: J5.2 (TD1-), U11.2 (D1-), U11.9, U12.3 (TXRXM_A)
/BMC ethernet/TXRXA_P: J5.1 (TD1+), U11.1 (D1+), U11.10, U12.2 (TXRXP_A)
/BMC ethernet/TXRXB_N: J5.4 (TD2-), U11.5 (D2-), U11.6, U12.6 (TXRXM_B)
/BMC ethernet/TXRXB_P: J5.3 (TD2+), U11.4 (D2+), U11.7, U12.5 (TXRXP_B)
/BMC ethernet/TXRXC_N: J5.8 (TD3-), U10.2 (D1-), U10.9, U12.8 (TXRXM_C)
/BMC ethernet/TXRXC_P: J5.7 (TD3+), U10.1 (D1+), U10.10, U12.7 (TXRXP_C)
/BMC ethernet/TXRXD_N: J5.10 (TD4-), U10.5 (D2-), U10.6, U12.11 (TXRXM_D)
/BMC ethernet/TXRXD_P: J5.9 (TD4+), U10.4 (D2+), U10.7, U12.10 (TXRXP_D)
/BMC ethernet/TX_CTL: R23.2, U5.128 (RGMII_TXCTRL)
unnamed: C40.1, J5.5 (CT)
unnamed: C44.1, J5.6 (CT)
unnamed: FB5.2, J5.SH
unnamed: J5.14 (LED1-), R17.1
unnamed: J5.12 (LED2-), R15.1
unnamed: R29.2, U12.48 (ISET)
unnamed: C55.1, C58.1, FB3.1, U12.43 (LDO_O)
unnamed: R22.1, U12.24 (TXC)
unnamed: R18.1, U12.19 (TXD0)
unnamed: R19.1, U12.20 (TXD1)
unnamed: R20.1, U12.21 (TXD2)
unnamed: R21.1, U12.22 (TXD3)
unnamed: R23.1, U12.25 (TX_CTL)
unnamed: C67.2, U12.46 (XI), Y2.1
unnamed: C68.1, U12.45 (XO), Y2.3

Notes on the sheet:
Place these 22R resistors as close as possible to MAC
PCB Layout Constraint: * The RGMII TXCLK - TX signals must be trace length matched from DUT to RGMII MAC to within 50 mils. * The RGMII RX signals must be trace length matched from DUT to RGMII MAC to within 50 mils. * In addition to this, RXCLK must be either longer than the RX signals to add dela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
Place these 22R resistors as close as possible to KSZ9131
PHY ADDRESS = 03h
PU = Single LED mode PD = Tricolor mode
RGMII_CLKIN: function unknown possibly needs to be connected to CLK125 of PHY
Are these 22R resistors a must? Can I work around them by using required trace widths?
TODO: 1) RESET PIN datasheet [1] page 138 [1] - https://ww1.microchip.com/downloads/aemDocuments/documents/UNG/ProductDocuments/DataSheets/00002841D.pdf [2] - https://ww1.microchip.com/downloads/en/DeviceDoc/KSZ9131RNX-Hardware-Design-Checklist-00003370A.pdf 2) EPHY_25M decide whether to use 25M ge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
125MHz output PU = enable PD = disable
The INT_N pin is an optional interrupt signal that is used to inform the external controller that there has been a status update in the KSZ9131RNX PHY register.
internal LDO (LDO_0) produces +1.2V. even though the reference design [1] suggests the use of external LDO, the following doc [2] describes both approaches (even though it's not specifically for this chip) [1] - https://ww1.microchip.com/downloads/en/DeviceDoc/KSZ9131RNX%20Reference%20Design.pdf [2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
Mode [3:0] Description 1000 10/100 Full and Half, 1000BT Full (RGMII), PME Enable on LED1 1010 10/100 Full and Half, 1000BT Full (RGMII), PME Enable on INT_N 1100 1000BT Full (RGMII) 1110 10/100 Full and Half, 1000BT Full (RGMII)

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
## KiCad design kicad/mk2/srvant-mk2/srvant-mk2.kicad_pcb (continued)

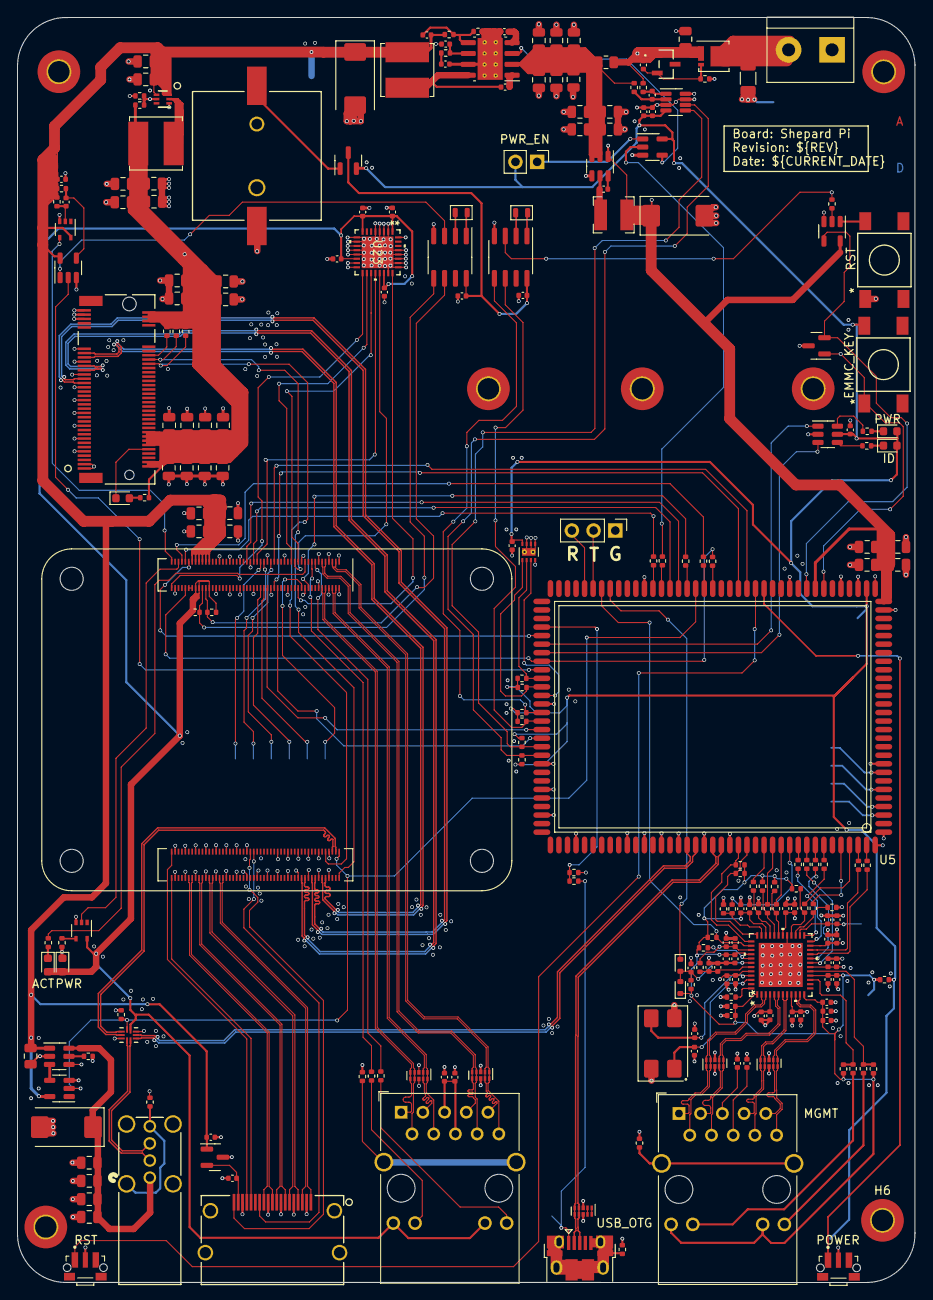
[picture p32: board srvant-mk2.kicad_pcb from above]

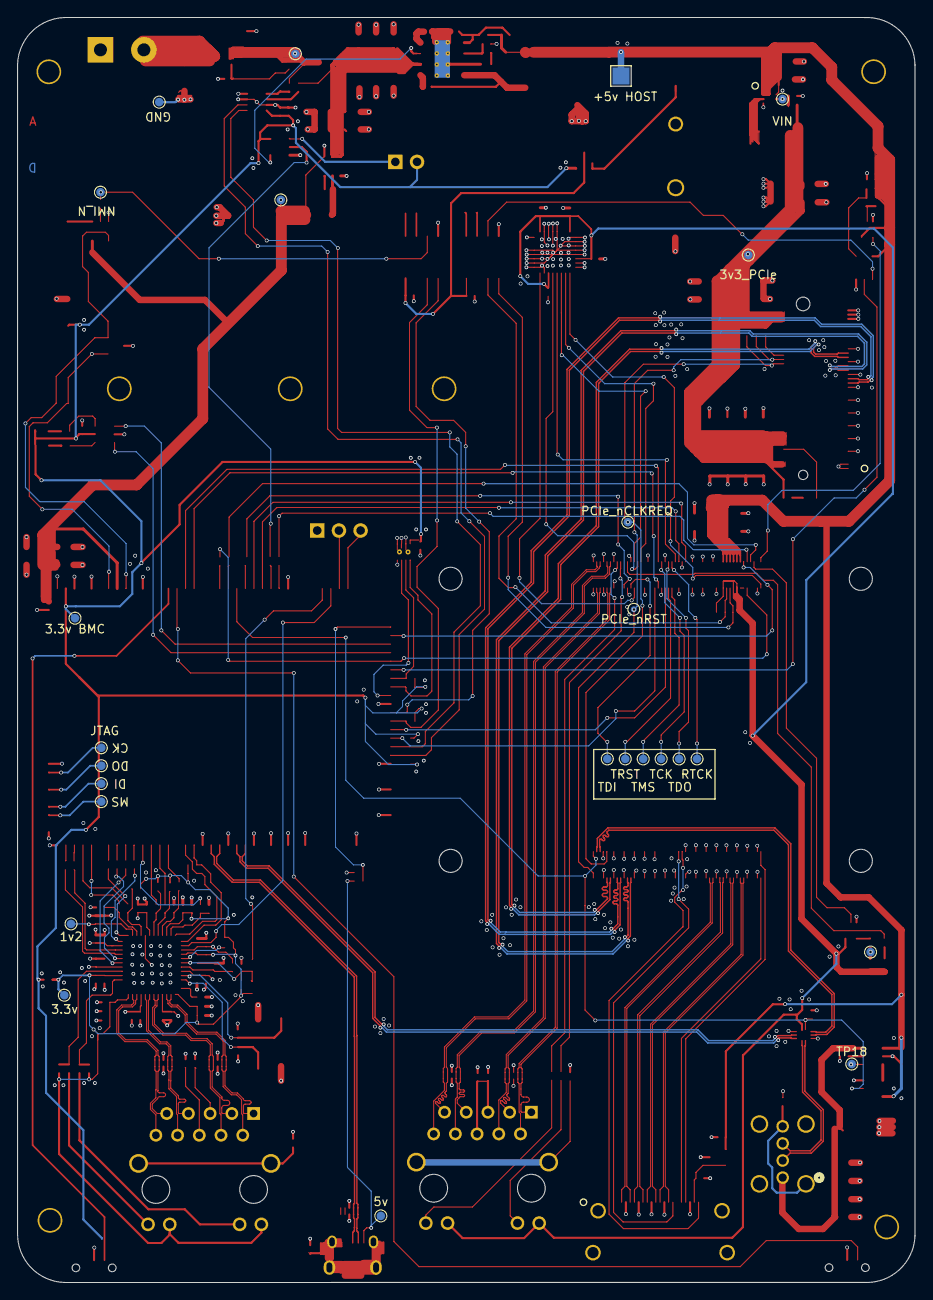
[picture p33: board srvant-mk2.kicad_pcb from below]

Board: 4 copper layers, 105.0 x 148.0 mm, 266 parts (25 on the bottom side), 206 nets.

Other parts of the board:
R3: 2K2; R_0402_1005Metric

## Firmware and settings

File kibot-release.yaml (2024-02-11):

kibot:
  version: 1

global:
  filters:
    - number: 1007
    - number: 1015
    - number: 58

import:
  - file: JLCPCB
    definitions:
      _KIBOT_MANF_DIR: Manufacturers/JLCPCB
      _KIBOT_POS_PRE_TRANSFORM: '[''_kicost_rename'', ''_rot_footprint'']'
      _KIBOT_BOM_ENABLED: 'false'

preflight:
  check_zone_fills: true
  # [boolean=false] Option for `run_erc`. ERC warnings are considered errors.
  erc_warnings: false
  # [boolean=false] Fill all zones again and save the PCB.
  fill_zones: true
  # [boolean=false] Runs the DRC (Distance Rules Check). To ensure we have a valid PCB.
  # The report file name is controlled by the global output pattern (%i=drc %x=txt).
  # Note that the KiCad 6+ *Test for parity between PCB and schematic* option is not supported.
  # If you need to check the parity use the `update_xml` preflight.
  # KiCad 6 introduced `warnings` they are currently counted be the `unconnected` counter of KiBot.
  # This will change in the future.
  run_drc: true
  # [boolean=false] Runs the ERC (Electrical Rules Check). To ensure the schematic is electrically correct.
  # The report file name is controlled by the global output pattern (%i=erc %x=txt).
  run_erc: false
  filters:
    - filter: 'We know some connectors extend outside the board'
      error: 'silk_over_copper'
      regex: 'clipped by solder mask'
    - filter: 'For some reason kibot shows this warning, but kicad doesnt.'
      error: 'track_dangling'
      regex: 'Track has unconnected end'
    - filter: "ignore kicad7 errors when 3d models are added"
      error: 'lib_footprint_mismatch'
      regex: "Footprint doesn't match copy in library"
  set_text_variables:
    # The revision will be the short git hash
    # We use ${git_hash} for the REV field in the worksheet (frame)
    - name: 'Comment1'
      variable: 'Comment1'
      expand_kibot_patterns: true
      command: 'git log -1 --format="%h" $KIBOT_PCB_NAME'
    - name: "REV"
      variable: "REV"
      expand_kibot_patterns: true
      command: 'git log -1 --format="%h" $KIBOT_SCH_NAME'
    # Coherent date and time for the schematic and PCB
    # This will be the time stamp of the files generation, not the commit times
    # We use `${date}` for the time field in the worksheet (frame)
    - name: 'date'
      command: 'date --iso-8601=minutes'
    # TODO: move 3d models to the root level of the repo and populate from CI
    - name: MK2_3D_MODELS
      text: './kicad/mk2/srvant-mk2/3D'
outputs:
#  - name: basic_diff_pcb
#    comment: PCB diff between the last two changes
#    type: diff
#    dir: diff
#    layers: 'all'
#    options:
#      old: KIBOT_TAG-1
#      old_type: git
#      new: HEAD
#      new_type: git
#      cache_dir: /work/.cache
#      add_link_id: true
#
#  - name: basic_diff_sch
#    comment: Schematic diff between the last two changes
#    type: diff
#    dir: diff
#    options:
#      old: KIBOT_TAG-1
#      old_type: git
#      new: HEAD
#      new_type: git
#      cache_dir: /kikit/.cache
#      add_link_id: true
#      pcb: false
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

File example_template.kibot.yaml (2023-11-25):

# ATTENTION! THIS ISN'T A FULLY FUNCTIONAL EXAMPLE.
# You should take portions of this example and edit the options to make
# them suitable for your use.
# This file is useful to know all the available options.
kibot:
  version: 1

preflight:
  # [dict] Annotates the PCB according to physical coordinates.
  # This preflight modifies the PCB and schematic, use it only in revision control environments.
  # Used to assign references according to footprint coordinates.
  # The project must be fully annotated first.
  annotate_pcb:
    top_main_axis: y
    top_main_ascending: true
    top_secondary_ascending: true
    top_start: 1
    bottom_main_axis: y
    bottom_main_ascending: true
    bottom_secondary_ascending: true
    bottom_start: 101
    use_position_of: 'footprint'
    grid: 1.0
  # [boolean=false] Annotates all power components.
  # This preflight modifies the schematic, use it only in revision control environments.
  # Used to solve ERC problems when using filters that remove power reference numbers.
  annotate_power: true
  # [boolean=false] Zones are filled before doing any operation involving PCB layers.
  # The original PCB remains unchanged. If you need to abort when the zone fill
  # creates significant changes to a layer use the CheckZoneFill internal template.
  check_zone_fills: true
  # [boolean=false] Option for `run_erc`. ERC warnings are considered errors.
  erc_warnings: false
  # [boolean=false] Fill all zones again and save the PCB.
  fill_zones: true
  # [list(dict)] A list of entries to filter out ERC/DRC messages.
  # Note that ignored errors will become KiBot warnings (i.e. `(W058) ...`).
  # To farther ignore these warnings use the `filters` option in the `global` section.
  filters:
    - filter: 'Filter description'
      error: '10'
      regex: 'Regular expression to match'
  # [boolean=false] Option for `run_drc`. Ignores the unconnected nets. Useful if you didn't finish the routing.
  # It will also ignore KiCad 6 warnings.
  ignore_unconnected: false
  # [dict] Replaces tags in the PCB. I.e. to insert the git hash or last revision date.
  # This is useful for KiCad 5, use `set_text_variables` when using KiCad 6.
  # This preflight modifies the PCB. Even when a back-up is done use it carefully.
  pcb_replace:
    date_command: 'git log -1 --format="%as" -- "$KIBOT_PCB_NAME"'
    replace_tags:
      - tag: '@git_hash@'
        command: 'git log -1 --format="%h" "$KIBOT_PCB_NAME"'
        before: 'Git hash: <'
        after: '>'
  # [boolean=false] Runs the DRC (Distance Rules Check). To ensure we have a valid PCB.
  # The report file name is controlled by the global output pattern (%i=drc %x=txt).
  # Note that the KiCad 6+ *Test for parity between PCB and schematic* option is not supported.
  # If you need to check the parity use the `update_xml` preflight.
  # KiCad 6 introduced `warnings` they are currently counted be the `unconnected` counter of KiBot.
  # This will change in the future.
  run_drc: true
  # [boolean=false] Runs the ERC (Electrical Rules Check). To ensure the schematic is electrically correct.
  # The report file name is controlled by the global output pattern (%i=erc %x=txt).
  run_erc: true
  # [dict] Replaces tags in the schematic. I.e. to insert the git hash or last revision date.
  # This is useful for KiCad 5, use `set_text_variables` when using KiCad 6.
  # This preflight modifies the schematics. Even when a back-up is done use it carefully.
  sch_replace:
    date_command: 'git log -1 --format="%as" -- "$KIBOT_SCH_NAME"'
    replace_tags:
      - tag: '@git_hash@'
        command: 'git log -1 --format="%h" "$KIBOT_SCH_NAME"'
        before: 'Git hash: <'
        after: '>'
  # [dict|list(dict)] Defines KiCad 6 variables.
  # They are expanded using ${VARIABLE}, and stored in the project file.
  # This preflight replaces `pcb_replace` and `sch_replace` when using KiCad 6.
  # The KiCad project file is modified.
  set_text_variables:
    - name: 'git_hash'
      command: 'git log -1 --format="%h" "$KIBOT_PCB_NAME"'
      before: 'Git hash: <'
      after: '>'
  # [boolean=false] Update the QR codes.
  # Complements the `qr_lib` output.
  # The KiCad 6 files and the KiCad 5 PCB needs manual update, generating a new library isn't enough.
  update_qr: true
  # [boolean=false|dict] Update the XML version of the BoM (Bill of Materials).
  # To ensure our generated BoM is up to date.
  # Note that this isn't needed when using the internal BoM generator (`bom`).
  # You can compare the PCB and schematic netlists using it.
  update_xml: true
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

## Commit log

2021-07-14 Add rev01 files
    Add datasheets, inspliration links, renders and kicad sources
    [CM4_GPIO.kicad_sch, CM4_HighSpeed.kicad_sch, PCIe.kicad_sch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]
2022-08-07 save state
    save state to try to migrate to kicad in linux
    [CM4_GPIO.kicad_sch, CM4_HighSpeed.kicad_sch, PCIe.kicad_sch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]
2023-06-24 fresh start
    [CM4_GPIO.kicad_sch, CM4_HighSpeed.kicad_sch, PCIe.kicad_sch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]
2023-07-31 work on schematics
    * add power rail
    * import CM4 related part
    * design most of the BMC-PHY part
    * create new library/footprint for rp t113-s3 SOM
    [CM4_GPIO.kicad_sch, CM4_HighSpeed.kicad_sch, PCIe.kicad_sch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]
2023-08-01 more progress
    [TLV62585DRLR-DRL0006A.stp, bmc.kicad_sch, cm4_gpio.kicad_sch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]
2023-11-25 save state
    [QFN32_SLB9670VQ20FW785XTMA1_INF.step, bmc.kicad_sch, bmc_eth.kicad_sch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]
2023-12-17 mostly wired, impedance control, etc
    Repositioned most of the components. Set impedance control based
    on jlcpcb calculator.
    Need to:
    * reposition ethernet port to allow mounting hole.
    * move power socket lower, reduce board size
    * fix the rest of DRC errors.
    [bmc.kicad_sch, bmc_eth.kicad_sch, cm4_main.kicad_sch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]
2023-12-19 remove old mk1 version
    [CM4_GPIO.kicad_sch, CM4_HighSpeed.kicad_sch, PCIe.kicad_sch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]
2023-12-19 resolve a bunch of DRC issues
    [srvant-mk2.kicad_pcb]
2023-12-22 change jack footprint, re-route minor thing.
    [srvant-mk2.kicad_pcb]
2023-12-22 fix descriptions, add 3dmodels.
    [bmc.kicad_sch, bmc_eth.kicad_sch, cm4_main.kicad_sch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]
2023-12-27 replace power jack, change board dimentions, small fixes
    [bmc_eth.kicad_sch, cm4_main.kicad_sch, power.kicad_sch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]
2023-12-29 add more 3d models
    [RJ45-c-5-2337992-3-a-3d.stp, srvant-mk2.kicad_pcb, usbmux_UQFN10_ONS.step]
2023-12-29 add more 3d models, add layer indication, update readme
    [POWERDI3333-8_UX_DIO.step, power.kicad_sch, srvant-mk2.kicad_pcb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]
2023-12-29 add rp-t113-s3 datasheets (cn), make CI happier
    [bmc.kicad_sch, bmc_eth.kicad_sch, cm4_gpio.kicad_sch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]
2023-12-29 Fix wrong capacitors placement of +5v_BMC, fix DRC issues
    [srvant-mk2.kicad_pcb]
2023-12-29 Replace filled zones with lots of traces
    [srvant-mk2.kicad_pcb]
2023-12-29 fix another filling place, render individual layers as pdfs/svgs
    [srvant-mk2.kicad_pcb]
2024-01-02 small fixes
    * fix unconnected vias near M2
    * fix missing resistors near rpi i2c
    * silkscreen fixes
    [cm4_main.kicad_sch, srvant-mk2.kicad_pcb]
2024-01-02 rework CI workflows
    Separate CI workflows.
    Run basic DRC and DIFFs on every commit.
    Run full set of actions including 3d and manufacture packages on tags
    only.
    [kibot-release.yaml]
2024-01-02 fix 3d models. again
    Once again assign all the 3d models to the components.
    [bmc.kicad_sch, bmc_eth.kicad_sch, srvant-mk2.kicad_pcb]
2024-01-02 Add an exception to the DRC about footprint mismatch
    In Kicad7, when you add a 3d model to the footprint that doesn't have
    one, warning is being generated.
    Proper way will be to make a copy of the footprint and add the model
    there.
    Ignore the warning for now.
    ref: https://forum.kicad.info/t/footprint-does-not-match-copy-in-library-when-3d-model-is-added/45176/3
    [kibot-release.yaml]
2024-01-27 reroute diff pairs
    Reroute all diff pairs after another run with the jlcpcb calculator.
    [bmc.kicad_sch, cm4_main.kicad_sch, power.kicad_sch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]
2024-01-31 small changes to routing
    [srvant-mk2.kicad_pcb]
2024-01-31 disable diffs for now
    [srvant-mk2.kicad_sch]
2024-02-11 lot's of small updates
    * fix the quartz footprint
    * fix wrong inductor in pcie power unit
    * fix lots of descriptions,uids
    [25mhz_70x50quarz.step, bmc.kicad_sch, bmc_eth.kicad_sch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]
2024-02-11 fix drc
    [srvant-mk2.kicad_pcb]
2024-02-11 fix variable substitution
    [bmc.kicad_sch, bmc_eth.kicad_sch, cm4_main.kicad_sch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]
2024-02-14 normalize border size
    [srvant-mk2.kicad_pcb]
2024-02-17 add jtag pads, improve power lines
    [bmc.kicad_sch, cm4_main.kicad_sch, srvant-mk2.kicad_pcb]
2024-02-18 pre-production: fix silkscreens
    [srvant-mk2.kicad_pcb]
2024-03-13 Fixes after manufacturing
    * Change footprint for the VIN capacitors. 10uf was supposed to be 0804
    not 0402. That required repositioning of both power converters.
    * Fix PWR_EN pin override (2.54mm instead of 1.0)
    * Change resistor values in voltage divider of AP64501SP. Values taken
    from RPI carrier board produce wrong voltage (~3.6v instead of 5v).
    * Add silkscreen labels around the LEDs.
    [power.kicad_sch, srvant-mk2.kicad_pcb]
2024-06-19 bmc usb id pin fix
    ID pin is supposed to be unconnected on a peripheral device.
    Connect usb_detect pin to VBUS using voltage divider (like in cm4 doc).
    [bmc.kicad_sch, bmc_eth.kicad_sch, cm4_main.kicad_sch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]
2024-06-19 bump kicad in ci
2025-01-03 redesign for the next version
    [FSUSB42MUX.step, SOT-23_DMP3098LQ_DIO.step, bmc.kicad_sch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]
2025-01-08 v1.5 draft
    [MTSSD03-67MSW337.STEP, cm4_main.kicad_sch, power.kicad_sch]
2025-01-08 bump kicad CI image, temp disable erc

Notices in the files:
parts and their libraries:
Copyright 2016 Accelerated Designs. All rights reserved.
